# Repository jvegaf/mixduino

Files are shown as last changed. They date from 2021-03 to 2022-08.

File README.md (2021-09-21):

# Mixduino
An evolution of Open Source DJ MIDI Controllers
## Main Features
- 3 Complete Channels Mixer 
- 2 Decks  
- Library Browser with song preview function
- 16 Control Pads with RGB Leds (8/Deck)
- FX Controls
- 75 mm pitch/tempo controls
- Multitouch bars instead Jog Wheels
- Compact size enought to take in a backpack (360x260mm) 
## Note
This project actually are WIP.
## Previews
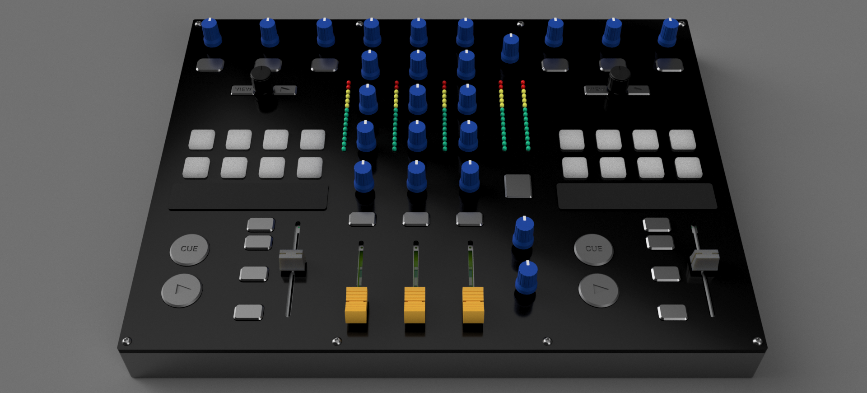
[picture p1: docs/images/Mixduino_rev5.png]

</br>
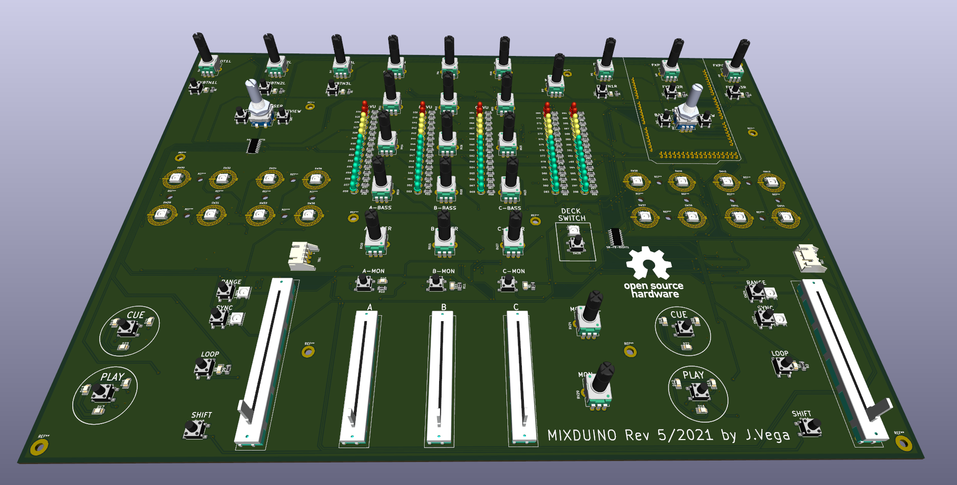
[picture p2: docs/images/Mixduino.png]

</br>
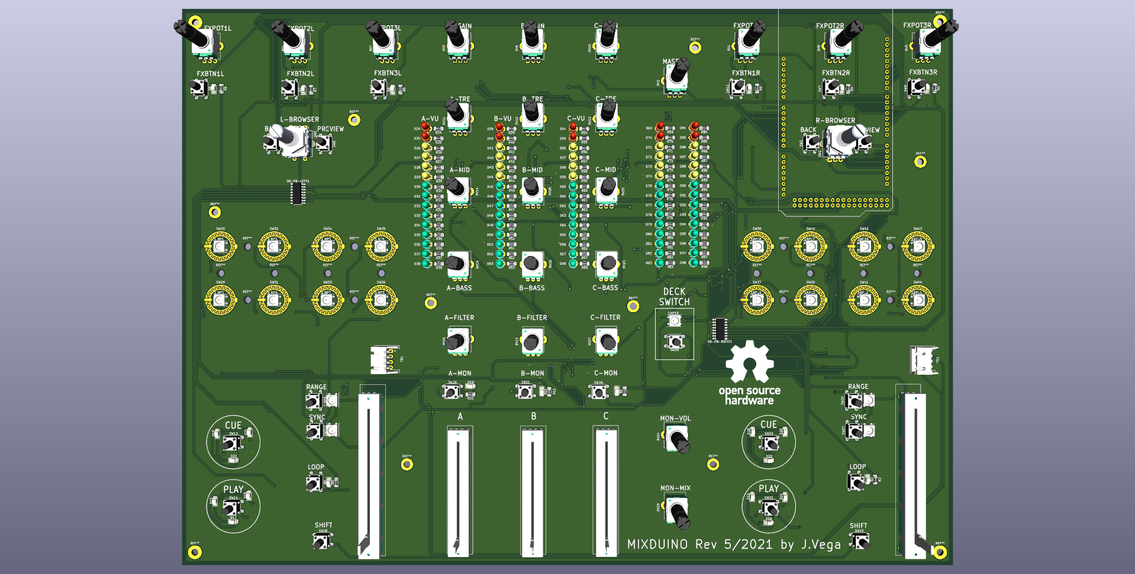
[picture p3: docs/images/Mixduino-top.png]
previewTop

</br>
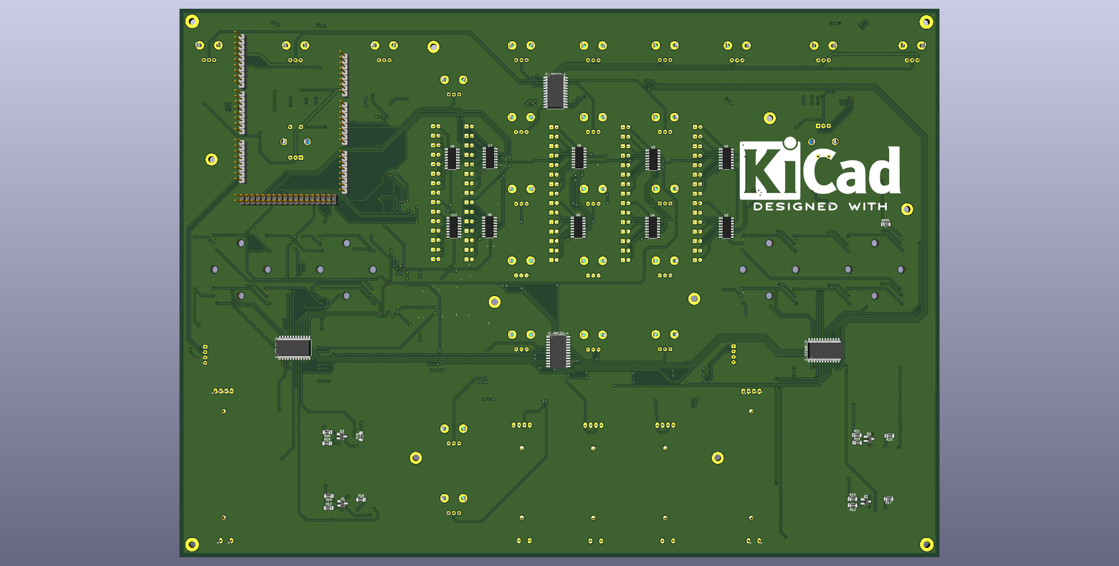
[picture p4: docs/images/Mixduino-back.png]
previewBack

</br>
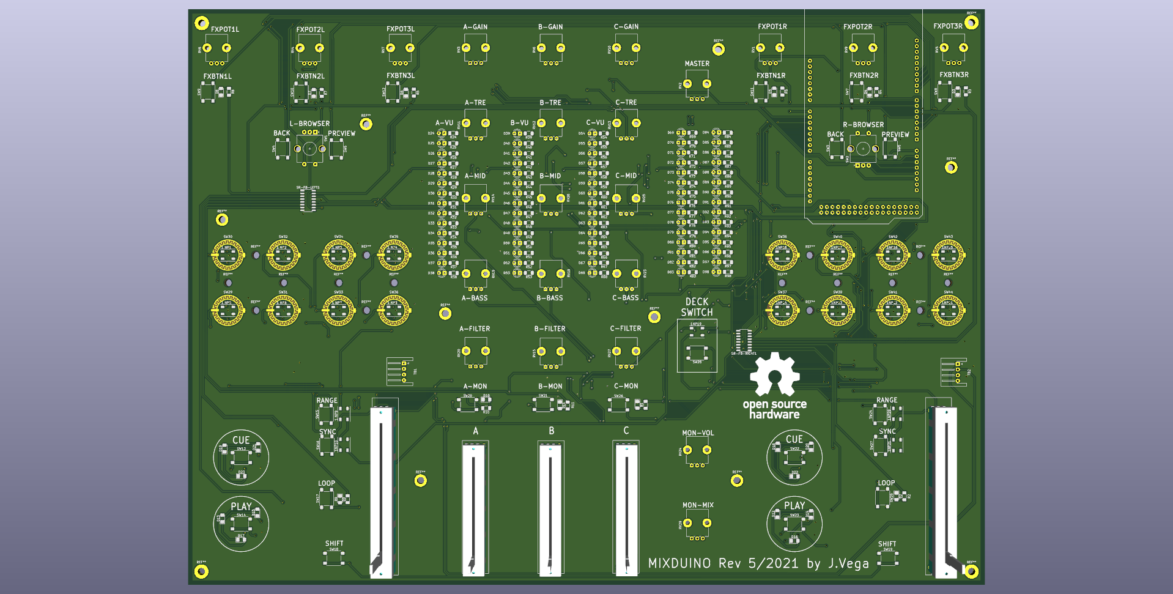
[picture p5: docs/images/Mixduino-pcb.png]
previewPCB


.
.
.

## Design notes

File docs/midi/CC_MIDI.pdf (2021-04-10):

Tabla de CC-MIDI | Carlos Mariño

www.carlosmarino.es

Tabla de Controladores MIDI

He dejado las nomenclaturas en inglés, tal y como os aparecerán en los

Manuales de vuestros instrumentos.

Cambios de Control y Modos (Status Bytes 176-191)

Número de Control

Función del Controlador

3rd Byte Value

Decimal | Binario | Hex | Valor

Usado
como
0 | 00000000 | 00 | Bank Select | 0-127 | MSB
1 | 00000001 | 01 | Modulation Wheel or Lever | 0-127 | MSB
2 | 00000010 | 02 | Breath Controller | 0-127 | MSB
3 | 00000011 | 03 | Indefinido | 0-127 | MSB
4 | 00000100 | 04 | Foot Controller | 0-127 | MSB
5 | 00000101 | 05 | Portamento Time | 0-127 | MSB
6 | 00000110 | 06 | Data Entry MSB | 0-127 | MSB
7 | 00000111 | 07 | Channel Volume (antes Main Volume) | 0-127 | MSB
8 | 00001000 | 08 | Balance | 0-127 | MSB
9 | 00001001 | 09 | Indefinido | 0-127 | MSB
10 | 00001010 | 0A | Pan | 0-127 | MSB
11 | 00001011 | 0B | Expression Controller | 0-127 | MSB
12 | 00001100 | 0C | Effect Control 1 | 0-127 | MSB
13 | 00001101 | 0D | Effect Control 2 | 0-127 | MSB
14 | 00001110 | 0E | Indefinido | 0-127 | MSB
15 | 00001111 | 0F | Indefinido | 0-127 | MSB
16 | 00010000 | 10 | Controlador de propósito general 1 | 0-127 | MSB
17 | 00010001 | 11 | Controlador de propósito general 2 | 0-127 | MSB
18 | 00010010 | 12 | Controlador de propósito general 3 | 0-127 | MSB
19 | 00010011 | 13 | Controlador de propósito general 4 | 0-127 | MSB

20 | 00010100 | 14 | Indefinido | 0-127 | MSB
21 | 00010101 | 15 | Indefinido | 0-127 | MSB
22 | 00010110 | 16 | Indefinido | 0-127 | MSB
23 | 00010111 | 17 | Indefinido | 0-127 | MSB
24 | 00011000 | 18 | Indefinido | 0-127 | MSB
25 | 00011001 | 19 | Indefinido | 0-127 | MSB
26 | 00011010 | 1A | Indefinido | 0-127 | MSB
27 | 00011011 | 1B | Indefinido | 0-127 | MSB
28 | 00011100 | 1C | Indefinido | 0-127 | MSB
29 | 00011101 | 1D | Indefinido | 0-127 | MSB
30 | 00011110 | 1E | Indefinido | 0-127 | MSB
31 | 00011111 | 1F | Indefinido | 0-127 | MSB
32 | 00100000 | 20 | LSB for Control 0 (Bank Select) | 0-127 | LSB
33 | 00100001 | 21 | LSB for Control 1 (Modulation Wheel or Lever) | 0-127 | LSB
34 | 00100010 | 22 | LSB for Control 2 (Breath Controller) | 0-127 | LSB
35 | 00100011 | 23 | LSB for Control 3 (Indefinido) | 0-127 | LSB
36 | 00100100 | 24 | LSB for Control 4 (Foot Controller) | 0-127 | LSB
37 | 00100101 | 25 | LSB for Control 5 (Portamento Time) | 0-127 | LSB
38 | 00100110 | 26 | LSB for Control 6 (Data Entry) | 0-127 | LSB
39 | 00100111 | 27 | LSB for Control 7 (Channel Volume, antes Main Volume) | 0-127 | LSB
40 | 00101000 | 28 | LSB for Control 8 (Balance) | 0-127 | LSB
41 | 00101001 | 29 | LSB for Control 9 (Indefinido) | 0-127 | LSB
42 | 00101010 | 2A | LSB for Control 10 (Pan) | 0-127 | LSB
43 | 00101011 | 2B | LSB for Control 11 (Expression Controller) | 0-127 | LSB
44 | 00101100 | 2C | LSB for Control 12 (Effect control 1) | 0-127 | LSB
45 | 00101101 | 2D | LSB for Control 13 (Effect control 2) | 0-127 | LSB

46 | 00101110 | 2E | LSB for Control 14 (Indefinido) | 0-127 | LSB
47 | 00101111 | 2F | LSB for Control 15 (Indefinido) | 0-127 | LSB
48 | 00110000 | 30 | LSB for Control 16 (Controlador de propósito general 1) | 0-127 | LSB
49 | 00110001 | 31 | LSB for Control 17 (Controlador de propósito general 2) | 0-127 | LSB
50 | 00110010 | 32 | LSB for Control 18 (Controlador de propósito general 3) | 0-127 | LSB
51 | 00110011 | 33 | LSB for Control 19 (Controlador de propósito general 4) | 0-127 | LSB
52 | 00110100 | 34 | LSB for Control 20 (Indefinido) | 0-127 | LSB
53 | 00110101 | 35 | LSB for Control 21 (Indefinido) | 0-127 | LSB
54 | 00110110 | 36 | LSB for Control 22 (Indefinido) | 0-127 | LSB
55 | 00110111 | 37 | LSB for Control 23 (Indefinido) | 0-127 | LSB
56 | 00111000 | 38 | LSB for Control 24 (Indefinido) | 0-127 | LSB
57 | 00111001 | 39 | LSB for Control 25 (Indefinido) | 0-127 | LSB
58 | 00111010 | 3A | LSB for Control 26 (Indefinido) | 0-127 | LSB
59 | 00111011 | 3B | LSB for Control 27 (Indefinido) | 0-127 | LSB
60 | 00111100 | 3C | LSB for Control 28 (Indefinido) | 0-127 | LSB
61 | 00111101 | 3D | LSB for Control 29 (Indefinido) | 0-127 | LSB
62 | 00111110 | 3E | LSB for Control 30 (Indefinido) | 0-127 | LSB
63 | 00111111 | 3F | LSB for Control 31 (Indefinido) | 0-127 | LSB
64 | 01000000 | 40 | Damper Pedal on/off (Sustain) | ≤63 off, ≥64 on | ---
65 | 01000001 | 41 | Portamento On/Off | ≤63 off, ≥64 on | ---
66 | 01000010 | 42 | Sostenuto On/Off | ≤63 off, ≥64 on | ---
67 | 01000011 | 43 | Soft Pedal On/Off | ≤63 off, ≥64 on | ---
68 | 01000100 | 44 | Legato Footswitch | ≤63 Normal, ≥64 Legato | ---
69 | 01000101 | 45 | Hold 2 | ≤63 off, ≥64 on | ---

70 | 01000110 | 46 | Controlador de sonido 1 (default: Sound
Variation) | 0-127 | LSB
71 | 01000111 | 47 | Controlador de sonido 2 (default: Timbre/Harmonic Intens.) | 0-127 | LSB
72 | 01001000 | 48 | Controlador de sonido 3 (default: Release Time) | 0-127 | LSB
73 | 01001001 | 49 | Controlador de sonido 4 (default: Attack Time) | 0-127 | LSB
74 | 01001010 | 4A | Controlador de sonido 5 (default: Brightness) | 0-127 | LSB
75 | 01001011 | 4B | Controlador de sonido 6 (default: Decay Time - ver MMA RP-021) | 0-127 | LSB
76 | 01001100 | 4C | Controlador de sonido 7 (default: Vibrato Rate - ver MMA RP-021) | 0-127 | LSB
77 | 01001101 | 4D | Controlador de sonido 8 (default: Vibrato Profundidad - ver MMA RP-021) | 0-127 | LSB
78 | 01001110 | 4E | Controlador de sonido 9 (default: Vibrato Delay - ver MMA RP-021) | 0-127 | LSB
79 | 01001111 | 4F | Controlador de sonido 10 (default Indefinido - ver MMA RP-021) | 0-127 | LSB
80 | 01010000 | 50 | Controlador de propósito general 5 | 0-127 | LSB
81 | 01010001 | 51 | Controlador de propósito general 6 | 0-127 | LSB
82 | 01010010 | 52 | Controlador de propósito general 7 | 0-127 | LSB
83 | 01010011 | 53 | Controlador de propósito general 8 | 0-127 | LSB
84 | 01010100 | 54 | Portamento Control | 0-127 | LSB
85 | 01010101 | 55 | Indefinido | --- | ---
86 | 01010110 | 56 | Indefinido | --- | ---
87 | 01010111 | 57 | Indefinido | --- | ---
88 | 01011000 | 58 | High Resolution Velocity Prefix | 0-127 | LSB
89 | 01011001 | 59 | Indefinido | --- | ---

90 | 01011010 | 5A | Indefinido | --- | ---
91 | 01011011 | 5B | Efectos 1 Profundidad (default: Nivel de envío de reverb - ver MMA RP-023) (anteriormente profundidad de efectos externos) | 0-127 | ---
92 | 01011100 | 5C | Efectos 2 Profundidad (antes Tremolo Profundidad) | 0-127 | ---
93 | 01011101 | 5D | Efectos 3 Profundidad (default: Nivel de Chorus - ver MMA RP-023) (anteriormente profundidad de efectos externos) | 0-127 | ---
94 | 01011110 | 5E | Efectos 4 Profundidad (antes Celeste [Detune] Profundidad) | 0-127 | ---
95 | 01011111 | 5F | Efectos 5 Profundidad (antes Phaser Profundidad) | 0-127 | ---
96 | 01100000 | 60 | Data Increment (Data Entry +1) (ver MMA RP-018) | N/A | ---
97 | 01100001 | 61 | Data Decrement (Data Entry -1) (ver MMA RP-018) | N/A | ---
98 | 01100010 | 62 | Número de parámetro no registrado (NRPN) - LSB | 0-127 | LSB
99 | 01100011 | 63 | Número de parámetro no registrado (NRPN) - MSB | 0-127 | MSB
100 | 01100100 | 64 | Número de parámetro registrado (RPN) -LSB* | 0-127 | LSB
101 | 01100101 | 65 | Número de parámetro registrado (RPN) -MSB* | 0-127 | MSB
102 | 01100110 | 66 | Indefinido | --- | ---
103 | 01100111 | 67 | Indefinido | --- | ---
104 | 01101000 | 68 | Indefinido | --- | ---
105 | 01101001 | 69 | Indefinido | --- | ---
106 | 01101010 | 6A | Indefinido | --- | ---

107 | 01101011 | 6B | Indefinido | --- | ---
108 | 01101100 | 6C | Indefinido | --- | ---
109 | 01101101 | 6D | Indefinido | --- | ---
110 | 01101110 | 6E | Indefinido | --- | ---
111 | 01101111 | 6F | Indefinido | --- | ---
112 | 01110000 | 70 | Indefinido | --- | ---
113 | 01110001 | 71 | Indefinido | --- | ---
114 | 01110010 | 72 | Indefinido | --- | ---
115 | 01110011 | 73 | Indefinido | --- | ---
116 | 01110100 | 74 | Indefinido | --- | ---
117 | 01110101 | 75 | Indefinido | --- | ---
118 | 01110110 | 76 | Indefinido | --- | ---
119 | 01110111 | 77 | Indefinido | --- | ---
Nota: | Los números de controlador 120-127 están reservados para los mensajes de modo de canal, que, en lugar de controlar los parámetros de sonido, afectan el modo de funcionamiento del canal. (Ver también la Tabla 1.)
120 | 01111000 | 78 | [Mensaje en modo canal] All Sound Off | 0 | ---
121 | 01111001 | 79 | [Mensaje en modo canal] Reset All Controllers (Ver MMA RP-015) | 0 | ---
122 | 01111010 | 7A | [Mensaje en modo canal] Local Control On/Off | 0 off, 127 on | ---
123 | 01111011 | 7B | [Mensaje en modo canal] All Notes Off | 0 | ---
124 | 01111100 | 7C | [Mensaje en modo canal] Omni Mode Off (+ all notes off) | 0 | ---
125 | 01111101 | 7D | [Mensaje en modo canal] Omni Mode On (+ all notes off) | 0

126 | 01111110 | 7E | [Mensaje en modo canal] Mono Mode On (+ poly off, + all notes off) | Nota: Esto equivale a la cantidad de canales, o cero si la cantidad de canales es igual a la cantidad de voces en el receptor. | ---
127 | 01111111 | 7F | [Mensaje en modo canal] Poly Mode On (+ mono off, +all notes off) | 0 | ---

Números de parámetros registrados

Para establecer o cambiar el valor de un parámetro registrado:

1. Envía dos mensajes de cambio de control usando los números de control 101 (65H) y 100 (64H) para seleccionar el número de parámetro registrado deseado, como se indica en la siguiente tabla.
2. Para establecer el parámetro registrado seleccionado en un valor específico, envíe un mensaje de cambio de control al controlador MSB de entrada de datos (número de control 6). Si el parámetro registrado seleccionado requiere que se establezca el LSB, envíe otro mensaje de cambio de control al controlador LSB de entrada de datos (número de control 38).
3. Para realizar un ajuste relativo al valor actual del parámetro registrado seleccionado, usa los controladores Data Increment o Data Decrement (Números de control 96 y 97).
Número de Parámetro | Función de Parámetro | Valor de Entrada
MSB: Control 101 (65H) Value | LSB: Control 100 (64H) Value
00H | 00H | Pitch Bend Sensitivity | MSB = +/- semitones LSB =+/--cents
| 01H | Channel Fine Tuning (antes Fine Tuning - ver MMA RP-022) | Resolution 100/8192 cents 00H 00H = -100 cents 40H 00H = A440 7FH 7FH = +100 cents

| 02H | Channel Coarse Tuning (antes Coarse Tuning - ver MMA RP-022) | Only MSB used Resolution 100 cents 00H = -6400 cents 40H = A440 7FH = +6300 cents
| 03H | Tuning Program Change | Tuning Program Number
| 04H | Tuning Bank Select | Tuning Bank Number
| 05H | Modulation Profundidad Range (ver MMA General MIDI Level 2 Specification) | For GM2, defined in GM2 Specification. For other systems, defined by manufacturer
... | ... | Todos RESERVADOS para la futura definición de MMA | ...
3DH (61) | Three Dimensional Controlador de sonidos
| 00H | AZIMUTH ANGLE | Ver RP-049
| 01H | ELEVATION ANGLE | Ver RP-049
| 02H | GAIN | Ver RP-049
| 03H | DISTANCE RATIO | Ver RP-049
| 04H | MAXIMUM DISTANCE | Ver RP-049
| 05H | GAIN AT MAXIMUM DISTANCE | Ver RP-049
| 06H | REFERENCE DISTANCE RATIO | Ver RP-049
| 07H | PAN SPREAD ANGLE | Ver RP-049
| 08H | ROLL ANGLE | Ver RP-049
... | ... | All RESERVED for future MMA Definition | ...
7FH | 7FH | Número de función nulo para RPN / NRPN | Al establecer RPN en 7FH, 7FH se deshabilitarán los controles de entrada de datos, incremento de datos y reducción de datos hasta que se seleccione un nuevo RPN o NRPN.

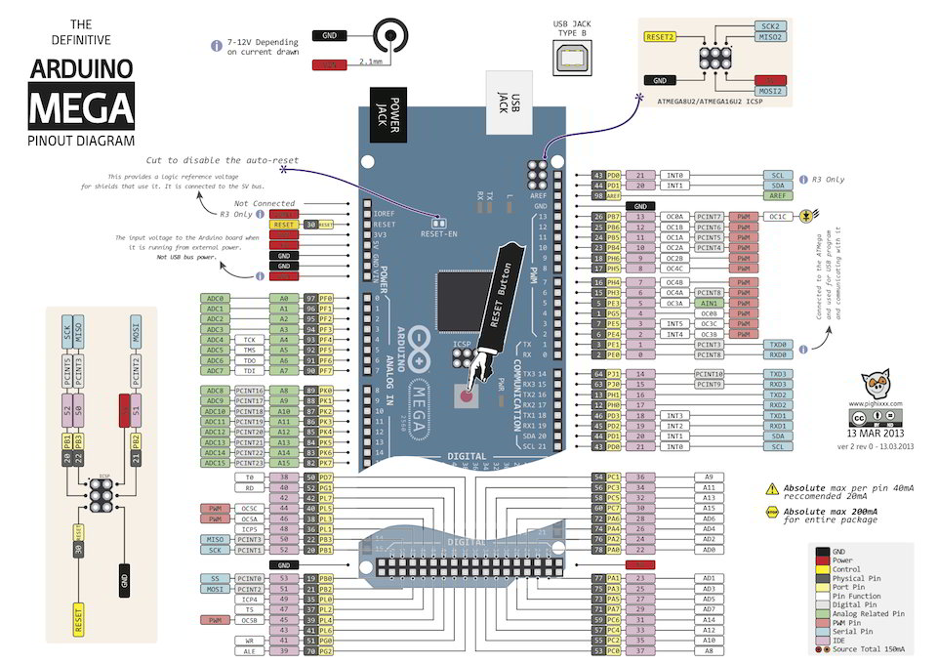
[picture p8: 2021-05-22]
docs/pinouts/ardunio_mega_pinout.jpg

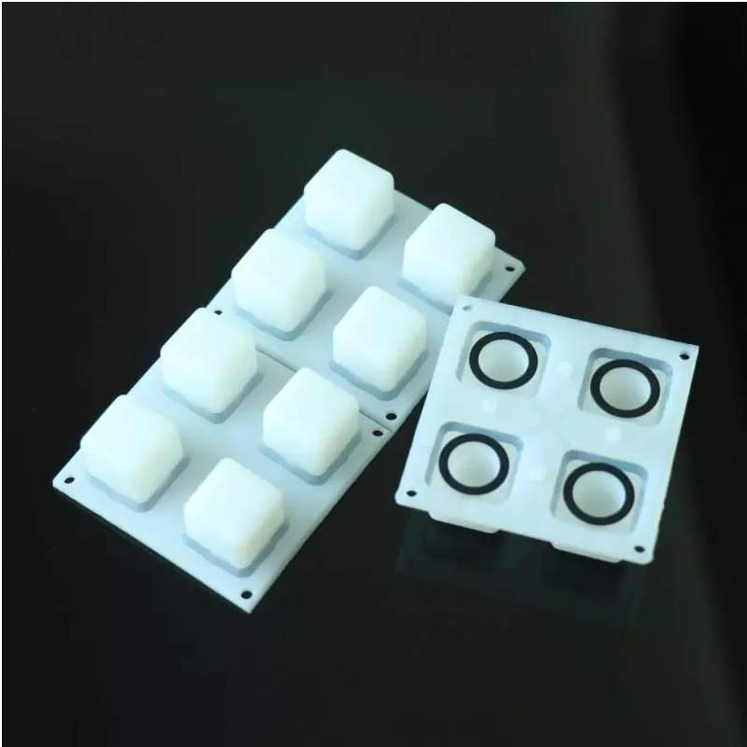
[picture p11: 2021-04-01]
docs/pads/pads.png

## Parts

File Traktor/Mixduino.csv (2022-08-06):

#
#Page 0: (Mixduino R5)
#
Device | Id | Type | TraktorCommand | AssignmentExpression | ConditionExpression | Interaction | MappedTo | Comment
0 | 65 | In | Volume Adjust | Deck A |  | Fader / Knob - Direct | Ch11.CC.012
0 | 198 | Out | Monitor Cue On [Off; On] | Deck A |  | LED - Output | Ch06.Note.D#2
0 | 199 | Out | Monitor Cue On [Off; On] | Deck B |  | LED - Output | Ch06.Note.E2
0 | 200 | Out | Monitor Cue On [Off; On] | Deck C |  | LED - Output | Ch06.Note.F2
0 | 190 | In | Deck Focus Selector = B | Global | M1=1 | Button - Direct | Ch06.Note.G-1
0 | 191 | In | Deck Focus Selector = C | Global | M1=0 | Button - Direct | Ch06.Note.G-1
0 | 215 | Out | Sync On [Off; On] | Deck A |  | LED - Output | Ch14.CC.009
0 | 100 | Out | Hotcue 2 Type [None; Loop] | Deck C | M1=1 | LED - Output | Ch14.CC.011
0 | 101 | Out | Hotcue 3 Type [None; Loop] | Deck C | M1=1 | LED - Output | Ch14.CC.012
0 | 223 | Out | Sync On [Off; On] | Deck C | M1=1 | LED - Output | Ch14.CC.020
0 | 219 | Out | Sync On [Off; On] | Deck B | M1=0 | LED - Output | Ch14.CC.020
0 | 220 | Out | Tempo Range Selector [8%; 100%] | Deck B | M1=0 | LED - Output | Ch14.CC.019
0 | 390 | In | Tempo Range Selector = 10% | Deck A | Tempo Range [Deck A]=8% | Button - Direct | Ch05.Note.F-1
0 | 391 | In | Tempo Range Selector = 100% | Deck A | Tempo Range [Deck A]=10% | Button - Direct | Ch05.Note.F-1
0 | 392 | In | Tempo Range Selector = 8% | Deck A | Tempo Range [Deck A]=100% | Button - Direct | Ch05.Note.F-1
0 | 393 | In | Tempo Range Selector = 10% | Deck B | Tempo Range [Deck B]=8% AND M1=0 | Button - Direct | Ch06.Note.D-1
0 | 394 | In | Tempo Range Selector = 100% | Deck B | Tempo Range [Deck B]=10% AND M1=0 | Button - Direct | Ch06.Note.D-1
0 | 395 | In | Tempo Range Selector = 8% | Deck B | Tempo Range [Deck B]=100% AND M1=0 | Button - Direct | Ch06.Note.D-1
0 | 396 | In | Tempo Range Selector = 10% | Deck C | Tempo Range [Deck C]=8% AND M1=1 | Button - Direct | Ch06.Note.D-1
0 | 397 | In | Tempo Range Selector = 100% | Deck C | Tempo Range [Deck C]=10% AND M1=1 | Button - Direct | Ch06.Note.D-1
0 | 398 | In | Tempo Range Selector = 8% | Deck C | Tempo Range [Deck C]=100% AND M1=1 | Button - Direct | Ch06.Note.D-1
0 | 399 | In | Tempo Bend [Hold] = Up | Deck A | M2=1 | Button - Hold | Ch05.Note.F-1
0 | 400 | In | Tempo Bend [Hold] = Down | Deck A | M2=1 | Button - Hold | Ch05.Note.E-1
0 | 401 | In | Tempo Bend [Hold] = Up | Deck B | M2=1 AND M1=0 | Button - Hold | Ch06.Note.D-1
0 | 402 | In | Tempo Bend [Hold] = Down | Deck B | M2=1 AND M1=0 | Button - Hold | Ch06.Note.F#-1
0 | 403 | In | Tempo Bend [Hold] = Up | Deck C | M2=1 AND M1=1 | Button - Hold | Ch06.Note.D-1
0 | 404 | In | Tempo Bend [Hold] = Down | Deck C | M2=1 AND M1=1 | Button - Hold | Ch06.Note.F#-1
0 | 384 | Out | Tempo Range Selector [8%; 100%] | Deck C | M1=1 | LED - Output | Ch14.CC.019
0 | 387 | Out | Tempo Range Selector [8%; 100%] | Deck A |  | LED - Output | Ch14.CC.008
0 | 192 | Out | Deck Focus Selector [B; D] | Global |  | LED - Output | Ch14.CC.018
0 | 131 | In | Select Up/Down (Browser List) | Global | M2=0 | Encoder - Relative | Ch01.CC.014_I
0 | 132 | In | Select Up/Down (Browser Tree) | Global | M2=1 | Encoder - Relative | Ch01.CC.014_I
0 | 66 | In | Mixer FX Adjust | Deck A |  | Fader / Knob - Direct | Ch11.CC.023
0 | 67 | In | Mixer FX Adjust | Deck B |  | Fader / Knob - Direct | Ch11.CC.022
0 | 68 | In | Mixer FX Adjust | Deck C |  | Fader / Knob - Direct | Ch11.CC.014
0 | 69 | In | Low Adjust | Deck A |  | Fader / Knob - Direct | Ch11.CC.016
0 | 70 | In | Low Adjust | Deck B |  | Fader / Knob - Direct | Ch11.CC.018
0 | 71 | In | Low Adjust | Deck C |  | Fader / Knob - Direct | Ch11.CC.021
0 | 72 | In | Mid Adjust | Deck A |  | Fader / Knob - Direct | Ch11.CC.017
0 | 73 | In | Mid Adjust | Deck B |  | Fader / Knob - Direct | Ch11.CC.019
0 | 74 | In | Mid Adjust | Deck C |  | Fader / Knob - Direct | Ch11.CC.020
0 | 75 | In | Gain Adjust (Mixer) | Deck C |  | Fader / Knob - Direct | Ch11.CC.005
0 | 76 | In | Gain Adjust (Mixer) | Deck B |  | Fader / Knob - Direct | Ch11.CC.004
0 | 77 | In | Gain Adjust (Mixer) | Deck A |  | Fader / Knob - Direct | Ch11.CC.003
0 | 58 | In | Tempo Adjust | Deck B | M1=0 | Fader / Knob - Direct | Ch11.CC.013_I
0 | 59 | In | Tempo Adjust | Deck C | M1=1 | Fader / Knob - Direct | Ch11.CC.013_I
0 | 60 | In | Tempo Adjust | Deck A |  | Fader / Knob - Direct | Ch11.CC.024_I
0 | 61 | In | Monitor Mix Adjust | Global |  | Fader / Knob - Direct | Ch11.CC.025
0 | 62 | In | Monitor Volume Adjust | Global |  | Fader / Knob - Direct | Ch11.CC.015
0 | 63 | In | Volume Adjust | Deck C |  | Fader / Knob - Direct | Ch11.CC.026
0 | 64 | In | Volume Adjust | Deck B |  | Fader / Knob - Direct | Ch11.CC.011
0 | 84 | In | High Adjust | Deck C |  | Fader / Knob - Direct | Ch11.CC.010
0 | 85 | In | High Adjust | Deck B |  | Fader / Knob - Direct | Ch11.CC.009
0 | 86 | In | High Adjust | Deck A |  | Fader / Knob - Direct | Ch11.CC.008
0 | 87 | In | Master Volume Adjust | Global |  | Fader / Knob - Direct | Ch11.CC.028
0 | 88 | Out | Hotcue 2 Type [None; Loop] | Deck A |  | LED - Output | Ch14.CC.001
0 | 93 | Out | Hotcue 3 Type [None; Loop] | Deck A |  | LED - Output | Ch14.CC.002
0 | 94 | Out | Hotcue 4 Type [None; Loop] | Deck A |  | LED - Output | Ch14.CC.003
0 | 95 | Out | Hotcue 5 Type [None; Loop] | Deck A |  | LED - Output | Ch14.CC.004
0 | 96 | Out | Hotcue 6 Type [None; Loop] | Deck A |  | LED - Output | Ch14.CC.005
0 | 97 | Out | Hotcue 7 Type [None; Loop] | Deck A |  | LED - Output | Ch14.CC.006
0 | 98 | Out | Hotcue 8 Type [None; Loop] | Deck A |  | LED - Output | Ch14.CC.007
0 | 99 | Out | Hotcue 1 Type [None; Loop] | Deck A |  | LED - Output | Ch14.CC.000
0 | 102 | Out | Hotcue 4 Type [None; Loop] | Deck C | M1=1 | LED - Output | Ch14.CC.013
0 | 103 | Out | Hotcue 5 Type [None; Loop] | Deck C | M1=1 | LED - Output | Ch14.CC.014
0 | 105 | Out | Hotcue 6 Type [None; Loop] | Deck C | M1=1 | LED - Output | Ch14.CC.015
0 | 106 | Out | Hotcue 7 Type [None; Loop] | Deck C | M1=1 | LED - Output | Ch14.CC.016
0 | 107 | Out | Hotcue 8 Type [None; Loop] | Deck C | M1=1 | LED - Output | Ch14.CC.017
0 | 108 | Out | Hotcue 1 Type [None; Loop] | Deck C | M1=1 | LED - Output | Ch14.CC.010
0 | 182 | Out | Hotcue 2 Type [None; Loop] | Deck B | M1=0 | LED - Output | Ch14.CC.011
0 | 183 | Out | Hotcue 3 Type [None; Loop] | Deck B | M1=0 | LED - Output | Ch14.CC.012
0 | 184 | Out | Hotcue 4 Type [None; Loop] | Deck B | M1=0 | LED - Output | Ch14.CC.013
0 | 185 | Out | Hotcue 5 Type [None; Loop] | Deck B | M1=0 | LED - Output | Ch14.CC.014
0 | 186 | Out | Hotcue 6 Type [None; Loop] | Deck B | M1=0 | LED - Output | Ch14.CC.015
0 | 187 | Out | Hotcue 7 Type [None; Loop] | Deck B | M1=0 | LED - Output | Ch14.CC.016
0 | 188 | Out | Hotcue 8 Type [None; Loop] | Deck B | M1=0 | LED - Output | Ch14.CC.017
0 | 189 | Out | Hotcue 1 Type [None; Loop] | Deck B | M1=0 | LED - Output | Ch14.CC.010
0 | 110 | In | Play/Pause (Deck Common) [Toggle] | Deck A |  | Button - Toggle | Ch05.Note.F#-1
0 | 112 | In | Cue [Hold] | Deck A |  | Button - Hold | Ch05.Note.G-1
0 | 114 | In | Sync On [Toggle] | Deck A |  | Button - Toggle | Ch05.Note.E-1
0 | 133 | In | Play/Pause (Deck Common) [Toggle] | Deck B | M1=0 | Button - Toggle | Ch06.Note.C#-1
0 | 134 | In | Cue [Hold] | Deck B | M1=0 | Button - Hold | Ch06.Note.C-1
0 | 135 | In | Sync On [Toggle] | Deck B | M1=0 | Button - Toggle | Ch06.Note.F#-1
0 | 136 | In | Play/Pause (Deck Common) [Toggle] | Deck C | M1=1 | Button - Toggle | Ch06.Note.C#-1
0 | 137 | In | Cue [Hold] | Deck C | M1=1 | Button - Hold | Ch06.Note.C-1
0 | 138 | In | Sync On [Toggle] | Deck C | M1=1 | Button - Toggle | Ch06.Note.F#-1
0 | 118 | In | Only Browser On [Toggle] | Global |  | Button - Toggle | Ch07.Note.A-1
0 | 263 | In | Only Browser On = Off | Global |  | Button - Direct | Ch07.Note.E-1
0 | 265 | In | Only Browser On = Off | Global |  | Button - Direct | Ch07.Note.D#-1
0 | 120 | In | Modifier #1 = 1 | Global | M1=0 | Button - Direct | Ch06.Note.G-1 | switch deck B - C
0 | 125 | In | Modifier #1 = 0 | Global | M1=1 | Button - Direct | Ch06.Note.G-1
0 | 126 | In | Modifier #2 [Hold] = 1 | Global |  | Button - Hold | Ch05.Note.D-1 | shift
0 | 146 | In | Load Selected (Deck Common) | Deck A |  | Button - Trigger | Ch07.Note.E-1
0 | 150 | In | Load Selected (Deck Common) | Deck B | M1=0 | Button - Trigger | Ch07.Note.D#-1
0 | 154 | In | Load Selected (Deck Common) | Deck C | M1=1 | Button - Trigger | Ch07.Note.D#-1
0 | 179 | In | Monitor Cue On [Toggle] | Deck A |  | Button - Toggle | Ch05.Note.C#-1
0 | 181 | In | Monitor Cue On [Toggle] | Deck C |  | Button - Toggle | Ch06.Note.F-1
0 | 180 | In | Monitor Cue On [Toggle] | Deck B |  | Button - Toggle | Ch05.Note.C-1
0 | 258 | Out | Deck Is Loaded [Off; On] | Deck A |  | LED - Output | Ch01.Note.C3
0 | 271 | Out | Deck Is Loaded [Off; On] | Deck B | M1=0 | LED - Output | Ch01.Note.C#3
0 | 279 | Out | Deck Is Loaded [Off; On] | Deck C | M1=1 | LED - Output | Ch01.Note.C#3
0 | 283 | Out | Beat Phase [-0.1; 0.1] | Deck A |  | LED - Output | Ch01.Note.C3
0 | 286 | Out | Beat Phase [-0.1; 0.1] | Deck B | M1=0 | LED - Output | Ch01.Note.C#3
0 | 288 | Out | Beat Phase [-0.1; 0.1] | Deck C | M1=1 | LED - Output | Ch01.Note.C#3
0 | 290 | Out | Loop Active On [Off; On] | Deck A |  | LED - Output | Ch06.Note.E3
0 | 293 | Out | Loop Active On [Off; On] | Deck B | M1=0 | LED - Output | Ch06.Note.F3
0 | 295 | Out | Loop Active On [Off; On] | Deck C | M1=1 | LED - Output | Ch06.Note.F3
0 | 296 | In | Loop Active On [Toggle] | Deck A |  | Button - Toggle | Ch05.Note.D#-1
0 | 299 | In | Loop Active On [Toggle] | Deck B | M1=0 | Button - Toggle | Ch06.Note.D#-1
0 | 301 | In | Loop Active On [Toggle] | Deck C | M1=1 | Button - Toggle | Ch06.Note.D#-1
0 | 308 | In | Loop Size Select + Set = 4 | Deck A | Is In Active Loop [Deck A]=Off | Button - Direct | Ch05.Note.D#-1
0 | 311 | In | Loop Size Select + Set = 4 | Deck B | M1=0 AND Is In Active Loop [Deck B]=Off | Button - Direct | Ch06.Note.D#-1
0 | 313 | In | Loop Size Select + Set = 4 | Deck C | M1=1 AND Is In Active Loop [Deck C]=Off | Button - Direct | Ch06.Note.D#-1
0 | 334 | In | Jog Turn | Deck A |  | Fader / Knob - Relative | Ch07.CC.014 | touchbar left
0 | 336 | In | Jog Turn | Deck B | M1=0 | Fader / Knob - Relative | Ch07.CC.015 | touchbar right
0 | 338 | In | Jog Turn | Deck C | M1=1 | Fader / Knob - Relative | Ch07.CC.015 | touchbar right
0 | 405 | Out | Deck Pre-Fader Level (L+R) [0; 1] | Deck A |  | LED - Output | Ch12.CC.000
0 | 406 | Out | Deck Pre-Fader Level (L+R) [0; 1] | Deck B |  | LED - Output | Ch12.CC.001
0 | 407 | Out | Deck Pre-Fader Level (L+R) [0; 1] | Deck C |  | LED - Output | Ch12.CC.002
0 | 408 | Out | Master Out Level (L) [0; 1] | Global |  | LED - Output | Ch12.CC.003
0 | 409 | Out | Master Out Level (R) [0; 1] | Global |  | LED - Output | Ch12.CC.004
0 | 428 | Out | Deck Is Loaded [Off; On] | Deck A |  | LED - Output | Ch01.Note.D3
0 | 431 | Out | Deck Is Loaded [Off; On] | Deck B | M1=0 | LED - Output | Ch01.Note.D#3
0 | 433 | Out | Deck Is Loaded [Off; On] | Deck C | M1=1 | LED - Output | Ch01.Note.D#3
0 | 434 | In | Dry/Wet Adjust (FX Unit) | FX Unit 1 |  | Fader / Knob - Direct | Ch11.CC.000
0 | 435 | In | Knob 1 | FX Unit 1 |  | Fader / Knob - Direct | Ch11.CC.001
0 | 436 | In | Knob 2 | FX Unit 1 |  | Fader / Knob - Direct | Ch11.CC.002
0 | 437 | In | Button 1 [Toggle] | FX Unit 1 |  | Button - Toggle | Ch07.Note.F-1
0 | 438 | Out | Button 1 [Off; On] | FX Unit 1 |  | LED - Output | Ch06.Note.G2
0 | 439 | In | Button 2 [Toggle] | FX Unit 1 |  | Button - Toggle | Ch07.Note.F#-1
0 | 440 | Out | Button 2 [Off; On] | FX Unit 1 |  | LED - Output | Ch06.Note.G#2
0 | 441 | In | Dry/Wet Adjust (FX Unit) | FX Unit 2 |  | Fader / Knob - Direct | Ch11.CC.027
0 | 442 | In | Knob 1 | FX Unit 2 |  | Fader / Knob - Direct | Ch11.CC.006
0 | 443 | In | Knob 2 | FX Unit 2 |  | Fader / Knob - Direct | Ch11.CC.007
0 | 444 | In | Button 1 [Toggle] | FX Unit 2 |  | Button - Toggle | Ch07.Note.C-1
0 | 445 | Out | Button 1 [Off; On] | FX Unit 2 |  | LED - Output | Ch06.Note.A#2
0 | 446 | In | Button 2 [Toggle] | FX Unit 2 |  | Button - Toggle | Ch07.Note.C#-1
0 | 447 | Out | Button 2 [Off; On] | FX Unit 2 |  | LED - Output | Ch06.Note.B2
#
#Page 1: (Mixduino Pads)
#
1 | 1 | In | Select/Set+Store Hotcue [Hold] = Hotcue1 | Deck A |  | Button - Hold | Ch05.Note.C0
1 | 37 | In | Tempo Bend [Hold] = Down | Deck A |  | Button - Hold | Ch05.Note.E2
1 | 38 | In | Tempo Bend [Hold] = Up | Deck A |  | Button - Hold | Ch05.Note.F2
1 | 17 | In | Loop Size Selector = 1/2 | Deck A |  | Button - Direct | Ch05.Note.G#0
1 | 18 | In | Loop Size Selector = 1 | Deck A |  | Button - Direct | Ch05.Note.A0
1 | 19 | In | Loop Size Selector = 2 | Deck A |  | Button - Direct | Ch05.Note.A#0
1 | 20 | In | Loop Size Selector = 4 | Deck A |  | Button - Direct | Ch05.Note.B0
1 | 21 | In | Loop Size Selector = 8 | Deck A |  | Button - Direct | Ch05.Note.C1
1 | 22 | In | Loop Size Selector = 16 | Deck A |  | Button - Direct | Ch05.Note.C#1
1 | 23 | In | Loop Size Selector = 32 | Deck A |  | Button - Direct | Ch05.Note.D1
1 | 24 | In | Loop Active On = Off | Deck A |  | Button - Direct | Ch05.Note.D#1
1 | 25 | In | Beatjump [Hold] = -1/2 | Deck A |  | Button - Hold | Ch05.Note.E1
1 | 26 | In | Beatjump [Hold] = -1 | Deck A |  | Button - Hold | Ch05.Note.F1
1 | 27 | In | Beatjump [Hold] = -4 | Deck A |  | Button - Hold | Ch05.Note.F#1
1 | 28 | In | Beatjump [Hold] = -16 | Deck A |  | Button - Hold | Ch05.Note.G1
1 | 29 | In | Beatjump [Hold] = +1/2 | Deck A |  | Button - Hold | Ch05.Note.G#1
1 | 30 | In | Beatjump [Hold] = +1 | Deck A |  | Button - Hold | Ch05.Note.A1
1 | 31 | In | Beatjump [Hold] = +4 | Deck A |  | Button - Hold | Ch05.Note.A#1
1 | 32 | In | Beatjump [Hold] = +16 | Deck A |  | Button - Hold | Ch05.Note.B1
1 | 33 | In | Tempo Range Selector = 8% | Deck A |  | Button - Direct | Ch05.Note.C2
1 | 34 | In | Tempo Range Selector = 8% | Deck A |  | Button - Direct | Ch05.Note.C#2
1 | 35 | In | Tempo Range Selector = 8% | Deck A |  | Button - Direct | Ch05.Note.D2
1 | 36 | In | Tempo Range Selector = 8% | Deck A |  | Button - Direct | Ch05.Note.D#2
1 | 2 | In | Select/Set+Store Hotcue [Hold] = Hotcue2 | Deck A |  | Button - Hold | Ch05.Note.C#0
1 | 3 | In | Select/Set+Store Hotcue [Hold] = Hotcue3 | Deck A |  | Button - Hold | Ch05.Note.D0
1 | 4 | In | Select/Set+Store Hotcue [Hold] = Hotcue4 | Deck A |  | Button - Hold | Ch05.Note.D#0
1 | 5 | In | Select/Set+Store Hotcue [Hold] = Hotcue5 | Deck A |  | Button - Hold | Ch05.Note.E0
1 | 6 | In | Select/Set+Store Hotcue [Hold] = Hotcue6 | Deck A |  | Button - Hold | Ch05.Note.F0
1 | 7 | In | Select/Set+Store Hotcue [Hold] = Hotcue7 | Deck A |  | Button - Hold | Ch05.Note.F#0
1 | 8 | In | Select/Set+Store Hotcue [Hold] = Hotcue8 | Deck A |  | Button - Hold | Ch05.Note.G0
1 | 9 | In | Delete Hotcue = Hotcue1 | Deck A | M2=1 | Button - Direct | Ch05.Note.C0
1 | 10 | In | Delete Hotcue = Hotcue2 | Deck A | M2=1 | Button - Direct | Ch05.Note.C#0
1 | 11 | In | Delete Hotcue = Hotcue3 | Deck A | M2=1 | Button - Direct | Ch05.Note.D0
1 | 12 | In | Delete Hotcue = Hotcue4 | Deck A | M2=1 | Button - Direct | Ch05.Note.D#0
1 | 13 | In | Delete Hotcue = Hotcue5 | Deck A | M2=1 | Button - Direct | Ch05.Note.E0
1 | 14 | In | Delete Hotcue = Hotcue6 | Deck A | M2=1 | Button - Direct | Ch05.Note.F0
1 | 15 | In | Delete Hotcue = Hotcue7 | Deck A | M2=1 | Button - Direct | Ch05.Note.F#0
1 | 16 | In | Delete Hotcue = Hotcue8 | Deck A | M2=1 | Button - Direct | Ch05.Note.G0
1 | 39 | In | Select/Set+Store Hotcue [Hold] = Hotcue1 | Deck B |  | Button - Hold | Ch06.Note.C0
1 | 40 | In | Tempo Bend [Hold] = Down | Deck B |  | Button - Hold | Ch06.Note.E2
1 | 41 | In | Tempo Bend [Hold] = Up | Deck B |  | Button - Hold | Ch06.Note.F2
1 | 42 | In | Loop Size Selector = 1/2 | Deck B |  | Button - Direct | Ch06.Note.G#0
1 | 43 | In | Loop Size Selector = 1 | Deck B |  | Button - Direct | Ch06.Note.A0
1 | 44 | In | Loop Size Selector = 2 | Deck B |  | Button - Direct | Ch06.Note.A#0
1 | 45 | In | Loop Size Selector = 4 | Deck B |  | Button - Direct | Ch06.Note.B0
1 | 46 | In | Loop Size Selector = 8 | Deck B |  | Button - Direct | Ch06.Note.C1
1 | 47 | In | Loop Size Selector = 16 | Deck B |  | Button - Direct | Ch06.Note.C#1
1 | 48 | In | Loop Size Selector = 32 | Deck B |  | Button - Direct | Ch06.Note.D1
1 | 49 | In | Loop Active On = Off | Deck B |  | Button - Direct | Ch06.Note.D#1
1 | 50 | In | Beatjump [Hold] = -1/2 | Deck B |  | Button - Hold | Ch06.Note.E1
1 | 51 | In | Beatjump [Hold] = -1 | Deck B |  | Button - Hold | Ch06.Note.F1
1 | 52 | In | Beatjump [Hold] = -4 | Deck B |  | Button - Hold | Ch06.Note.F#1
1 | 53 | In | Beatjump [Hold] = -16 | Deck B |  | Button - Hold | Ch06.Note.G1
1 | 54 | In | Beatjump [Hold] = +1/2 | Deck B |  | Button - Hold | Ch06.Note.G#1
1 | 55 | In | Beatjump [Hold] = +1 | Deck B |  | Button - Hold | Ch06.Note.A1
1 | 56 | In | Beatjump [Hold] = +4 | Deck B |  | Button - Hold | Ch06.Note.A#1
1 | 57 | In | Beatjump [Hold] = +16 | Deck B |  | Button - Hold | Ch06.Note.B1
1 | 58 | In | Tempo Range Selector = 8% | Deck B |  | Button - Direct | Ch06.Note.C2
1 | 59 | In | Tempo Range Selector = 8% | Deck B |  | Button - Direct | Ch06.Note.C#2
1 | 60 | In | Tempo Range Selector = 8% | Deck B |  | Button - Direct | Ch06.Note.D2
1 | 61 | In | Tempo Range Selector = 8% | Deck B |  | Button - Direct | Ch06.Note.D#2
1 | 62 | In | Select/Set+Store Hotcue [Hold] = Hotcue2 | Deck B |  | Button - Hold | Ch06.Note.C#0
1 | 63 | In | Select/Set+Store Hotcue [Hold] = Hotcue3 | Deck B |  | Button - Hold | Ch06.Note.D0
1 | 64 | In | Select/Set+Store Hotcue [Hold] = Hotcue4 | Deck B |  | Button - Hold | Ch06.Note.D#0
1 | 65 | In | Select/Set+Store Hotcue [Hold] = Hotcue5 | Deck B |  | Button - Hold | Ch06.Note.E0
1 | 66 | In | Select/Set+Store Hotcue [Hold] = Hotcue6 | Deck B |  | Button - Hold | Ch06.Note.F0
1 | 67 | In | Select/Set+Store Hotcue [Hold] = Hotcue7 | Deck B |  | Button - Hold | Ch06.Note.F#0
1 | 68 | In | Select/Set+Store Hotcue [Hold] = Hotcue8 | Deck B |  | Button - Hold | Ch06.Note.G0
1 | 69 | In | Delete Hotcue = Hotcue1 | Deck B | M2=1 | Button - Direct | Ch06.Note.C0
1 | 70 | In | Delete Hotcue = Hotcue2 | Deck B | M2=1 | Button - Direct | Ch06.Note.C#0
1 | 71 | In | Delete Hotcue = Hotcue3 | Deck B | M2=1 | Button - Direct | Ch06.Note.D0
1 | 72 | In | Delete Hotcue = Hotcue4 | Deck B | M2=1 | Button - Direct | Ch06.Note.D#0
1 | 73 | In | Delete Hotcue = Hotcue5 | Deck B | M2=1 | Button - Direct | Ch06.Note.E0
1 | 74 | In | Delete Hotcue = Hotcue6 | Deck B | M2=1 | Button - Direct | Ch06.Note.F0
1 | 75 | In | Delete Hotcue = Hotcue7 | Deck B | M2=1 | Button - Direct | Ch06.Note.F#0
1 | 76 | In | Delete Hotcue = Hotcue8 | Deck B | M2=1 | Button - Direct | Ch06.Note.G0
1 | 77 | In | Select/Set+Store Hotcue [Hold] = Hotcue1 | Deck C |  | Button - Hold | Ch07.Note.C0
1 | 78 | In | Tempo Bend [Hold] = Down | Deck C |  | Button - Hold | Ch07.Note.E2
1 | 79 | In | Tempo Bend [Hold] = Up | Deck C |  | Button - Hold | Ch07.Note.F2
1 | 80 | In | Loop Size Selector = 1/2 | Deck C |  | Button - Direct | Ch07.Note.G#0
1 | 81 | In | Loop Size Selector = 1 | Deck C |  | Button - Direct | Ch07.Note.A0
1 | 82 | In | Loop Size Selector = 2 | Deck C |  | Button - Direct | Ch07.Note.A#0
1 | 83 | In | Loop Size Selector = 4 | Deck C |  | Button - Direct | Ch07.Note.B0
1 | 84 | In | Loop Size Selector = 8 | Deck C |  | Button - Direct | Ch07.Note.C1
1 | 85 | In | Loop Size Selector = 16 | Deck C |  | Button - Direct | Ch07.Note.C#1
1 | 86 | In | Loop Size Selector = 32 | Deck C |  | Button - Direct | Ch07.Note.D1
1 | 87 | In | Loop Active On = Off | Deck C |  | Button - Direct | Ch07.Note.D#1
1 | 88 | In | Beatjump [Hold] = -1/2 | Deck C |  | Button - Hold | Ch07.Note.E1
1 | 89 | In | Beatjump [Hold] = -1 | Deck C |  | Button - Hold | Ch07.Note.F1
1 | 90 | In | Beatjump [Hold] = -4 | Deck C |  | Button - Hold | Ch07.Note.F#1
1 | 91 | In | Beatjump [Hold] = -16 | Deck C |  | Button - Hold | Ch07.Note.G1
1 | 92 | In | Beatjump [Hold] = +1/2 | Deck C |  | Button - Hold | Ch07.Note.G#1
1 | 93 | In | Beatjump [Hold] = +1 | Deck C |  | Button - Hold | Ch07.Note.A1
1 | 94 | In | Beatjump [Hold] = +4 | Deck C |  | Button - Hold | Ch07.Note.A#1
1 | 95 | In | Beatjump [Hold] = +16 | Deck C |  | Button - Hold | Ch07.Note.B1
1 | 96 | In | Tempo Range Selector = 8% | Deck C |  | Button - Direct | Ch07.Note.C2
1 | 97 | In | Tempo Range Selector = 8% | Deck C |  | Button - Direct | Ch07.Note.C#2
1 | 98 | In | Tempo Range Selector = 8% | Deck C |  | Button - Direct | Ch07.Note.D2
1 | 99 | In | Tempo Range Selector = 8% | Deck C |  | Button - Direct | Ch07.Note.D#2
1 | 100 | In | Select/Set+Store Hotcue [Hold] = Hotcue2 | Deck C |  | Button - Hold | Ch07.Note.C#0
1 | 101 | In | Select/Set+Store Hotcue [Hold] = Hotcue3 | Deck C |  | Button - Hold | Ch07.Note.D0
1 | 102 | In | Select/Set+Store Hotcue [Hold] = Hotcue4 | Deck C |  | Button - Hold | Ch07.Note.D#0
1 | 103 | In | Select/Set+Store Hotcue [Hold] = Hotcue5 | Deck C |  | Button - Hold | Ch07.Note.E0
1 | 104 | In | Select/Set+Store Hotcue [Hold] = Hotcue6 | Deck C |  | Button - Hold | Ch07.Note.F0
1 | 105 | In | Select/Set+Store Hotcue [Hold] = Hotcue7 | Deck C |  | Button - Hold | Ch07.Note.F#0
1 | 106 | In | Select/Set+Store Hotcue [Hold] = Hotcue8 | Deck C |  | Button - Hold | Ch07.Note.G0
1 | 107 | In | Delete Hotcue = Hotcue1 | Deck C | M2=1 | Button - Direct | Ch07.Note.C0
1 | 108 | In | Delete Hotcue = Hotcue2 | Deck C | M2=1 | Button - Direct | Ch07.Note.C#0
1 | 109 | In | Delete Hotcue = Hotcue3 | Deck C | M2=1 | Button - Direct | Ch07.Note.D0
1 | 110 | In | Delete Hotcue = Hotcue4 | Deck C | M2=1 | Button - Direct | Ch07.Note.D#0
1 | 111 | In | Delete Hotcue = Hotcue5 | Deck C | M2=1 | Button - Direct | Ch07.Note.E0
1 | 112 | In | Delete Hotcue = Hotcue6 | Deck C | M2=1 | Button - Direct | Ch07.Note.F0
1 | 113 | In | Delete Hotcue = Hotcue7 | Deck C | M2=1 | Button - Direct | Ch07.Note.F#0
1 | 114 | In | Delete Hotcue = Hotcue8 | Deck C | M2=1 | Button - Direct | Ch07.Note.G0

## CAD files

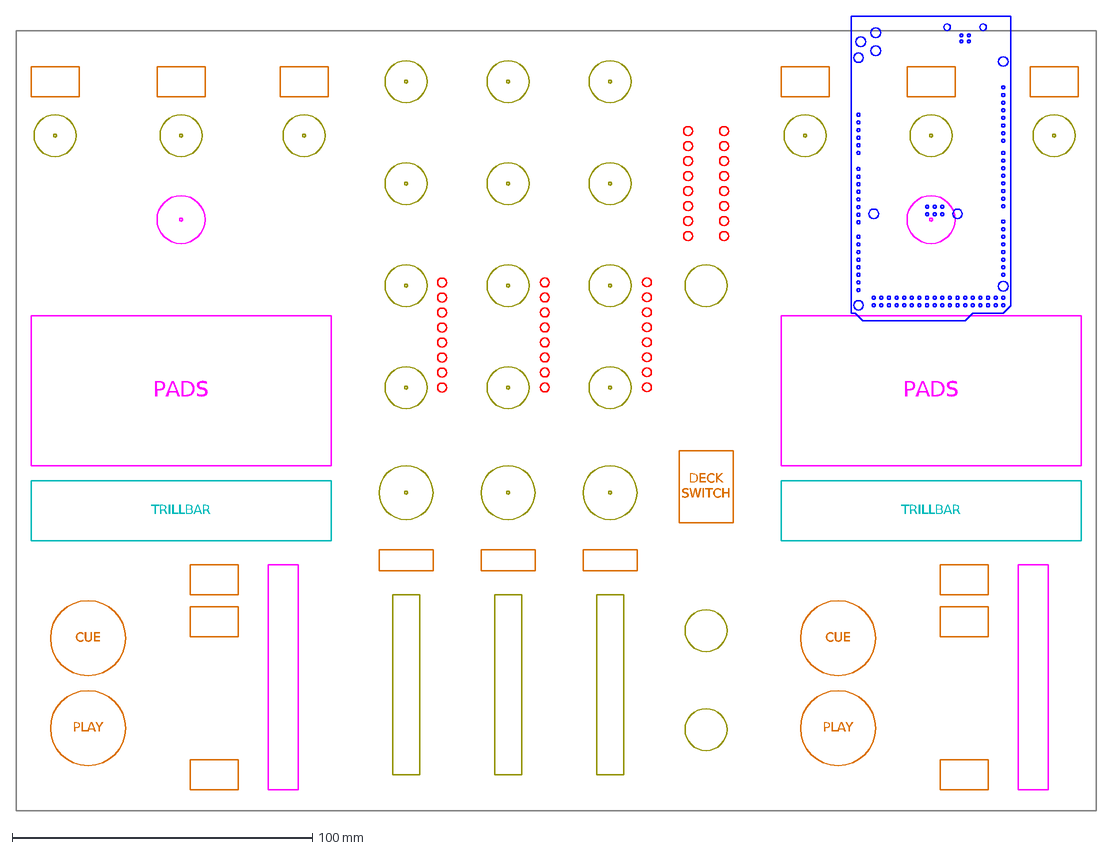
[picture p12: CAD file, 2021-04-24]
docs/layout/Mixduino-layout.dxf
PADS
CUE
PLAY
TRILLBAR
DECK SWITCH

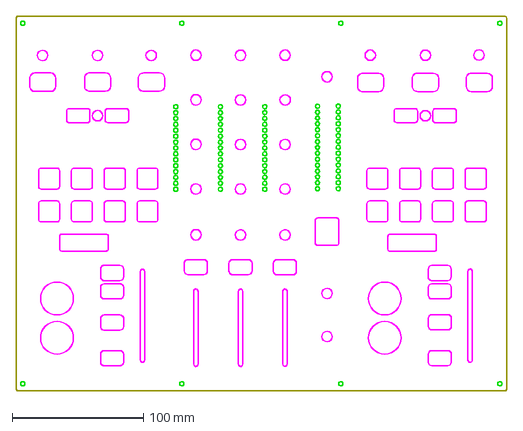
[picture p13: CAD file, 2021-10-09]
Enclosure/top-cover-rev5.dxf
374.0 x 286.0 mm

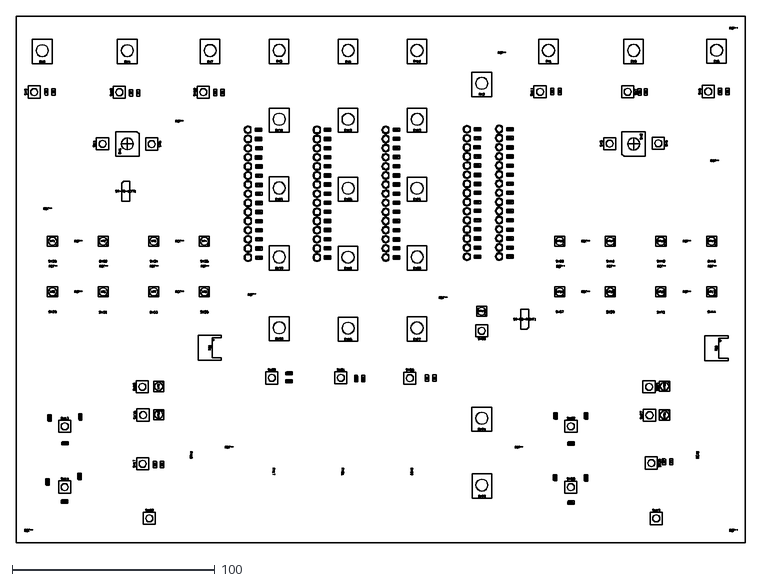
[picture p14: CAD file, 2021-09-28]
PCB/DXF/Mixduino-F_Fab.dxf
360.0 x 260.0

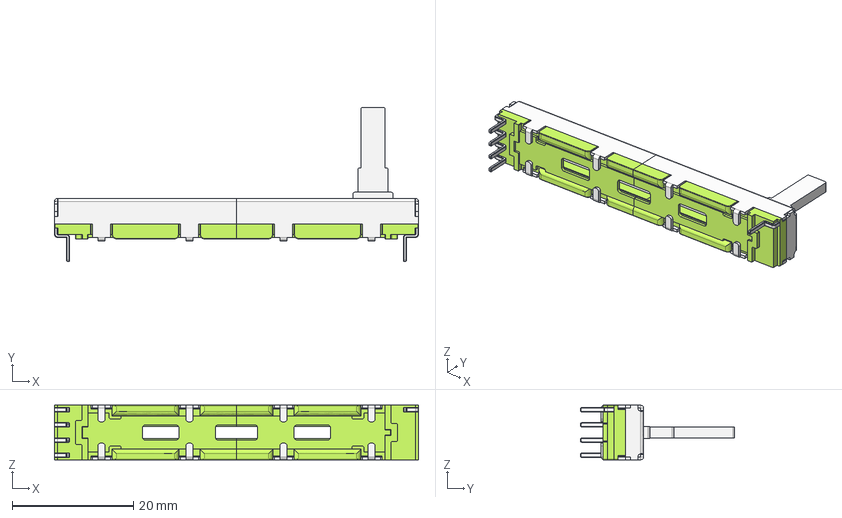
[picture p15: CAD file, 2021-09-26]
PCB/Kicad/3d-models/60mm_pot.step
60.0 x 25.4 x 9.00 mm

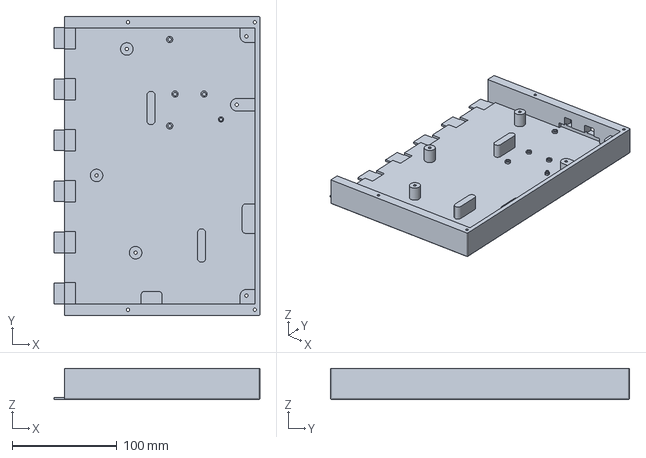
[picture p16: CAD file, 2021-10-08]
Enclosure/Bottom-Cover-Right.3mf
197.0 x 286.0 x 30.0 mm

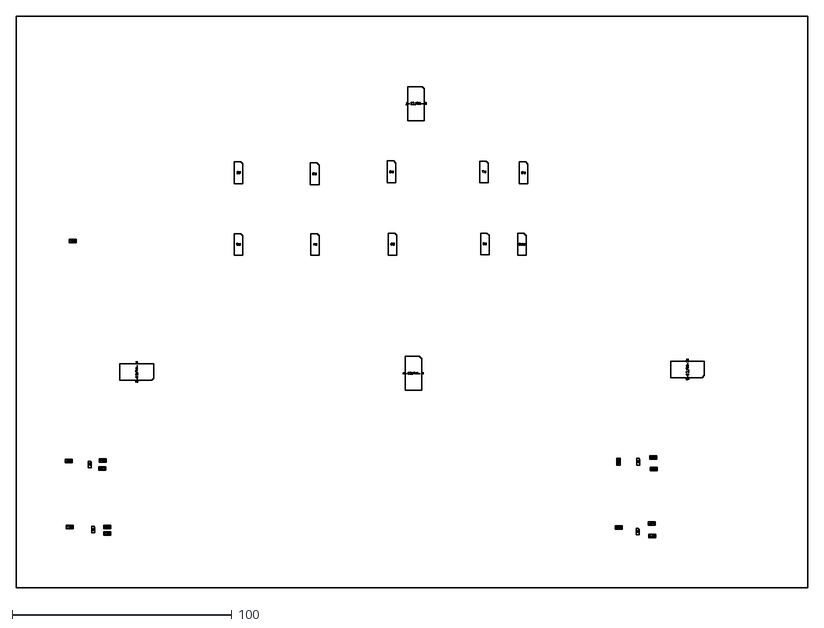
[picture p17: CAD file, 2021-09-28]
PCB/DXF/Mixduino-B_Fab.dxf
360.0 x 260.0

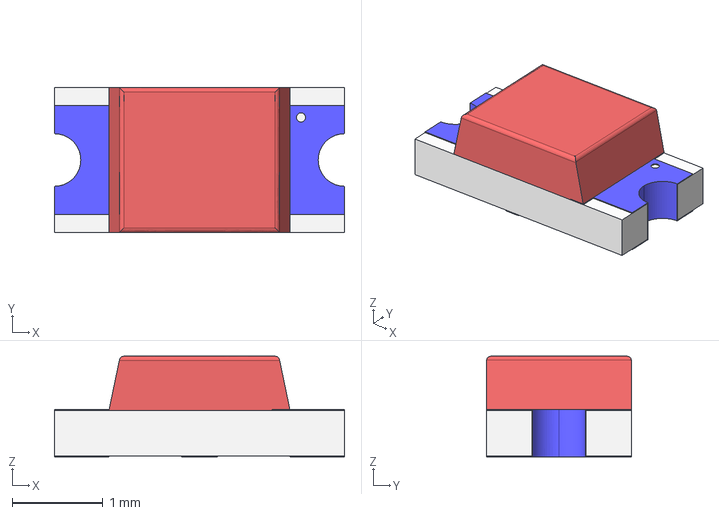
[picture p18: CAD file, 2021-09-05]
PCB/Kicad/3d-models/Surface Mount Chip LED 3.2x1.6mm 2.stp
3.20 x 1.60 x 1.11 mm

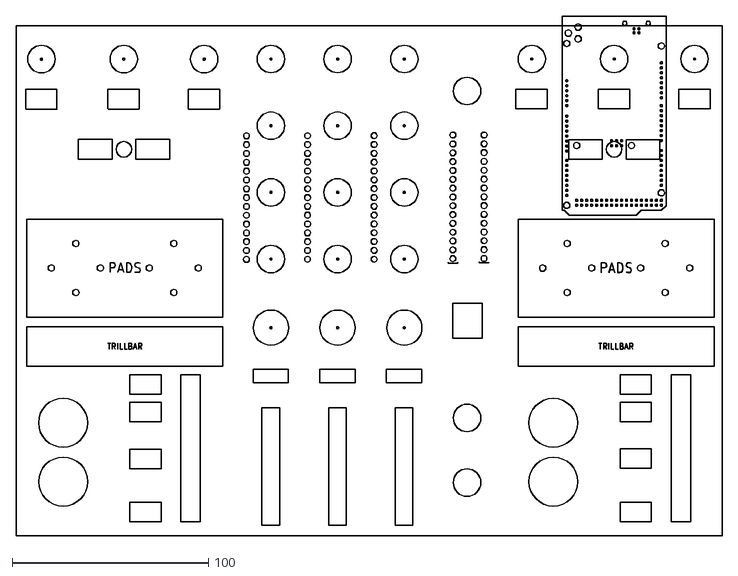
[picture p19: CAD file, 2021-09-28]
PCB/DXF/Mixduino-User_Drawings.dxf
360.0 x 264.7

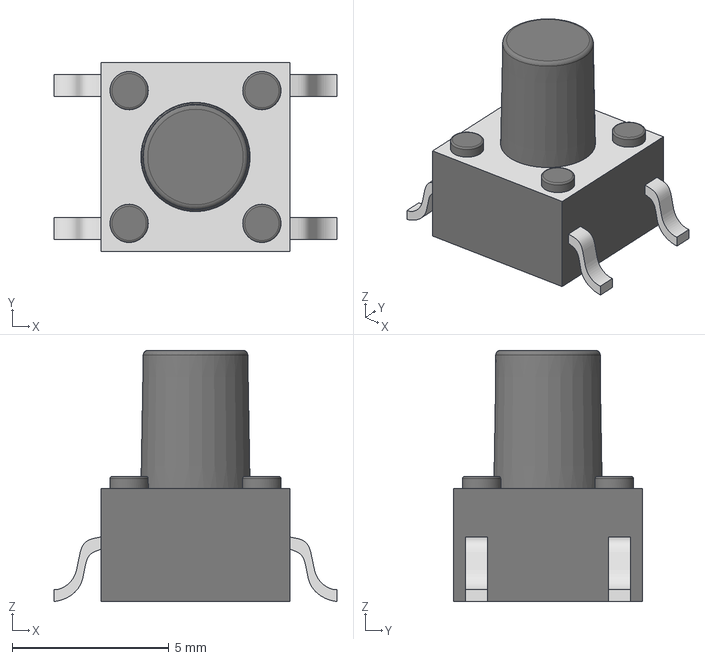
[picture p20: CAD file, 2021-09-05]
PCB/Kicad/3d-models/Tactal Switch - SMD 6x6x8.stp
9.02 x 6.03 x 8.00 mm

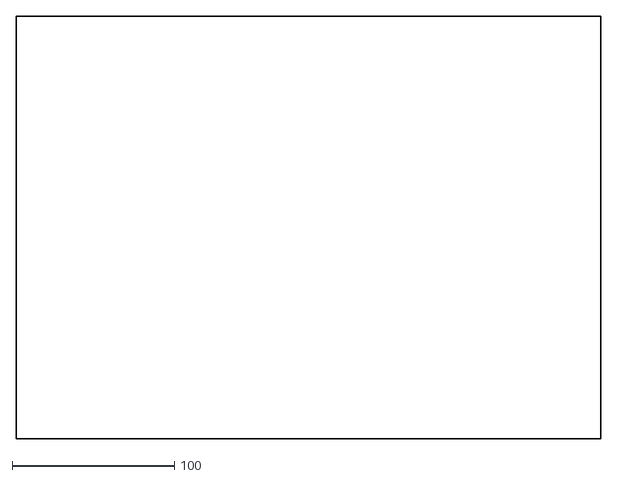
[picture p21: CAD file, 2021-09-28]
PCB/DXF/Mixduino-Edge_Cuts.dxf
360.0 x 260.0

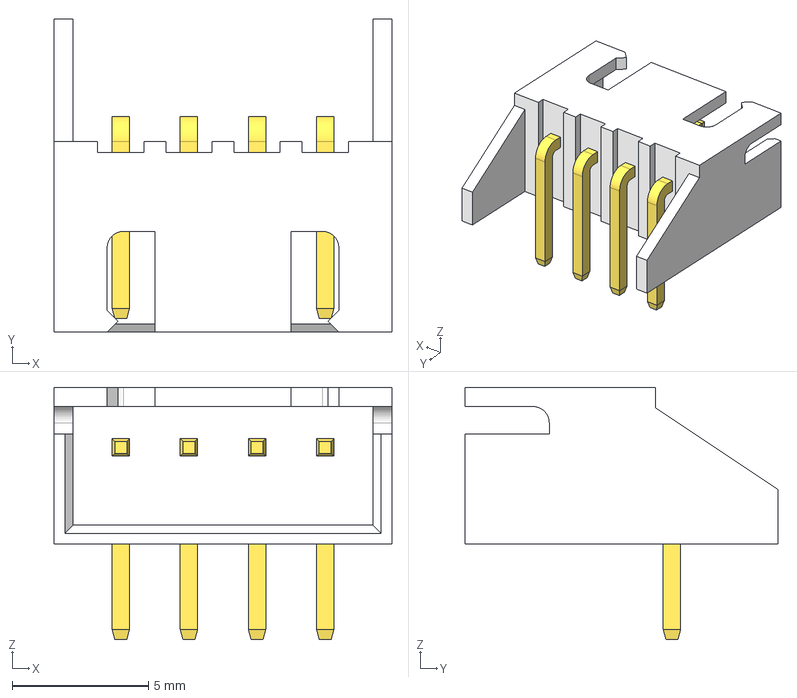
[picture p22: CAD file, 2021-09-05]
PCB/Kicad/3d-models/S4B-XH-A-1.step
12.4 x 11.5 x 9.25 mm

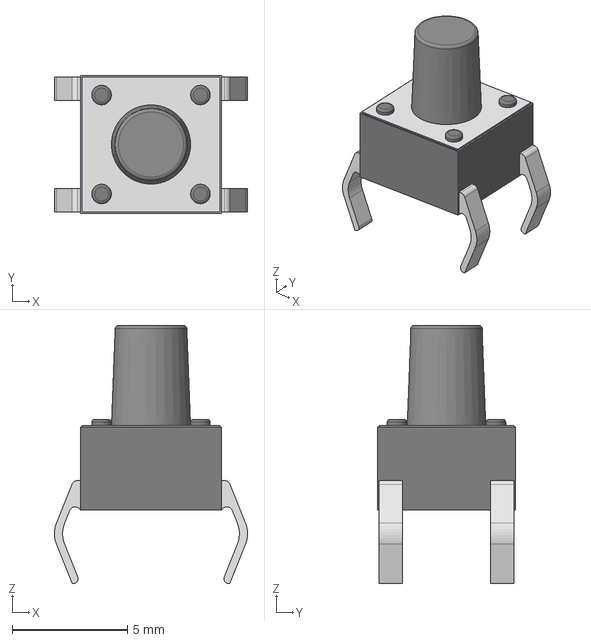
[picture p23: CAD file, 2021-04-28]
PCB/Kicad/3d-models/Tactal Switch -Thru 6x 6x8.stp
8.37 x 5.99 x 11.2 mm

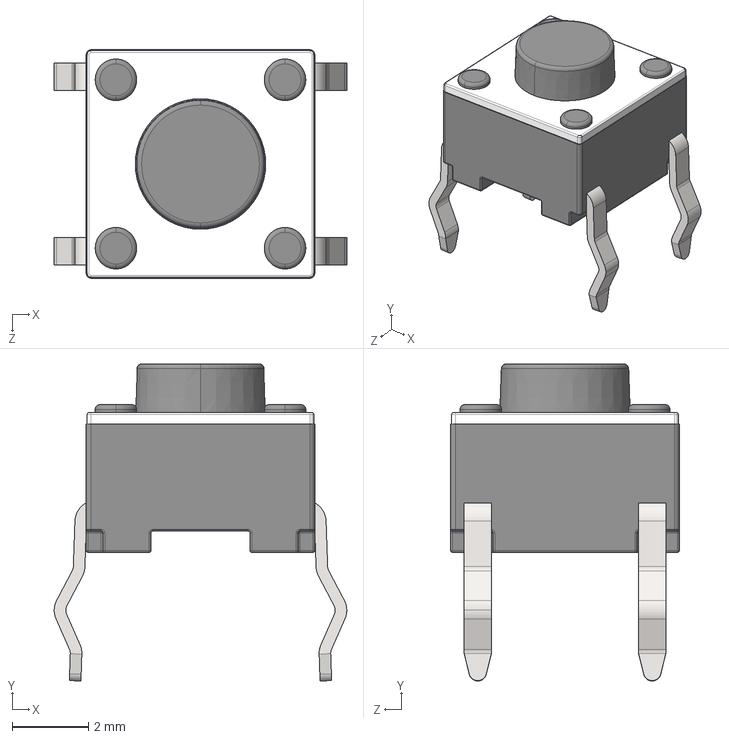
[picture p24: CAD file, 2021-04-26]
PCB/Kicad/3d-models/tactileswitch-short.STEP
7.69 x 8.33 x 6.01 mm

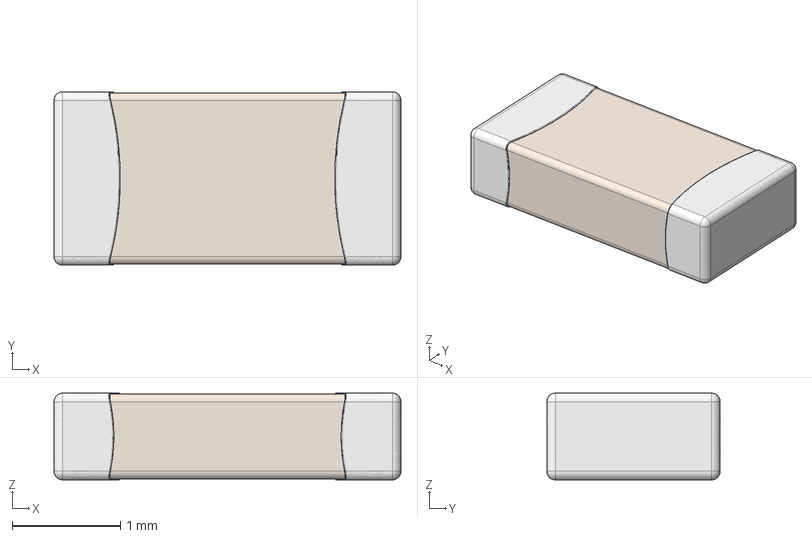
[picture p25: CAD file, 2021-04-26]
PCB/Kicad/3d-models/Ceramic_Capacitor_1206_h32mil.step
3.20 x 1.60 x 0.8 mm
Pin1
Pin2
CeramicBody

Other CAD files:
Enclosure/Bottom-Cover-Left.3mf
PCB/Kicad/3d-models/WS2812B.step
PCB/Kicad/3d-models/Resistor_SMD_0,25W_1206.stp
PCB/Kicad/3d-models/LED D3 - Yellow_cutted.step
PCB/DXF/Mixduino-B_Mask.dxf
PCB/DXF/Mixduino-B_Paste.dxf
PCB/DXF/Mixduino-B_Silkscreen.dxf
PCB/DXF/Mixduino-F_Mask.dxf
PCB/DXF/Mixduino-F_Paste.dxf
PCB/DXF/Mixduino-F_Silkscreen.dxf
PCB/Kicad/3d-models/75mm Straight Slide Potentiometer.step
PCB/Kicad/3d-models/EC11B-SW-Vert-20R-blue.step
PCB/Kicad/3d-models/LED D3 - Blue_cutted.step
PCB/Kicad/3d-models/LED D3 - Green_cutted.step
PCB/Kicad/3d-models/LED D3 - Red_cutted.step
PCB/Kicad/3d-models/R-0904N-L-25KT-green.step
PCB/Kicad/3d-models/SO-16.step
PCB/Kicad/3d-models/SW3dPS-SOIC24.STEP

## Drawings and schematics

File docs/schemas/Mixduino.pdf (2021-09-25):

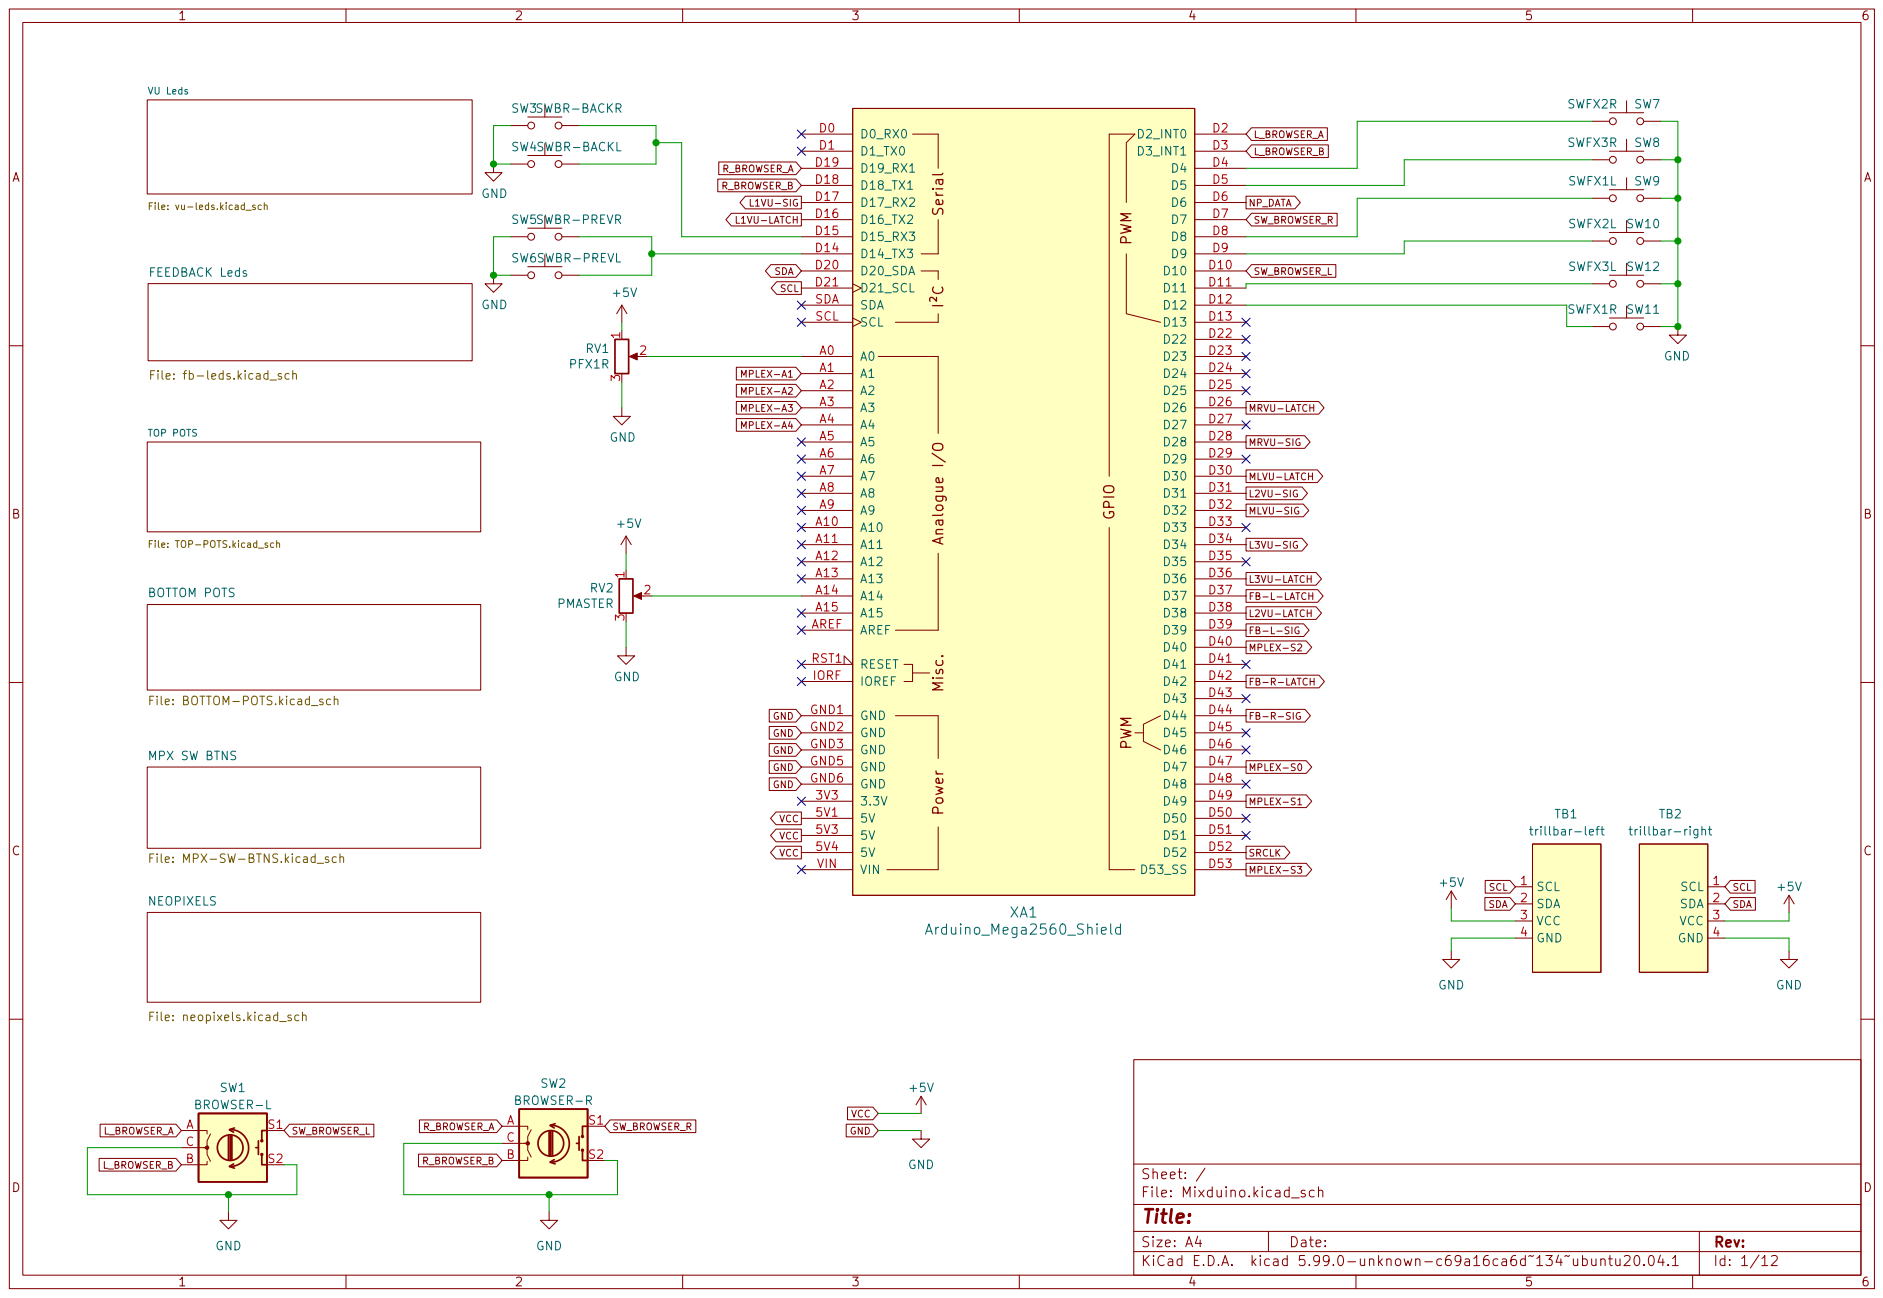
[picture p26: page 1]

VU Leds File: vu-leds.kicad_sch NEOPIXELS
MPLEX-A4

FEEDBACK Leds File: fb-leds.kicad_sch

SCL SDA MRVU-SIG MLVU-LATCH

L3VU-LATCH
FB-L-LATCH
L2VU-LATCH
FB-R-LATCH MPLEX-S2 FB-L-SIG

File: MPX-SW-BTNS.kicad_sch BOTTOM POTS

File: Mixduino.kicad_sch Sheet: / MPX SW BTNS

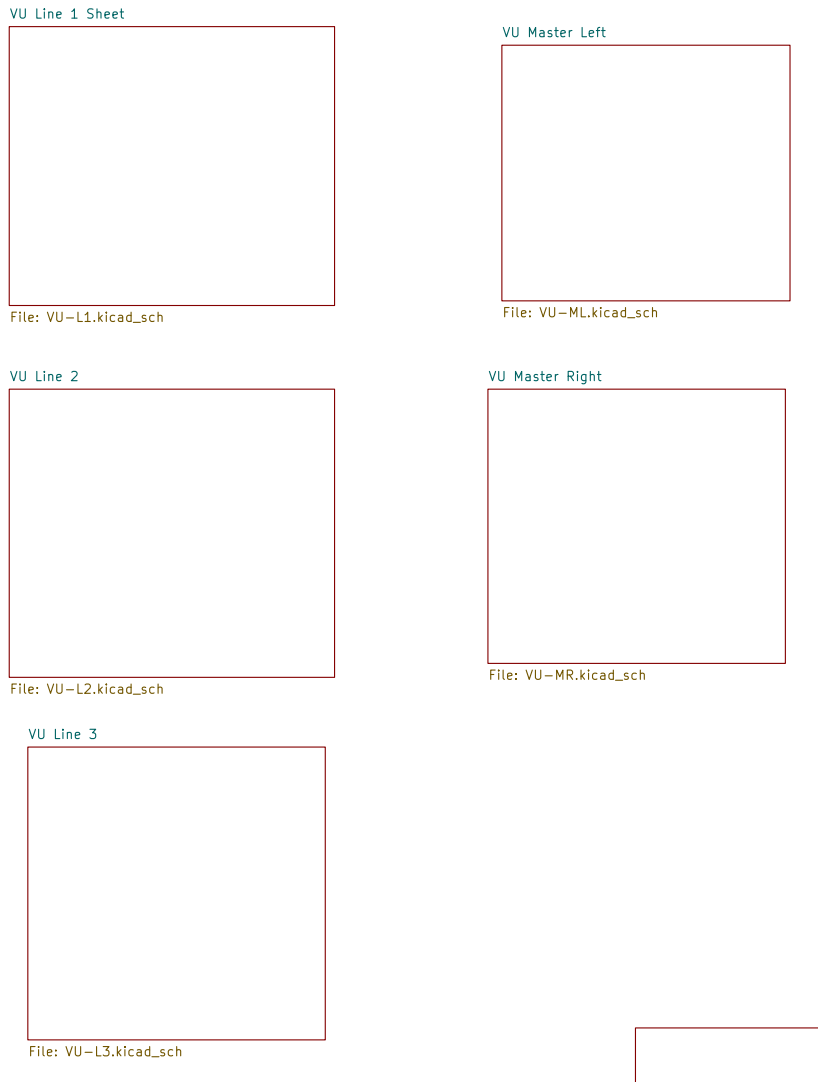
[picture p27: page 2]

VU Line 1 Sheet File: VU-L1.kicad_sch VU Line 2 File: VU-L2.kicad_sch VU Line 3 File: VU-L3.kicad_sch

VU Master Left File: VU-ML.kicad_sch VU Master Right File: VU-MR.kicad_sch

File: vu-leds.kicad_sch Sheet: /VU Leds/
Id: 2/12 Title:

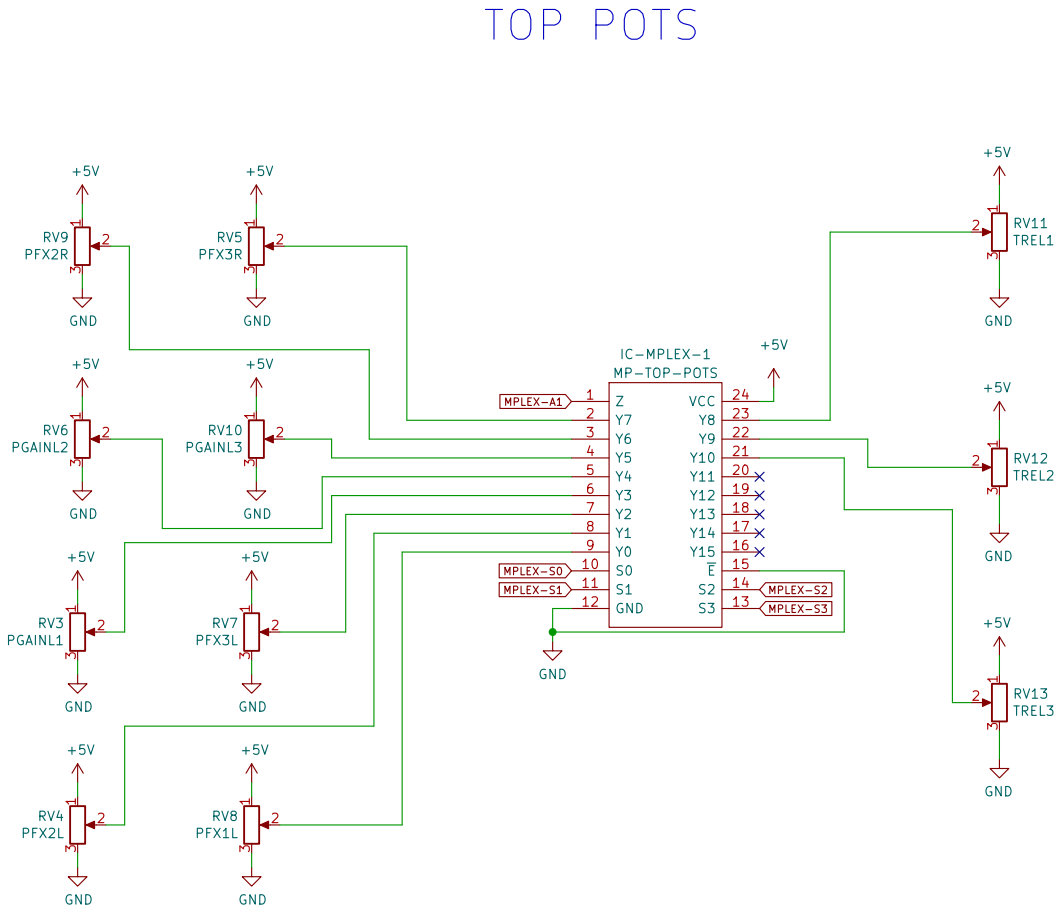
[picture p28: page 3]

IC-MPLEX-1 MP-TOP-POTS

File: TOP-POTS.kicad_sch Sheet: /TOP POTS/
Id: 3/12 Title:

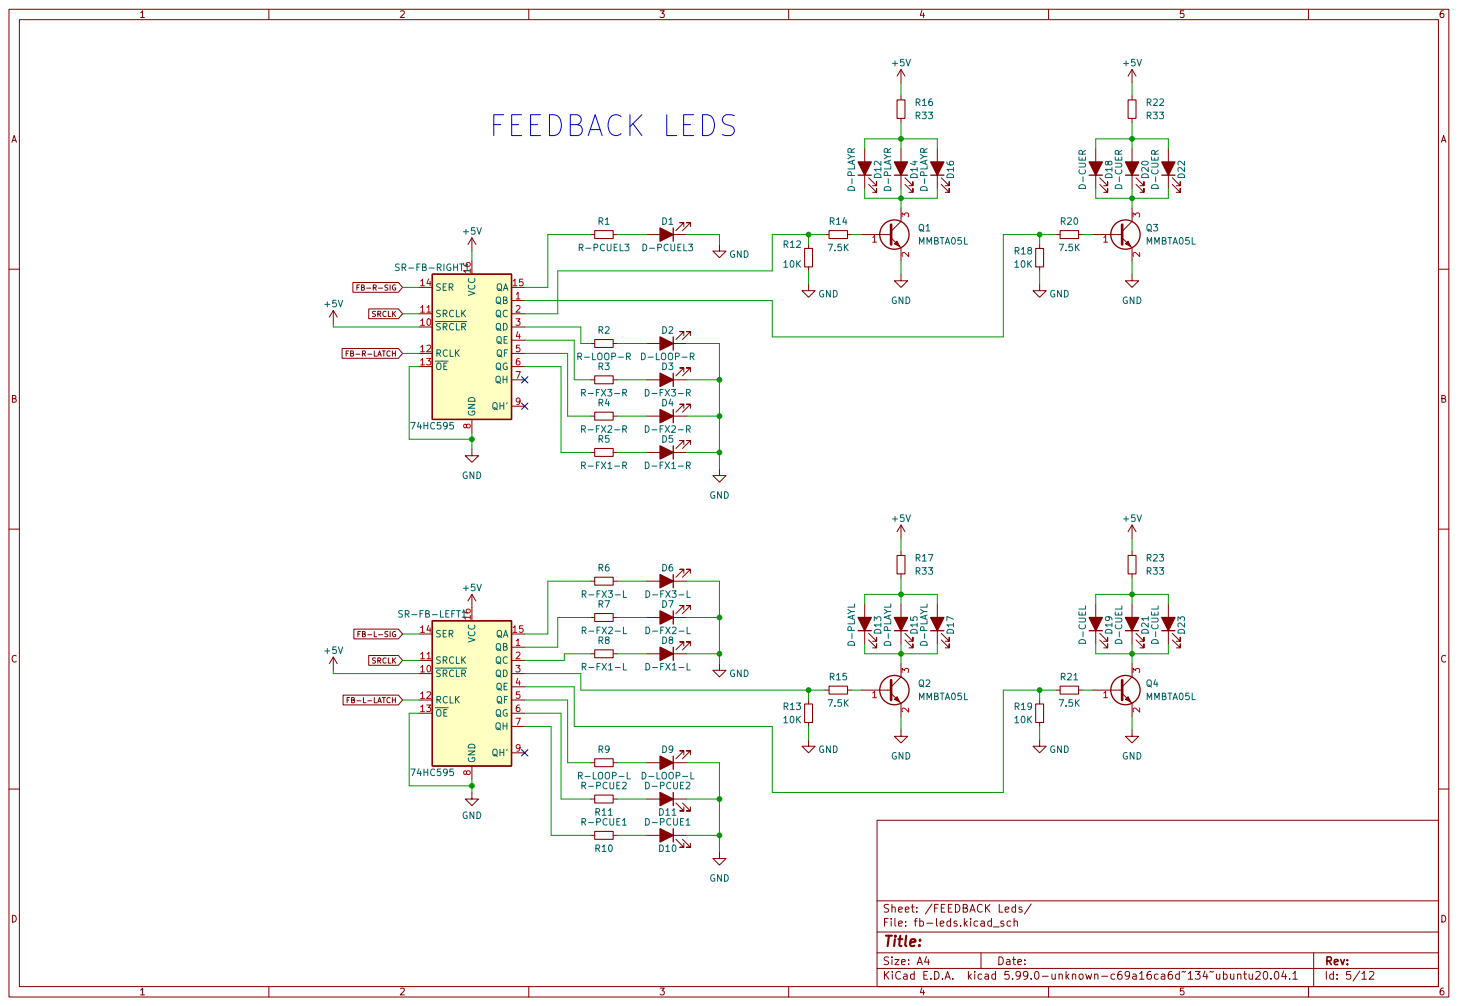
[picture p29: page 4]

File: fb-leds.kicad_sch Sheet: /FEEDBACK Leds/

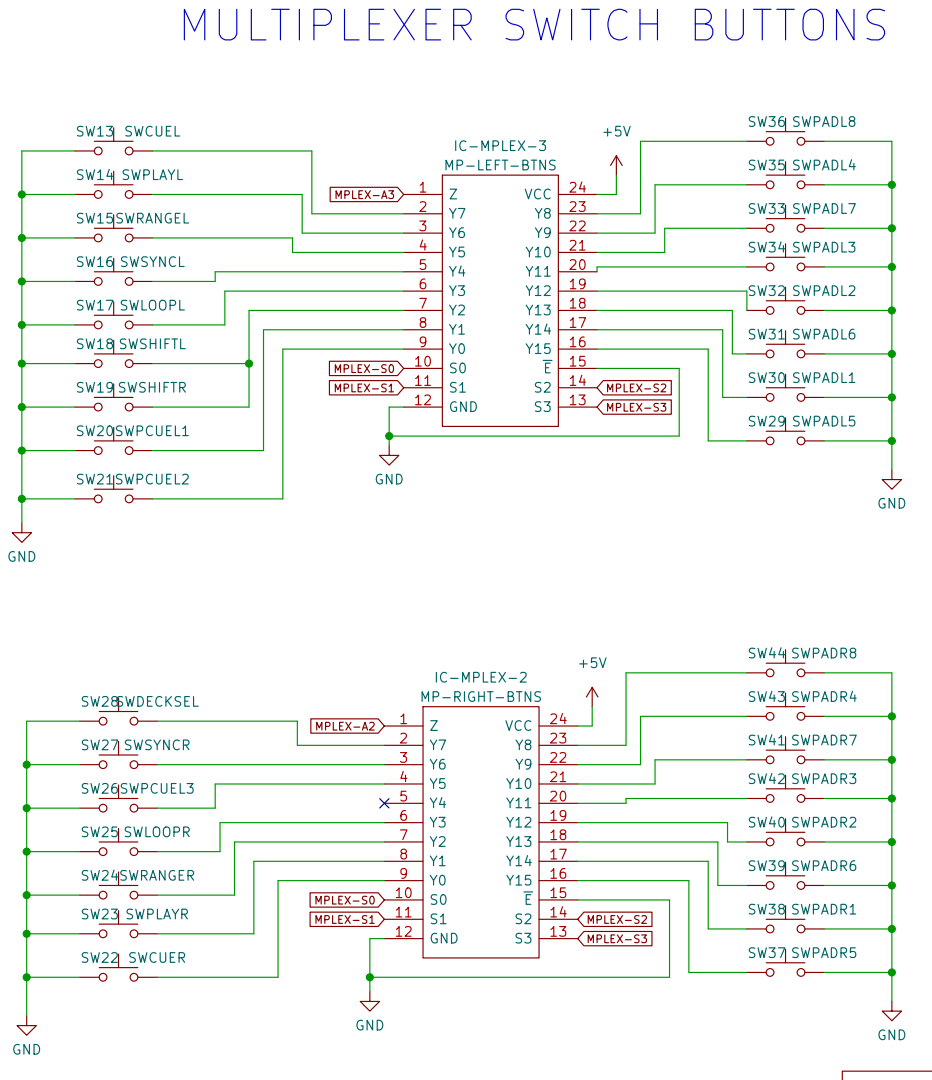
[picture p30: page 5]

IC-MPLEX-3 MP-LEFT-BTNS

IC-MPLEX-2 MP-RIGHT-BTNS

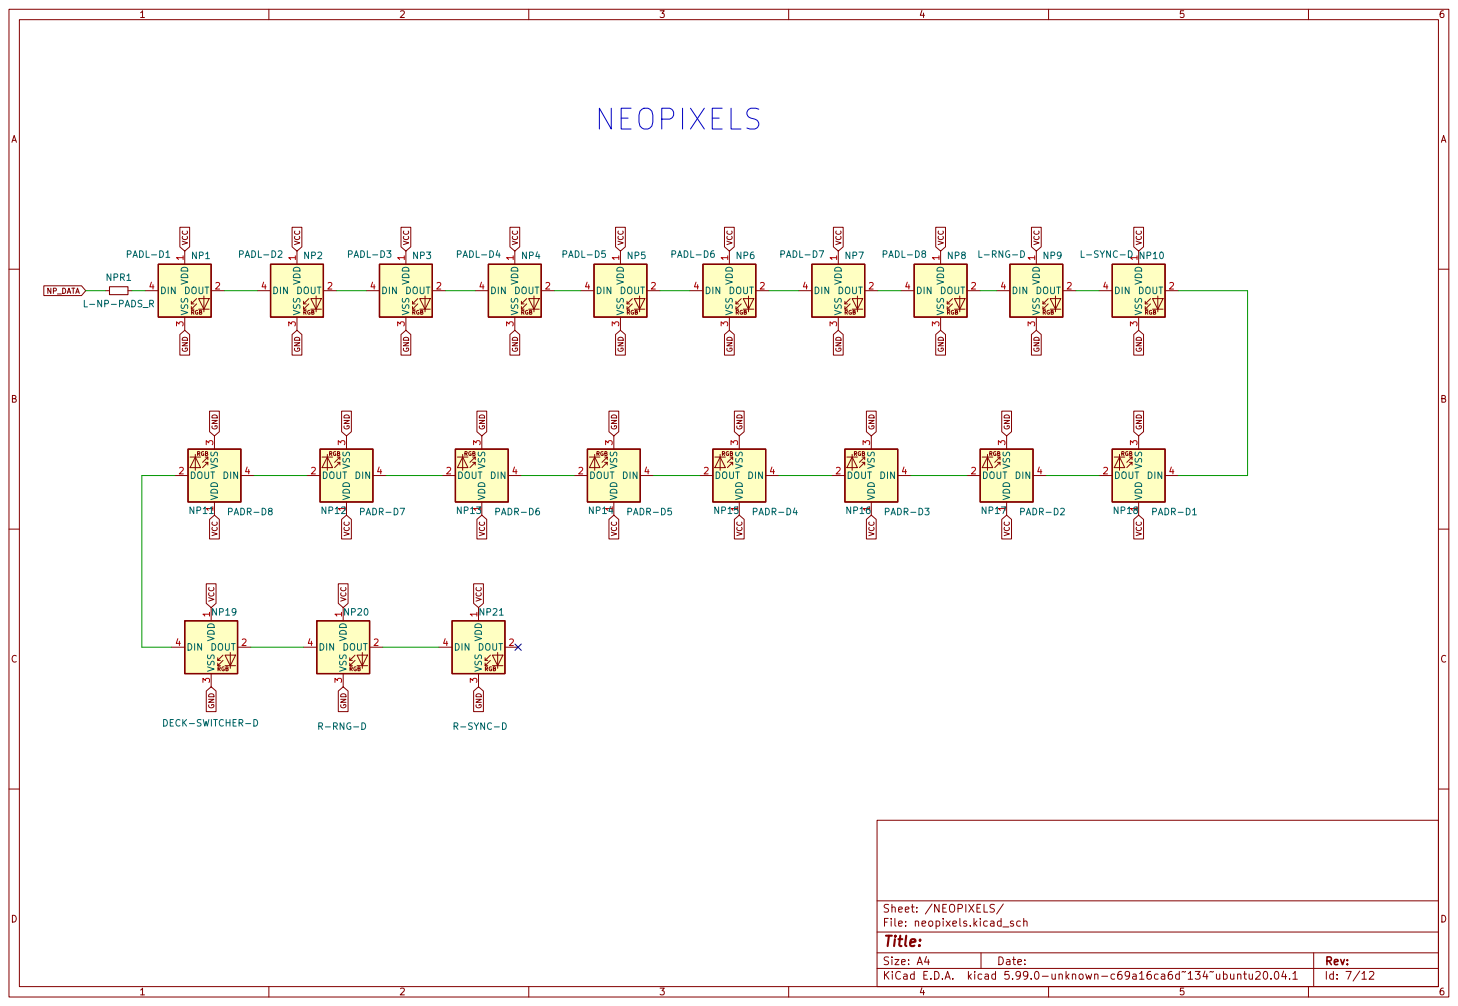
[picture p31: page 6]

3 DIN 4 NP18 PADR-D1 GND GND VCC VCC GND GND GND GND VCC VCC VCC GND
RGB VDD

File: neopixels.kicad_sch Sheet: /NEOPIXELS/
Id: 7/12 Title:

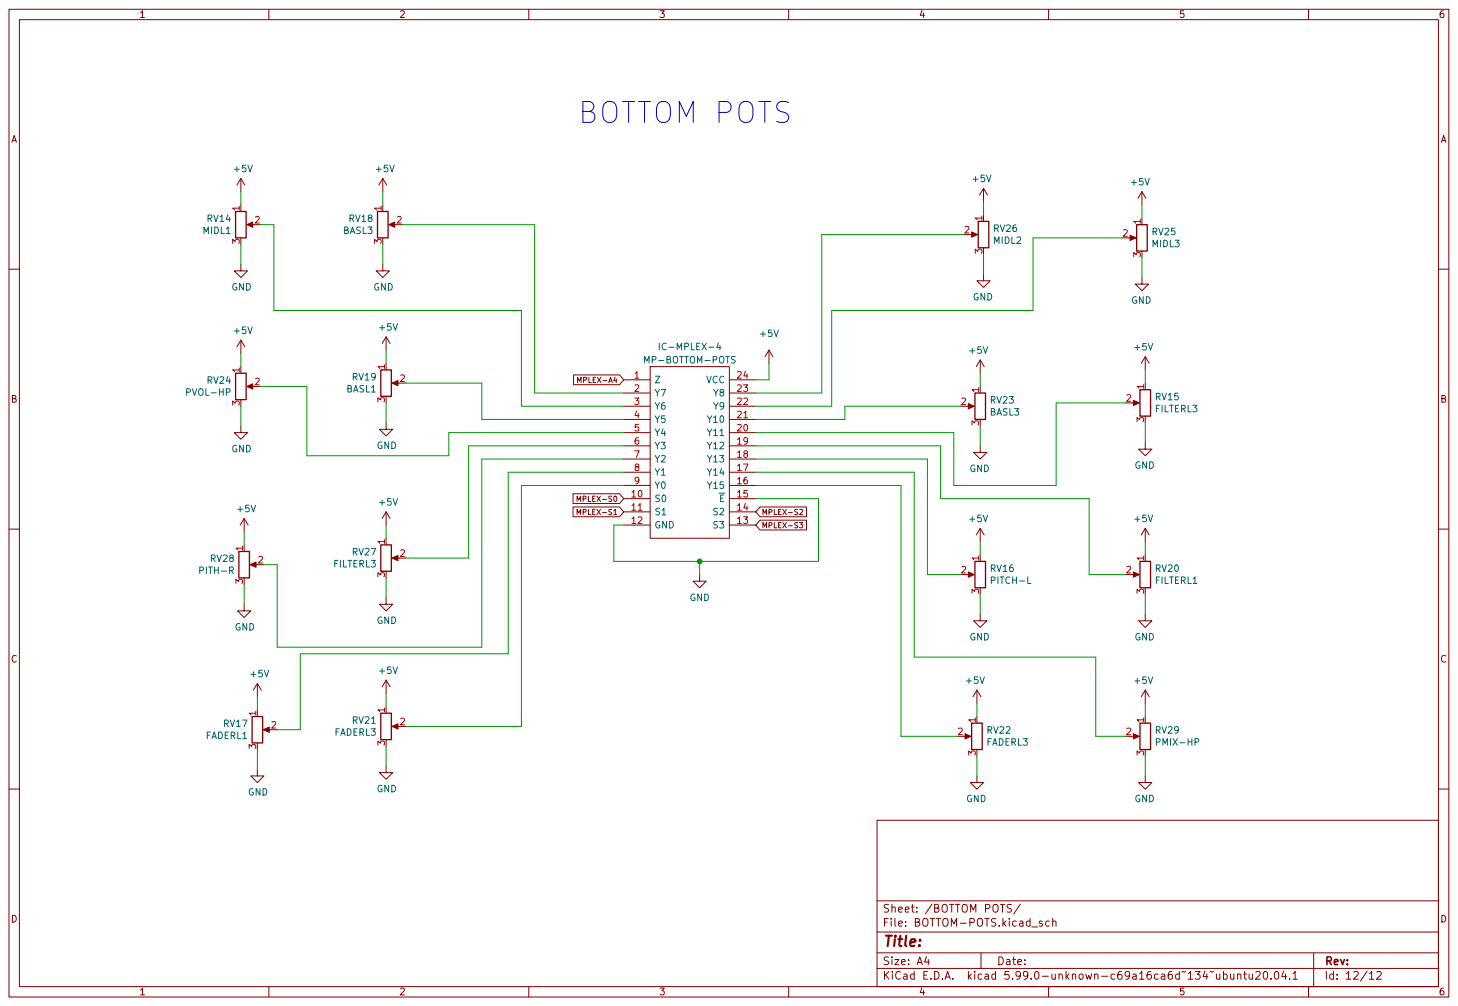
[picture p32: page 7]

IC-MPLEX-4 MP-BOTTOM-POTS

File: BOTTOM-POTS.kicad_sch Sheet: /BOTTOM POTS/
Id: 12/12 Title:

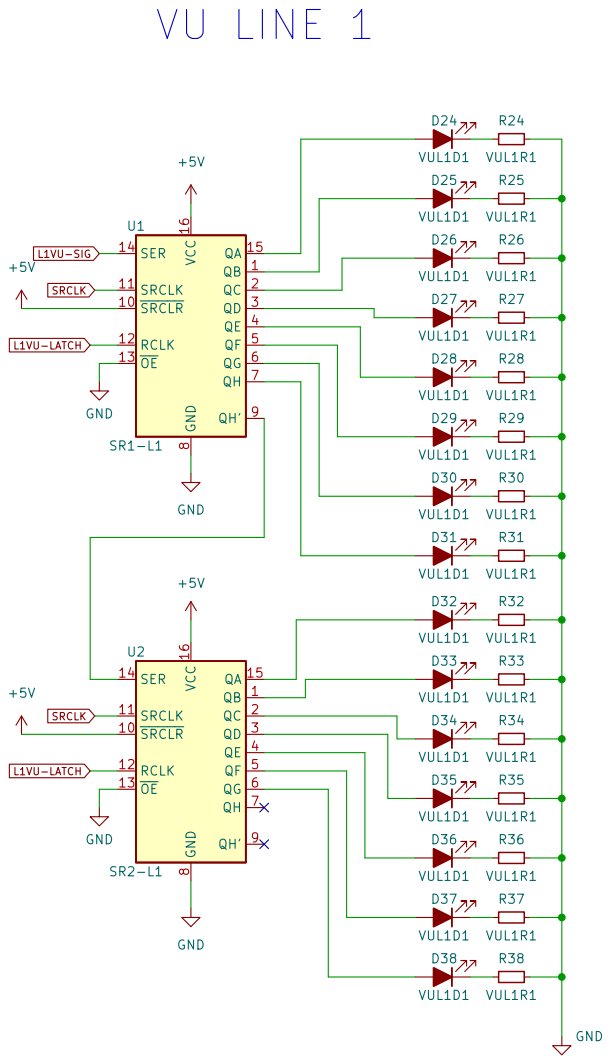
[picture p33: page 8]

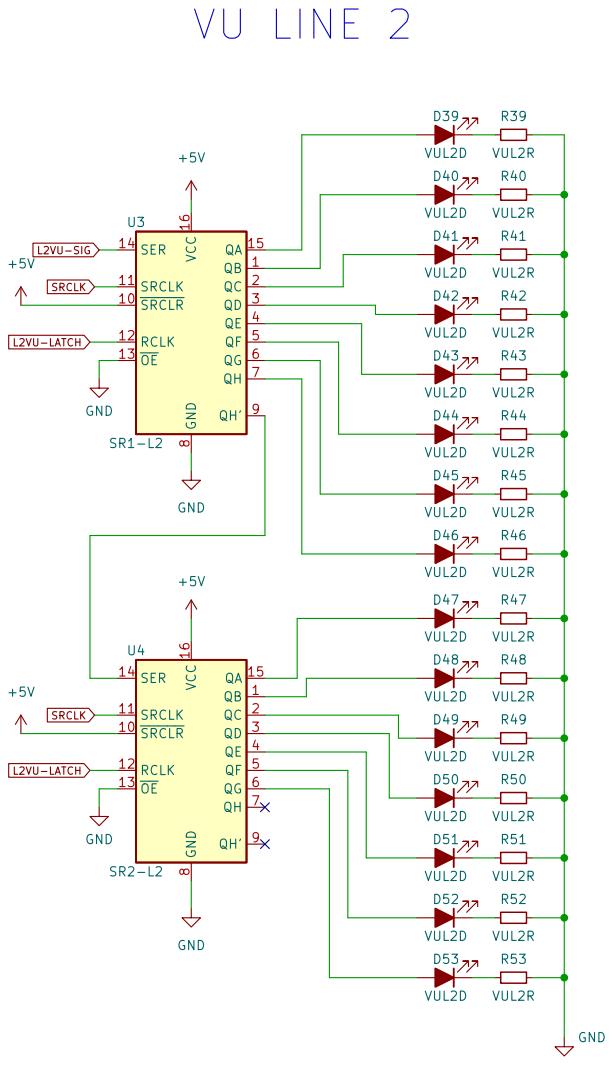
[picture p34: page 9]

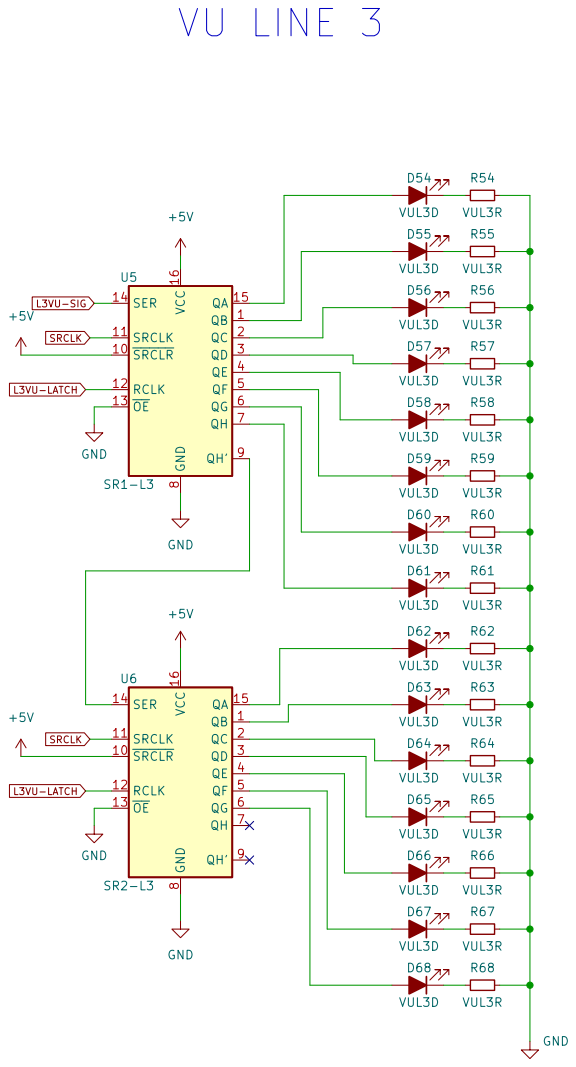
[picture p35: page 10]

File: VU-L3.kicad_sch Sheet: /VU Leds/VU Line 3 /

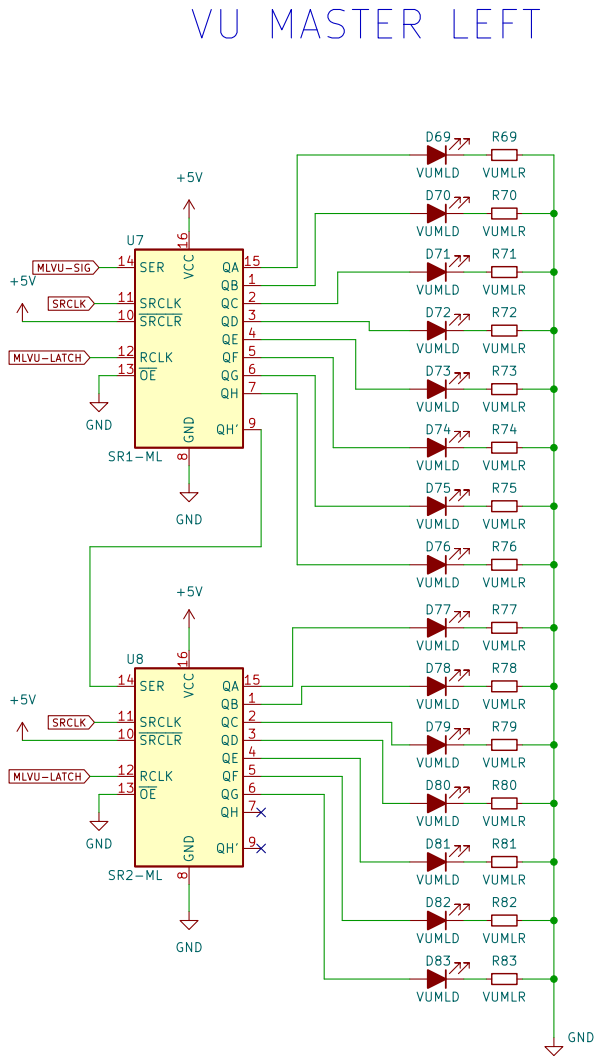
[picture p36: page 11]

MLVU-LATCH MLVU-SIG

8 QH' 9 U8 SR2-ML GND QB 1 ~{SRCLR} 10 SRCLK 11 RCLK 12 ~{OE} 13 SER 14 QA 15 VCC 16 QC 2 QD 3 QE 4 QF 5 QG 6 QH 7 GND

File: VU-ML.kicad_sch Sheet: /VU Leds/VU Master Left/
Id: #/12 Title:

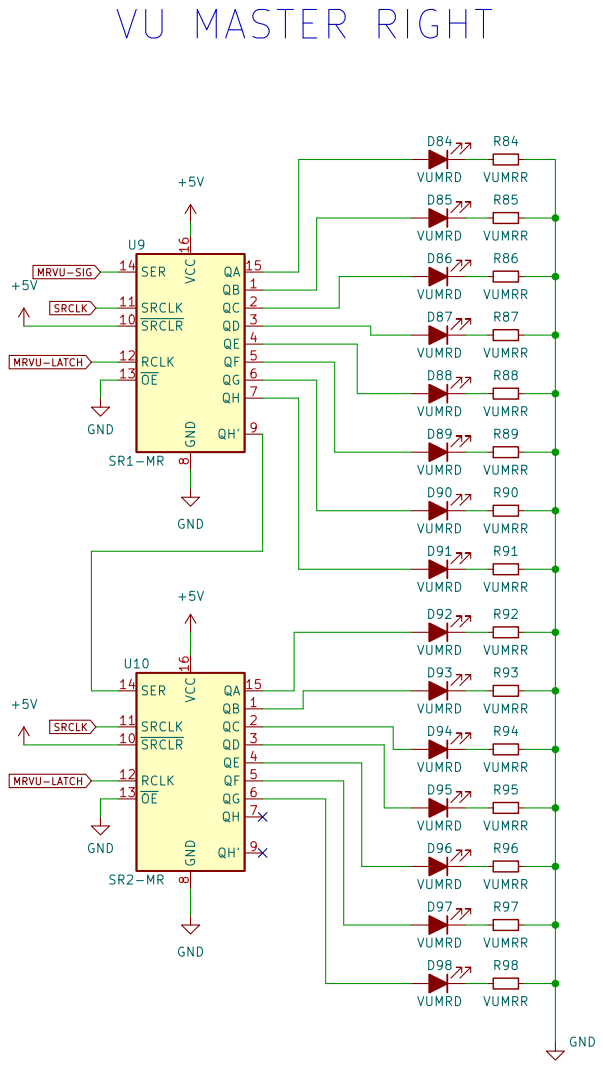
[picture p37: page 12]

SRCLK MRVU-LATCH MRVU-SIG

Sheet: /VU Leds/VU Master Right/ GND

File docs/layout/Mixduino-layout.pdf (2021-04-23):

PADS; CUE; PLAY; TRILLBAR; DECK SWITCH

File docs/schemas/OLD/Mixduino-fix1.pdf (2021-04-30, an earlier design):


SwitchersSheet File: switchers.kicad_sch GND

SCL SWPAD-L2 SWPLAY-L SWSHIFT MPLEX-A0 GAIN-L3 GAIN-L2 GAIN-L1 PFX-3L PFX-2L PFX-1L PFX-3R

SDA GND GND GND

SWPAD-L1 SWPAD-R8 SWPAD-L3 SWPAD-R4 SWPAD-L6 SWPAD-R7 SWBR-PREVIEW

PFX-2R
PFX-1R
TRE-L3 TRE-L2 TRE-L1 PMASTER
SWPAD-L8 GND

File: shift-registers.kicad_sch NeoPixelsSheet File: neopixels.kicad_sch

IC-POTS-1
FILTER-L2 FILTER-L3 BAS-L1 BAS-L2 BAS-L3 MID-L1 MID-L2 MID-L3 GND


File: leds.kicad_sch Sheet: /LedsSheet/
Id: 2/6 Title:


File: potenciometers.kicad_sch Sheet: /PotenciometersSheet/ +5V GND


File: switchers.kicad_sch Sheet: /SwitchersSheet/ SW36 SWFX3L



File: neopixels.kicad_sch Sheet: /NeoPixelsSheet/
Id: 7/6 Title:

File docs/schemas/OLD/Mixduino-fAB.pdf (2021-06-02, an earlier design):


LedsSheet File: leds.kicad_sch ShiftRegistersSheet

SCL SWPAD-L5 SWPAD-L8 SWPAD-L2 SWPLAY-L SWSHIFT SWRANGE-L SWCUE-R MPLEX-A0 GAIN-L3 GAIN-L2 GAIN-L1 PFX-3L PFX-2L PFX-1L PFX-3R

NP_SIG_LEFT SWPAD-L7 SW-DECK-SEL SWFX3-L SWFX2-L SWFX1-L SWSYNC-L SWPLAY-R

SDA GND GND GND

SWPAD-L1 SWPAD-R8 SWPAD-L3 SWPAD-R4 SWPAD-L6 SWPAD-R7 SWBR-PREVIEW

PFX-2R
PFX-1R
TRE-L3 TRE-L2 TRE-L1 PMASTER GND

File: shift-registers.kicad_sch NeoPixelsSheet File: neopixels.kicad_sch

IC-POTS-1
FILTER-L2 FILTER-L3 BAS-L1 BAS-L2 BAS-L3 MID-L1 MID-L2 MID-L3 GND


File: leds.kicad_sch Sheet: /LedsSheet/
Id: 2/6 Title:


File: potenciometers.kicad_sch Sheet: /PotenciometersSheet/ +5V GND


File: switchers.kicad_sch Sheet: /SwitchersSheet/ SW36 SWFX3L



File: neopixels.kicad_sch Sheet: /NeoPixelsSheet/
Id: 7/6 Title:

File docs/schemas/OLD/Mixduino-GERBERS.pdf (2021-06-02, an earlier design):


LedsSheet File: leds.kicad_sch ShiftRegistersSheet

SCL SWPAD-L5 SWPAD-L8 SWPAD-L2 SWPLAY-L SWSHIFT SWRANGE-L SWCUE-R MPLEX-A0 GAIN-L3 GAIN-L2 GAIN-L1 PFX-3L PFX-2L PFX-1L PFX-3R

NP_SIG_LEFT SWPAD-L7 SW-DECK-SEL SWFX3-L SWFX2-L SWFX1-L SWSYNC-L SWPLAY-R

SDA GND GND GND

SWPAD-L1 SWPAD-R8 SWPAD-L3 SWPAD-R4 SWPAD-L6 SWPAD-R7 SWBR-PREVIEW

PFX-2R
PFX-1R
TRE-L3 TRE-L2 TRE-L1 PMASTER GND

File: shift-registers.kicad_sch NeoPixelsSheet File: neopixels.kicad_sch

IC-POTS-1
FILTER-L2 FILTER-L3 BAS-L1 BAS-L2 BAS-L3 MID-L1 MID-L2 MID-L3 GND


File: leds.kicad_sch Sheet: /LedsSheet/
Id: 2/6 Title:


File: potenciometers.kicad_sch Sheet: /PotenciometersSheet/ +5V GND


File: switchers.kicad_sch Sheet: /SwitchersSheet/ SW36 SWFX3L



File: neopixels.kicad_sch Sheet: /NeoPixelsSheet/
Id: 7/6 Title:







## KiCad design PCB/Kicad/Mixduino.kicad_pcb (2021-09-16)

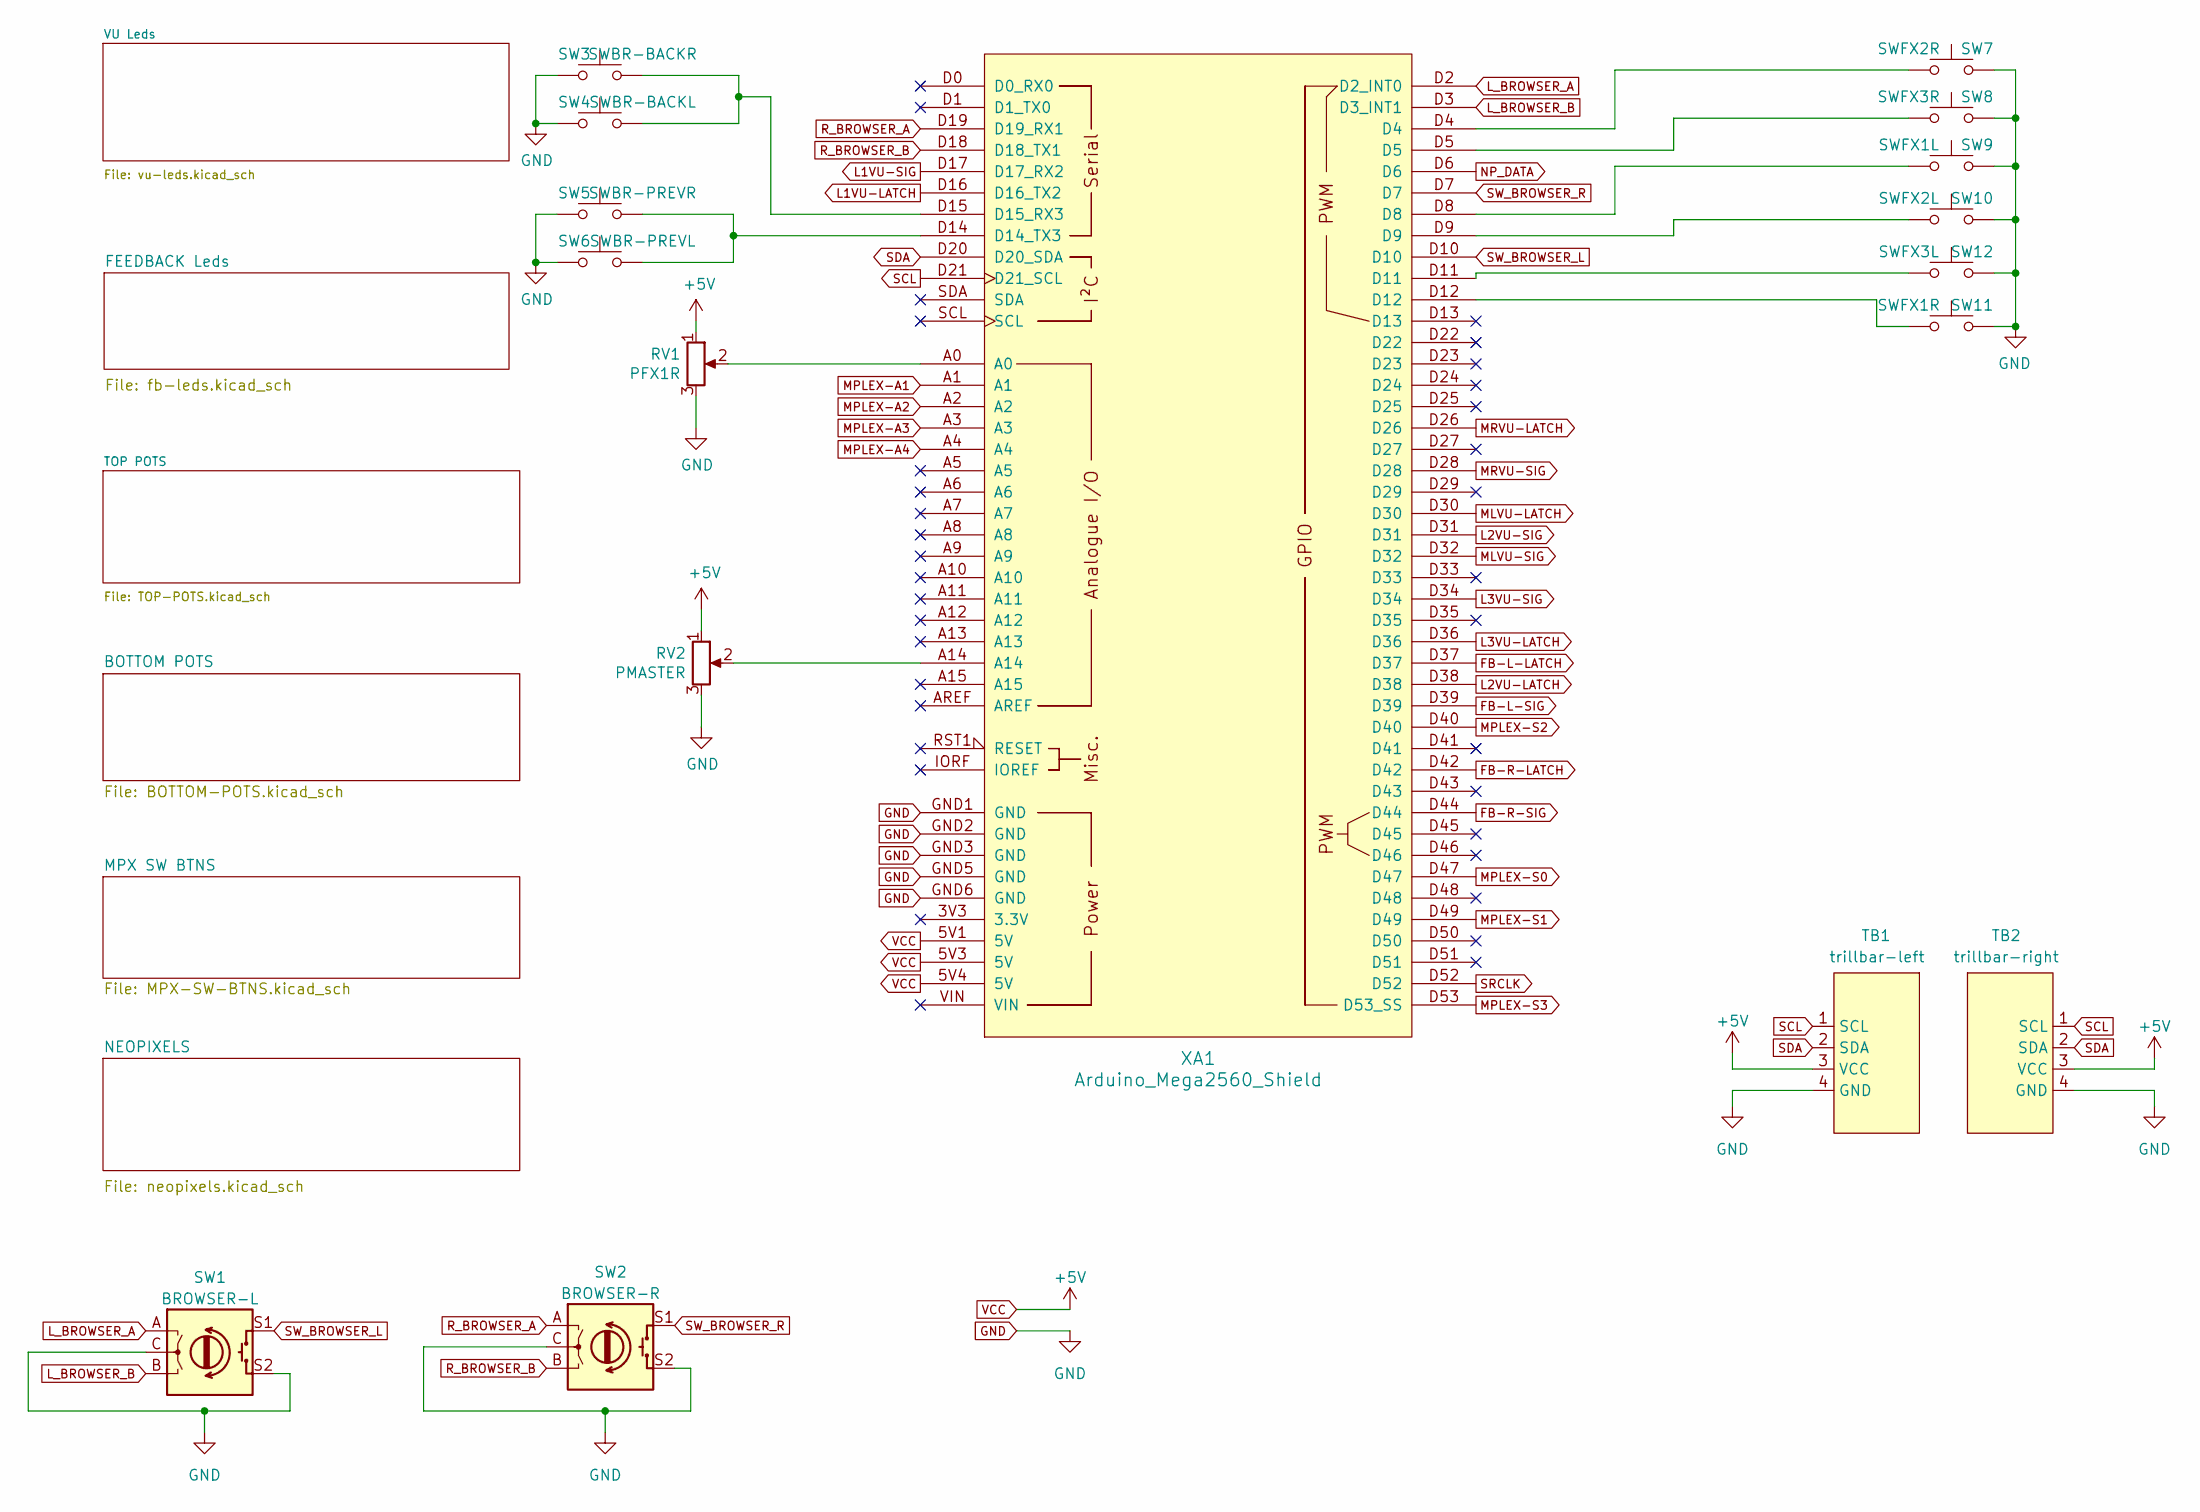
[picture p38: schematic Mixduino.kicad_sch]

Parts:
RV1: PFX1R; Potentiometer_Bourns_PTV09A-1_Single_Vertical
RV2: PMASTER; Potentiometer_Bourns_PTV09A-1_Single_Vertical
SW1: BROWSER-L; RotaryEncoder_Alps_EC11E-Switch_Vertical_H20mm_CircularMoun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
SW2: BROWSER-R; RotaryEncoder_Alps_EC11E-Switch_Vertical_H20mm_CircularMoun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
SW3: SWBR-BACKR; SW_Push_1P1T_NO_6x6mm_H8mm
SW4: SWBR-BACKL; SW_Push_1P1T_NO_6x6mm_H8mm
SW5: SWBR-PREVR; SW_Push_1P1T_NO_6x6mm_H8mm
SW6: SWBR-PREVL; SW_Push_1P1T_NO_6x6mm_H8mm
SW7: SWFX2R; SW_Push_1P1T_NO_6x6mm_H8mm
SW8: SWFX3R; SW_Push_1P1T_NO_6x6mm_H8mm
SW9: SWFX1L; SW_Push_1P1T_NO_6x6mm_H8mm
SW10: SWFX2L; SW_Push_1P1T_NO_6x6mm_H8mm
SW11: SWFX1R; SW_Push_1P1T_NO_6x6mm_H8mm
SW12: SWFX3L; SW_Push_1P1T_NO_6x6mm_H8mm
TB1: trillbar-left; JST_XHP_XH-A-1_1x04_P2.54mm_Horizontal
TB2: trillbar-right; JST_XHP_XH-A-1_1x04_P2.54mm_Horizontal
XA1: Arduino_Mega2560_Shield

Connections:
FB-L-LATCH: XA1.D37; also elsewhere on the board
FB-L-SIG: XA1.D39; also elsewhere on the board
FB-R-LATCH: XA1.D42; also elsewhere on the board
FB-R-SIG: XA1.D44; also elsewhere on the board
GND: RV1.3, RV2.3, SW1.C, SW1.S2, SW2.C, SW2.S2, SW3.1, SW4.1, SW5.1, SW6.1, SW7.1, SW8.1, SW9.1, SW10.1, SW11.1, SW12.1, TB1.4 (GND), TB2.4 (GND), XA1.GND1 (GND), XA1.GND2 (GND), XA1.GND3 (GND), XA1.GND5 (GND), XA1.GND6 (GND); also elsewhere on the board
L1VU-LATCH: XA1.D16 (D16_TX2); also elsewhere on the board
L1VU-SIG: XA1.D17 (D17_RX2); also elsewhere on the board
L2VU-LATCH: XA1.D38; also elsewhere on the board
L2VU-SIG: XA1.D31; also elsewhere on the board
L3VU-LATCH: XA1.D36; also elsewhere on the board
L3VU-SIG: XA1.D34; also elsewhere on the board
L_BROWSER_A: SW1.A, XA1.D2 (D2_INT0)
L_BROWSER_B: SW1.B, XA1.D3 (D3_INT1)
MLVU-LATCH: XA1.D30; also elsewhere on the board
MLVU-SIG: XA1.D32; also elsewhere on the board
MPLEX-A1: XA1.A1; also elsewhere on the board
MPLEX-A2: XA1.A2; also elsewhere on the board
MPLEX-A3: XA1.A3; also elsewhere on the board
MPLEX-A4: XA1.A4; also elsewhere on the board
MPLEX-S0: XA1.D47; also elsewhere on the board
MPLEX-S1: XA1.D49; also elsewhere on the board
MPLEX-S2: XA1.D40; also elsewhere on the board
MPLEX-S3: XA1.D53 (D53_SS); also elsewhere on the board
MRVU-LATCH: XA1.D26; also elsewhere on the board
MRVU-SIG: XA1.D28; also elsewhere on the board
NP_DATA: XA1.D6; also elsewhere on the board
unnamed: RV1.2, XA1.A0
unnamed: RV2.2, XA1.A14
unnamed: SW3.2, SW4.2, XA1.D15 (D15_RX3)
unnamed: SW5.2, SW6.2, XA1.D14 (D14_TX3)
unnamed: SW7.2, XA1.D4
unnamed: SW8.2, XA1.D5
unnamed: SW9.2, XA1.D8
unnamed: SW10.2, XA1.D9
unnamed: SW11.2, XA1.D12
unnamed: SW12.2, XA1.D11
R_BROWSER_A: SW2.A, XA1.D19 (D19_RX1)
R_BROWSER_B: SW2.B, XA1.D18 (D18_TX1)
SCL: TB1.1 (SCL), TB2.1 (SCL), XA1.D21 (D21_SCL)
SDA: TB1.2 (SDA), TB2.2 (SDA), XA1.D20 (D20_SDA)
SRCLK: XA1.D52; also elsewhere on the board
SW_BROWSER_L: SW1.S1, XA1.D10
SW_BROWSER_R: SW2.S1, XA1.D7
VCC: RV1.1, RV2.1, TB1.3 (VCC), TB2.3 (VCC), XA1.5V1 (5V), XA1.5V3 (5V), XA1.5V4 (5V); also elsewhere on the board

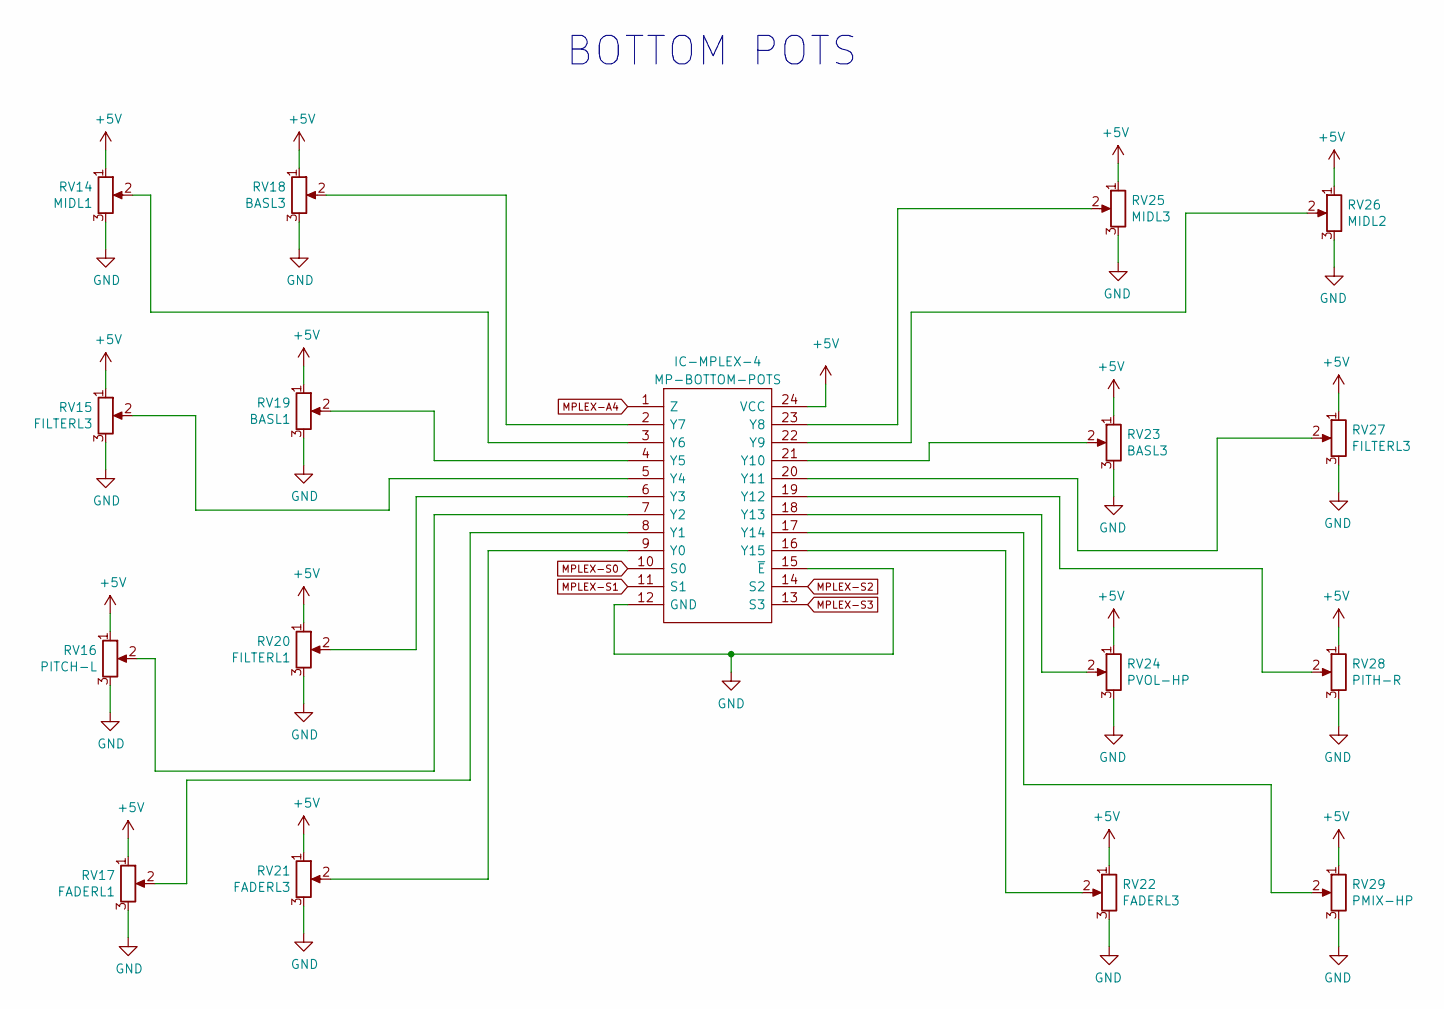
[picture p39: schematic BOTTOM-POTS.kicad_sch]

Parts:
IC-MPLEX-4: MP-BOTTOM-POTS; SOIC-24W_7.5x15.4mm_P1.27mm; Mouser Part Number 771-HC4067D653
RV14: MIDL1; Potentiometer_Bourns_PTV09A-1_Single_Vertical
RV15, RV27: FILTERL3; Potentiometer_Bourns_PTV09A-1_Single_Vertical
RV16: PITCH-L; fader-L75
RV17: FADERL1; fader-L60
RV18, RV23: BASL3; Potentiometer_Bourns_PTV09A-1_Single_Vertical
RV19: BASL1; Potentiometer_Bourns_PTV09A-1_Single_Vertical
RV20: FILTERL1; Potentiometer_Bourns_PTV09A-1_Single_Vertical
RV21, RV22: FADERL3; fader-L60
RV24: PVOL-HP; Potentiometer_Bourns_PTV09A-1_Single_Vertical
RV25: MIDL3; Potentiometer_Bourns_PTV09A-1_Single_Vertical
RV26: MIDL2; Potentiometer_Bourns_PTV09A-1_Single_Vertical
RV28: PITH-R; fader-L75
RV29: PMIX-HP; Potentiometer_Bourns_PTV09A-1_Single_Vertical

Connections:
GND: IC-MPLEX-4.12 (GND), IC-MPLEX-4.15 (~E), RV14.3, RV15.3, RV16.3, RV17.3, RV18.3, RV19.3, RV20.3, RV21.3, RV22.3, RV23.3, RV24.3, RV25.3, RV26.3, RV27.3, RV28.3, RV29.3; also elsewhere on the board
MPLEX-A4: IC-MPLEX-4.1 (Z); also elsewhere on the board
MPLEX-S0: IC-MPLEX-4.10 (S0); also elsewhere on the board
MPLEX-S1: IC-MPLEX-4.11 (S1); also elsewhere on the board
MPLEX-S2: IC-MPLEX-4.14 (S2); also elsewhere on the board
MPLEX-S3: IC-MPLEX-4.13 (S3); also elsewhere on the board
unnamed: IC-MPLEX-4.2 (Y7), RV18.2
unnamed: IC-MPLEX-4.3 (Y6), RV14.2
unnamed: IC-MPLEX-4.4 (Y5), RV19.2
unnamed: IC-MPLEX-4.5 (Y4), RV15.2
unnamed: IC-MPLEX-4.6 (Y3), RV20.2
unnamed: IC-MPLEX-4.7 (Y2), RV16.2
unnamed: IC-MPLEX-4.8 (Y1), RV17.2
unnamed: IC-MPLEX-4.9 (Y0), RV21.2
unnamed: IC-MPLEX-4.16 (Y15), RV22.2
unnamed: IC-MPLEX-4.17 (Y14), RV29.2
unnamed: IC-MPLEX-4.18 (Y13), RV24.2
unnamed: IC-MPLEX-4.19 (Y12), RV28.2
unnamed: IC-MPLEX-4.20 (Y11), RV27.2
unnamed: IC-MPLEX-4.21 (Y10), RV23.2
unnamed: IC-MPLEX-4.22 (Y9), RV26.2
unnamed: IC-MPLEX-4.23 (Y8), RV25.2
VCC: IC-MPLEX-4.24 (VCC), RV14.1, RV15.1, RV16.1, RV17.1, RV18.1, RV19.1, RV20.1, RV21.1, RV22.1, RV23.1, RV24.1, RV25.1, RV26.1, RV27.1, RV28.1, RV29.1; also elsewhere on the board

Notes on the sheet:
BOTTOM POTS

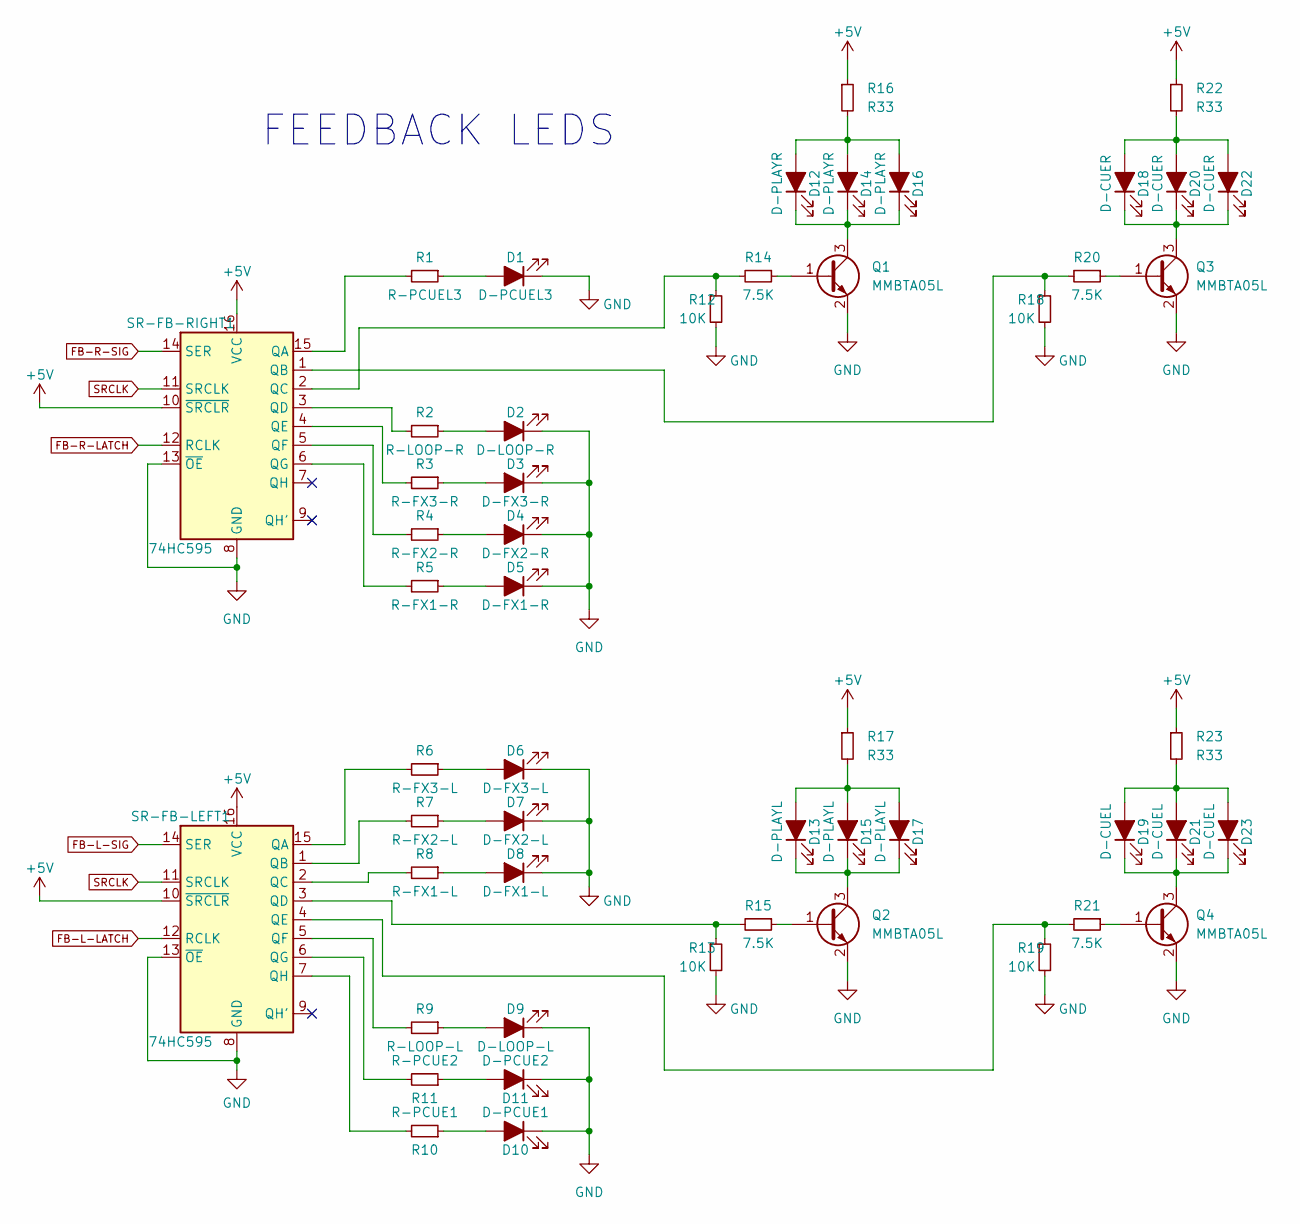
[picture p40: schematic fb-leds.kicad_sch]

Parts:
D1: D-PCUEL3; LED_1206_3216Metric_Pad1.42x1.75mm_HandSolder
D2: D-LOOP-R; LED_1206_3216Metric_Pad1.42x1.75mm_HandSolder
D3: D-FX3-R; LED_1206_3216Metric_Pad1.42x1.75mm_HandSolder
D4: D-FX2-R; LED_1206_3216Metric_Pad1.42x1.75mm_HandSolder
D5: D-FX1-R; LED_1206_3216Metric_Pad1.42x1.75mm_HandSolder
D6: D-FX3-L; LED_1206_3216Metric_Pad1.42x1.75mm_HandSolder
D7: D-FX2-L; LED_1206_3216Metric_Pad1.42x1.75mm_HandSolder
D8: D-FX1-L; LED_1206_3216Metric_Pad1.42x1.75mm_HandSolder
D9: D-LOOP-L; LED_1206_3216Metric_Pad1.42x1.75mm_HandSolder
D10: D-PCUE1; LED_1206_3216Metric_Pad1.42x1.75mm_HandSolder
D11: D-PCUE2; LED_1206_3216Metric_Pad1.42x1.75mm_HandSolder
D12, D14, D16: D-PLAYR; LED_1206_3216Metric_Pad1.42x1.75mm_HandSolder
D13, D15, D17: D-PLAYL; LED_1206_3216Metric_Pad1.42x1.75mm_HandSolder
D18, D20, D22: D-CUER; LED_1206_3216Metric_Pad1.42x1.75mm_HandSolder
D19, D21, D23: D-CUEL; LED_1206_3216Metric_Pad1.42x1.75mm_HandSolder
Q1, Q2, Q3, Q4: MMBTA05L; SOT-23_Handsoldering
R1: R-PCUEL3; R_1206_3216Metric_Pad1.30x1.75mm_HandSolder
R2: R-LOOP-R; R_1206_3216Metric_Pad1.30x1.75mm_HandSolder
R3: R-FX3-R; R_1206_3216Metric_Pad1.30x1.75mm_HandSolder
R4: R-FX2-R; R_1206_3216Metric_Pad1.30x1.75mm_HandSolder
R5: R-FX1-R; R_1206_3216Metric_Pad1.30x1.75mm_HandSolder
R6: R-FX3-L; R_1206_3216Metric_Pad1.30x1.75mm_HandSolder
R7: R-FX2-L; R_1206_3216Metric_Pad1.30x1.75mm_HandSolder
R8: R-FX1-L; R_1206_3216Metric_Pad1.30x1.75mm_HandSolder
R9: R-LOOP-L; R_1206_3216Metric_Pad1.30x1.75mm_HandSolder
R10: R-PCUE1; R_1206_3216Metric_Pad1.30x1.75mm_HandSolder
R11: R-PCUE2; R_1206_3216Metric_Pad1.30x1.75mm_HandSolder
R12, R13, R18, R19: 10K; R_1206_3216Metric_Pad1.30x1.75mm_HandSolder
R14, R15, R20, R21: 7.5K; R_1206_3216Metric_Pad1.30x1.75mm_HandSolder
R16, R17, R22, R23: R33; R_1206_3216Metric_Pad1.30x1.75mm_HandSolder
SR-FB-LEFT1: 74HC595; SO-16_3.9x9.9mm_P1.27mm
SR-FB-RIGHT1: 74HC595; SO-16_3.9x9.9mm_P1.27mm

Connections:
FB-L-LATCH: SR-FB-LEFT1.12 (RCLK); also elsewhere on the board
FB-L-SIG: SR-FB-LEFT1.14 (SER); also elsewhere on the board
FB-R-LATCH: SR-FB-RIGHT1.12 (RCLK); also elsewhere on the board
FB-R-SIG: SR-FB-RIGHT1.14 (SER); also elsewhere on the board
GND: D1.1 (K), D2.1 (K), D3.1 (K), D4.1 (K), D5.1 (K), D6.1 (K), D7.1 (K), D8.1 (K), D9.1 (K), D10.1 (K), D11.1 (K), Q1.2 (E), Q2.2 (E), Q3.2 (E), Q4.2 (E), R12.2, R13.2, R18.2, R19.2, SR-FB-LEFT1.8 (GND), SR-FB-LEFT1.13 (~OE), SR-FB-RIGHT1.8 (GND), SR-FB-RIGHT1.13 (~OE); also elsewhere on the board
unnamed: D1.2 (A), R1.1
unnamed: D2.2 (A), R2.1
unnamed: D3.2 (A), R3.1
unnamed: D4.2 (A), R4.1
unnamed: D5.2 (A), R5.1
unnamed: D6.2 (A), R6.1
unnamed: D7.2 (A), R7.1
unnamed: D8.2 (A), R8.1
unnamed: D9.2 (A), R9.1
unnamed: D10.2 (A), R10.1
unnamed: D11.2 (A), R11.1
unnamed: D12.1 (K), D14.1 (K), D16.1 (K), Q1.3 (C)
unnamed: D12.2 (A), D14.2 (A), D16.2 (A), R16.2
unnamed: D13.1 (K), D15.1 (K), D17.1 (K), Q2.3 (C)
unnamed: D13.2 (A), D15.2 (A), D17.2 (A), R17.2
unnamed: D18.1 (K), D20.1 (K), D22.1 (K), Q3.3 (C)
unnamed: D18.2 (A), D20.2 (A), D22.2 (A), R22.2
unnamed: D19.1 (K), D21.1 (K), D23.1 (K), Q4.3 (C)
unnamed: D19.2 (A), D21.2 (A), D23.2 (A), R23.2
unnamed: Q1.1 (B), R14.1
unnamed: Q2.1 (B), R15.1
unnamed: Q3.1 (B), R20.1
unnamed: Q4.1 (B), R21.1
unnamed: R1.2, SR-FB-RIGHT1.15 (QA)
unnamed: R2.2, SR-FB-RIGHT1.3 (QD)
unnamed: R3.2, SR-FB-RIGHT1.4 (QE)
unnamed: R4.2, SR-FB-RIGHT1.5 (QF)
unnamed: R5.2, SR-FB-RIGHT1.6 (QG)
unnamed: R6.2, SR-FB-LEFT1.15 (QA)
unnamed: R7.2, SR-FB-LEFT1.1 (QB)
unnamed: R8.2, SR-FB-LEFT1.2 (QC)
unnamed: R9.2, SR-FB-LEFT1.5 (QF)
unnamed: R10.2, SR-FB-LEFT1.7 (QH)
unnamed: R11.2, SR-FB-LEFT1.6 (QG)
unnamed: R12.1, R14.2, SR-FB-RIGHT1.2 (QC)
unnamed: R13.1, R15.2, SR-FB-LEFT1.3 (QD)
unnamed: R18.1, R20.2, SR-FB-RIGHT1.1 (QB)
unnamed: R19.1, R21.2, SR-FB-LEFT1.4 (QE)
SRCLK: SR-FB-LEFT1.11 (SRCLK), SR-FB-RIGHT1.11 (SRCLK); also elsewhere on the board
VCC: R16.1, R17.1, R22.1, R23.1, SR-FB-LEFT1.10 (~SRCLR), SR-FB-LEFT1.16 (VCC), SR-FB-RIGHT1.10 (~SRCLR), SR-FB-RIGHT1.16 (VCC); also elsewhere on the board

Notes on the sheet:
FEEDBACK LEDS

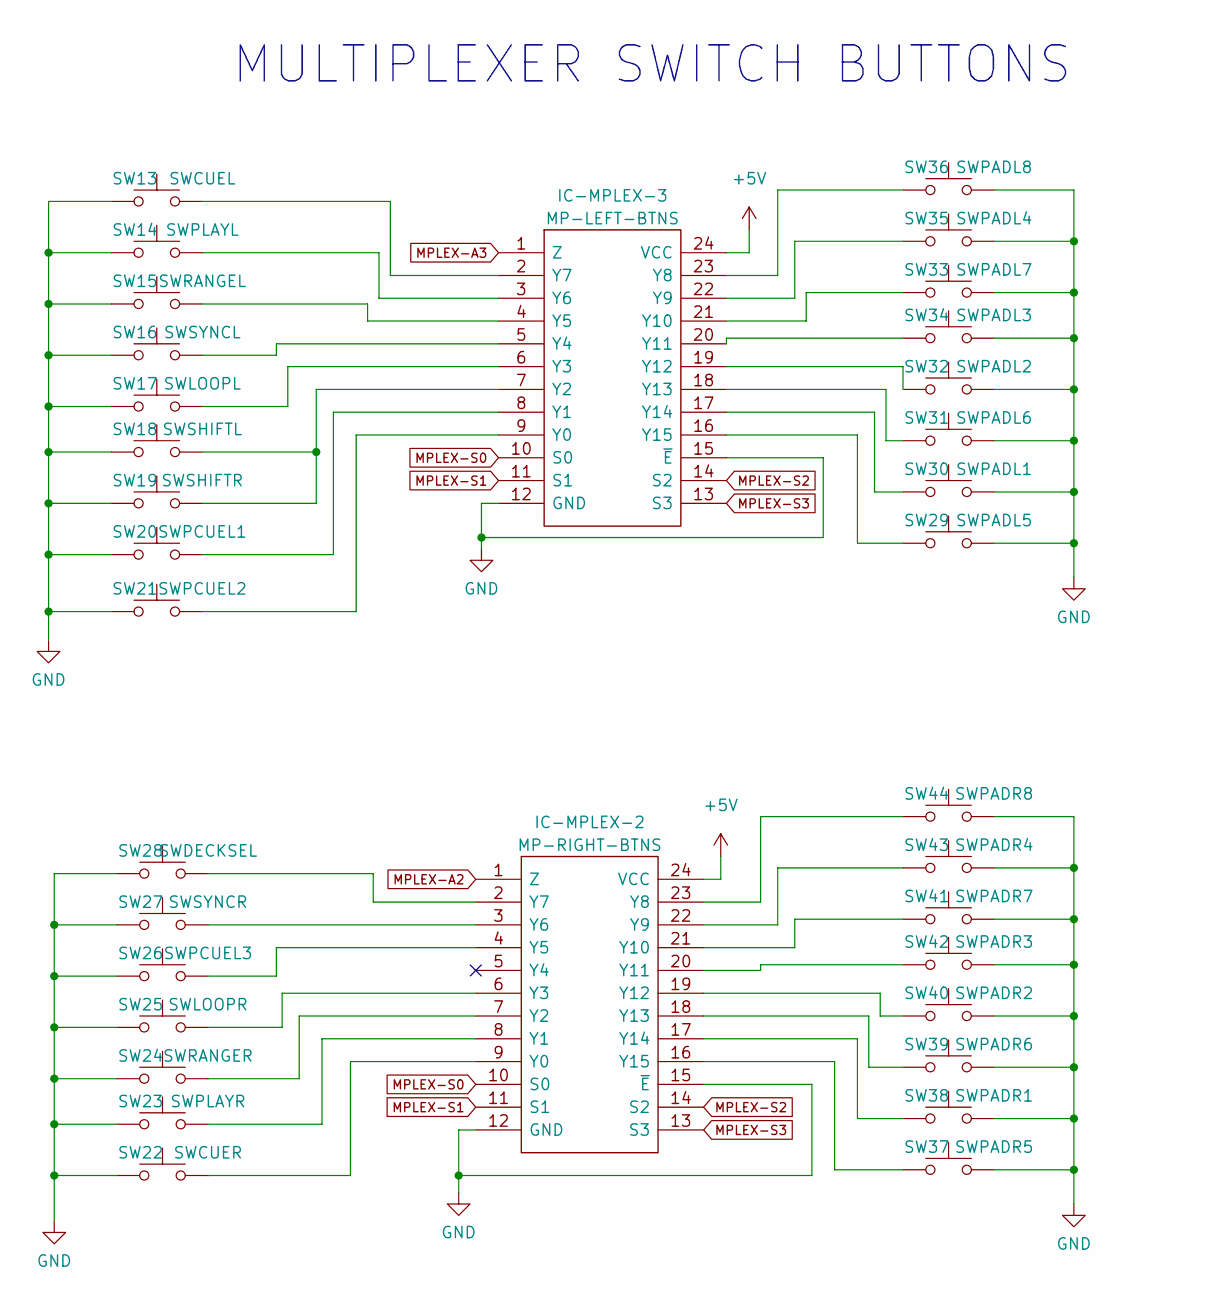
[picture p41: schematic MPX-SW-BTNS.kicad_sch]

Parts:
IC-MPLEX-2: MP-RIGHT-BTNS; SOIC-24W_7.5x15.4mm_P1.27mm; Mouser Part Number 771-HC4067D653
IC-MPLEX-3: MP-LEFT-BTNS; SOIC-24W_7.5x15.4mm_P1.27mm; Mouser Part Number 771-HC4067D653
SW13: SWCUEL; SW_Push_1P1T_NO_6x6mm_H8mm
SW14: SWPLAYL; SW_Push_1P1T_NO_6x6mm_H8mm
SW15: SWRANGEL; SW_Push_1P1T_NO_6x6mm_H8mm
SW16: SWSYNCL; SW_Push_1P1T_NO_6x6mm_H8mm
SW17: SWLOOPL; SW_Push_1P1T_NO_6x6mm_H8mm
SW18: SWSHIFTL; SW_Push_1P1T_NO_6x6mm_H8mm
SW19: SWSHIFTR; SW_Push_1P1T_NO_6x6mm_H8mm
SW20: SWPCUEL1; SW_Push_1P1T_NO_6x6mm_H8mm
SW21: SWPCUEL2; SW_Push_1P1T_NO_6x6mm_H8mm
SW22: SWCUER; SW_Push_1P1T_NO_6x6mm_H8mm
SW23: SWPLAYR; SW_Push_1P1T_NO_6x6mm_H8mm
SW24: SWRANGER; SW_Push_1P1T_NO_6x6mm_H8mm
SW25: SWLOOPR; SW_Push_1P1T_NO_6x6mm_H8mm
SW26: SWPCUEL3; SW_Push_1P1T_NO_6x6mm_H8mm
SW27: SWSYNCR; SW_Push_1P1T_NO_6x6mm_H8mm
SW28: SWDECKSEL; SW_Push_1P1T_NO_6x6mm_H8mm
SW29: SWPADL5; sw-pad
SW30: SWPADL1; sw-pad
SW31: SWPADL6; sw-pad
SW32: SWPADL2; sw-pad
SW33: SWPADL7; sw-pad
SW34: SWPADL3; sw-pad
SW35: SWPADL4; sw-pad
SW36: SWPADL8; sw-pad
SW37: SWPADR5; sw-pad
SW38: SWPADR1; sw-pad
SW39: SWPADR6; sw-pad
SW40: SWPADR2; sw-pad
SW41: SWPADR7; sw-pad
SW42: SWPADR3; sw-pad
SW43: SWPADR4; sw-pad
SW44: SWPADR8; sw-pad

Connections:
GND: IC-MPLEX-2.12 (GND), IC-MPLEX-2.15 (~E), IC-MPLEX-3.12 (GND), IC-MPLEX-3.15 (~E), SW13.1, SW14.1, SW15.1, SW16.1, SW17.1, SW18.1, SW19.1, SW20.1, SW21.1, SW22.1, SW23.1, SW24.1, SW25.1, SW26.1, SW27.1, SW28.1, SW29.2, SW30.2, SW31.2, SW32.2, SW33.2, SW34.2, SW35.2, SW36.2, SW37.2, SW38.2, SW39.2, SW40.2, SW41.2, SW42.2, SW43.2, SW44.2; also elsewhere on the board
MPLEX-A2: IC-MPLEX-2.1 (Z); also elsewhere on the board
MPLEX-A3: IC-MPLEX-3.1 (Z); also elsewhere on the board
MPLEX-S0: IC-MPLEX-2.10 (S0), IC-MPLEX-3.10 (S0); also elsewhere on the board
MPLEX-S1: IC-MPLEX-2.11 (S1), IC-MPLEX-3.11 (S1); also elsewhere on the board
MPLEX-S2: IC-MPLEX-2.14 (S2), IC-MPLEX-3.14 (S2); also elsewhere on the board
MPLEX-S3: IC-MPLEX-2.13 (S3), IC-MPLEX-3.13 (S3); also elsewhere on the board
unnamed: IC-MPLEX-2.2 (Y7), SW28.2
unnamed: IC-MPLEX-2.3 (Y6), SW27.2
unnamed: IC-MPLEX-2.4 (Y5), SW26.2
unnamed: IC-MPLEX-2.6 (Y3), SW25.2
unnamed: IC-MPLEX-2.7 (Y2), SW24.2
unnamed: IC-MPLEX-2.8 (Y1), SW23.2
unnamed: IC-MPLEX-2.9 (Y0), SW22.2
unnamed: IC-MPLEX-2.16 (Y15), SW37.1
unnamed: IC-MPLEX-2.17 (Y14), SW38.1
unnamed: IC-MPLEX-2.18 (Y13), SW39.1
unnamed: IC-MPLEX-2.19 (Y12), SW40.1
unnamed: IC-MPLEX-2.20 (Y11), SW42.1
unnamed: IC-MPLEX-2.21 (Y10), SW41.1
unnamed: IC-MPLEX-2.22 (Y9), SW43.1
unnamed: IC-MPLEX-2.23 (Y8), SW44.1
unnamed: IC-MPLEX-3.2 (Y7), SW13.2
unnamed: IC-MPLEX-3.3 (Y6), SW14.2
unnamed: IC-MPLEX-3.4 (Y5), SW15.2
unnamed: IC-MPLEX-3.5 (Y4), SW16.2
unnamed: IC-MPLEX-3.6 (Y3), SW17.2
unnamed: IC-MPLEX-3.7 (Y2), SW18.2, SW19.2
unnamed: IC-MPLEX-3.8 (Y1), SW20.2
unnamed: IC-MPLEX-3.9 (Y0), SW21.2
unnamed: IC-MPLEX-3.16 (Y15), SW29.1
unnamed: IC-MPLEX-3.17 (Y14), SW30.1
unnamed: IC-MPLEX-3.18 (Y13), SW31.1
unnamed: IC-MPLEX-3.19 (Y12), SW32.1
unnamed: IC-MPLEX-3.20 (Y11), SW34.1
unnamed: IC-MPLEX-3.21 (Y10), SW33.1
unnamed: IC-MPLEX-3.22 (Y9), SW35.1
unnamed: IC-MPLEX-3.23 (Y8), SW36.1
VCC: IC-MPLEX-2.24 (VCC), IC-MPLEX-3.24 (VCC); also elsewhere on the board

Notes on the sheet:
MULTIPLEXER SWITCH BUTTONS

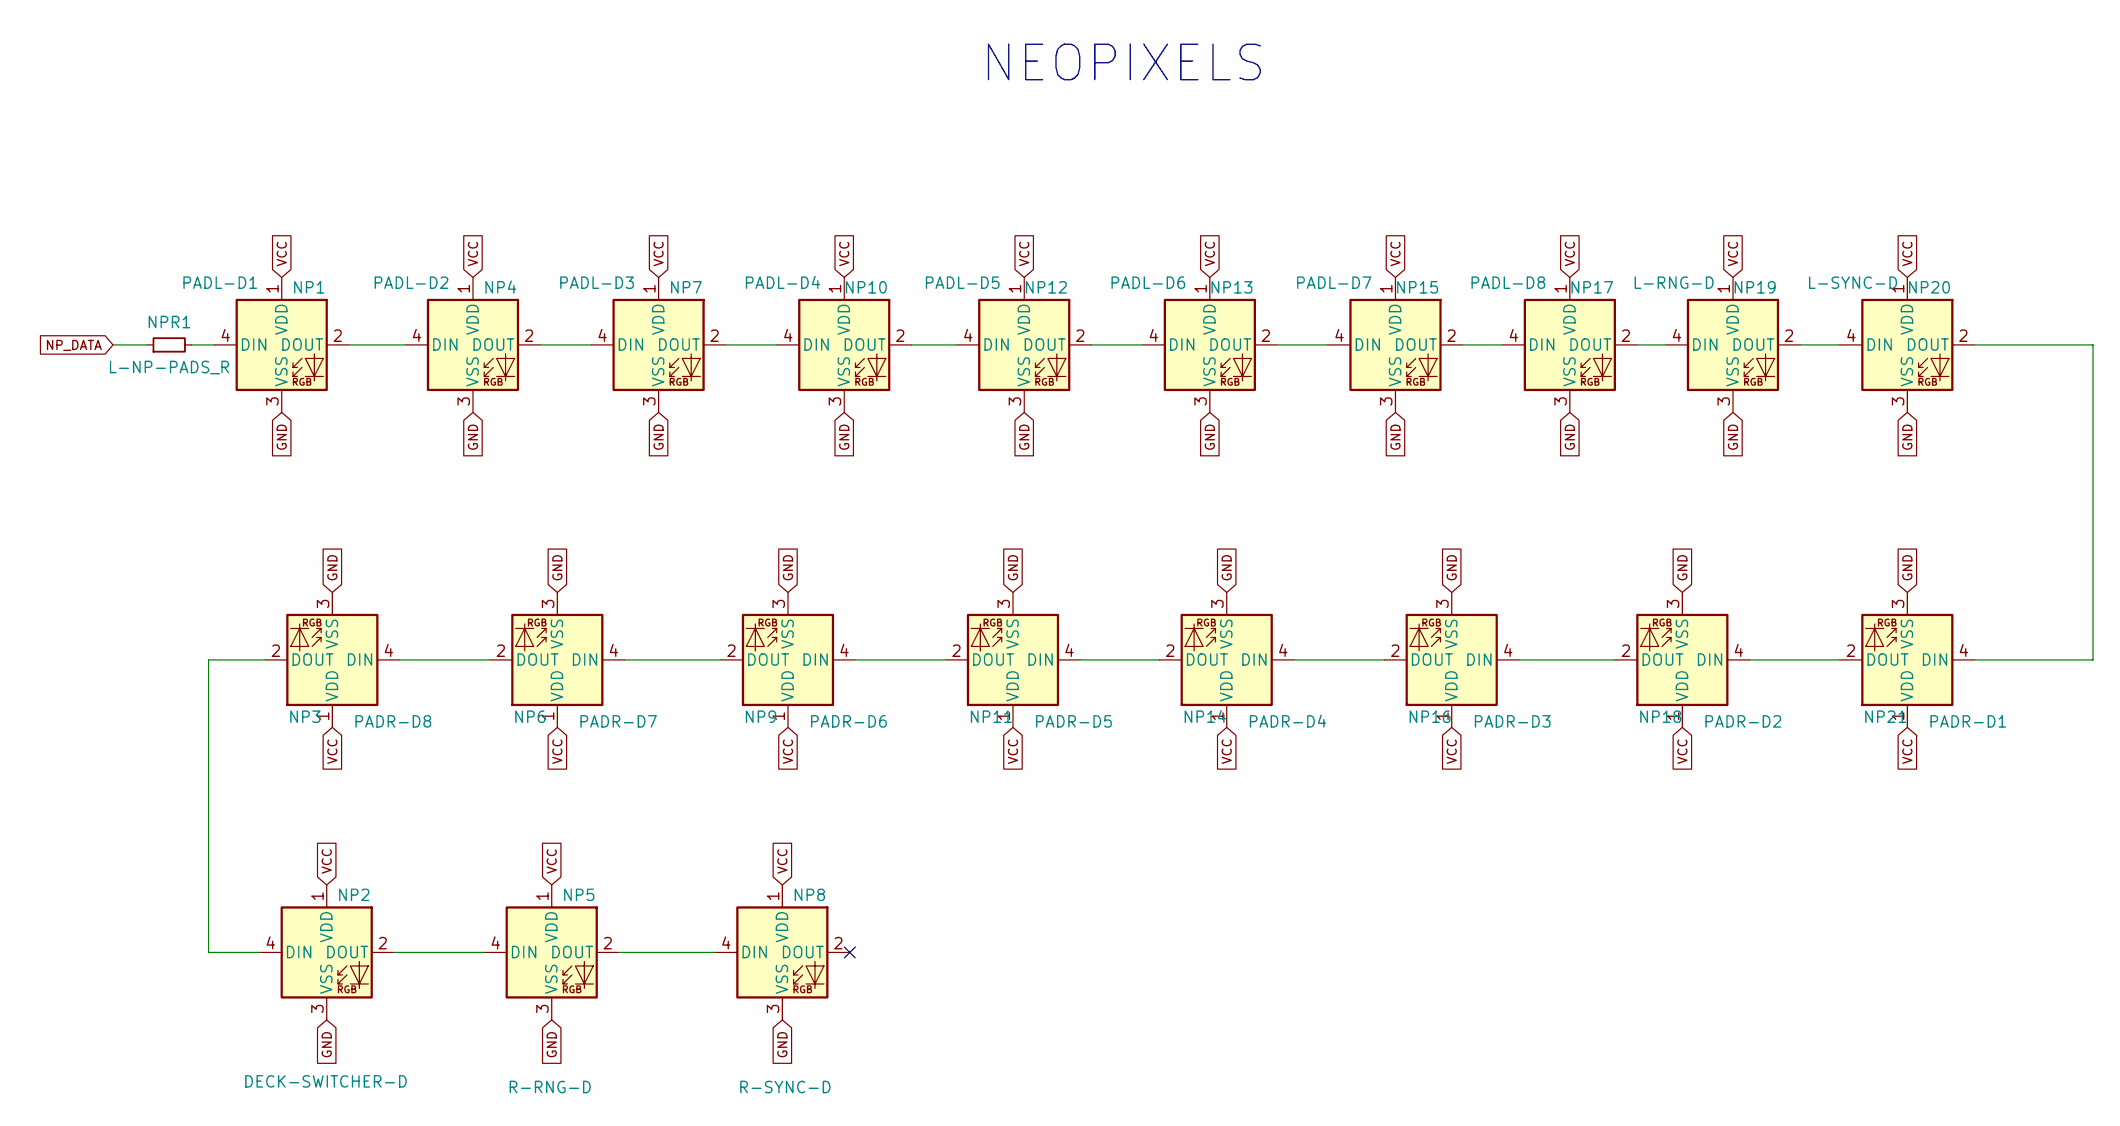
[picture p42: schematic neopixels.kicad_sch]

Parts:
NP1: PADL-D1; LED_WS2812B_PLCC4_5.0x5.0mm_P3.2mm
NP2: DECK-SWITCHER-D; LED_WS2812B_PLCC4_5.0x5.0mm_P3.2mm
NP3: PADR-D8; LED_WS2812B_PLCC4_5.0x5.0mm_P3.2mm
NP4: PADL-D2; LED_WS2812B_PLCC4_5.0x5.0mm_P3.2mm
NP5: R-RNG-D; LED_WS2812B_PLCC4_5.0x5.0mm_P3.2mm
NP6: PADR-D7; LED_WS2812B_PLCC4_5.0x5.0mm_P3.2mm
NP7: PADL-D3; LED_WS2812B_PLCC4_5.0x5.0mm_P3.2mm
NP8: R-SYNC-D; LED_WS2812B_PLCC4_5.0x5.0mm_P3.2mm
NP9: PADR-D6; LED_WS2812B_PLCC4_5.0x5.0mm_P3.2mm
NP10: PADL-D4; LED_WS2812B_PLCC4_5.0x5.0mm_P3.2mm
NP11: PADR-D5; LED_WS2812B_PLCC4_5.0x5.0mm_P3.2mm
NP12: PADL-D5; LED_WS2812B_PLCC4_5.0x5.0mm_P3.2mm
NP13: PADL-D6; LED_WS2812B_PLCC4_5.0x5.0mm_P3.2mm
NP14: PADR-D4; LED_WS2812B_PLCC4_5.0x5.0mm_P3.2mm
NP15: PADL-D7; LED_WS2812B_PLCC4_5.0x5.0mm_P3.2mm
NP16: PADR-D3; LED_WS2812B_PLCC4_5.0x5.0mm_P3.2mm
NP17: PADL-D8; LED_WS2812B_PLCC4_5.0x5.0mm_P3.2mm
NP18: PADR-D2; LED_WS2812B_PLCC4_5.0x5.0mm_P3.2mm
NP19: L-RNG-D; LED_WS2812B_PLCC4_5.0x5.0mm_P3.2mm
NP20: L-SYNC-D; LED_WS2812B_PLCC4_5.0x5.0mm_P3.2mm
NP21: PADR-D1; LED_WS2812B_PLCC4_5.0x5.0mm_P3.2mm
NPR1: L-NP-PADS_R; R_1206_3216Metric_Pad1.30x1.75mm_HandSolder

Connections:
GND: NP1.3 (VSS), NP2.3 (VSS), NP3.3 (VSS), NP4.3 (VSS), NP5.3 (VSS), NP6.3 (VSS), NP7.3 (VSS), NP8.3 (VSS), NP9.3 (VSS), NP10.3 (VSS), NP11.3 (VSS), NP12.3 (VSS), NP13.3 (VSS), NP14.3 (VSS), NP15.3 (VSS), NP16.3 (VSS), NP17.3 (VSS), NP18.3 (VSS), NP19.3 (VSS), NP20.3 (VSS), NP21.3 (VSS); also elsewhere on the board
NP_DATA: NPR1.1; also elsewhere on the board
unnamed: NP1.4 (DIN), NPR1.2
unnamed: NP19.2 (DOUT), NP20.4 (DIN)
unnamed: NP20.2 (DOUT), NP21.4 (DIN)
VCC: NP1.1 (VDD), NP2.1 (VDD), NP3.1 (VDD), NP4.1 (VDD), NP5.1 (VDD), NP6.1 (VDD), NP7.1 (VDD), NP8.1 (VDD), NP9.1 (VDD), NP10.1 (VDD), NP11.1 (VDD), NP12.1 (VDD), NP13.1 (VDD), NP14.1 (VDD), NP15.1 (VDD), NP16.1 (VDD), NP17.1 (VDD), NP18.1 (VDD), NP19.1 (VDD), NP20.1 (VDD), NP21.1 (VDD); also elsewhere on the board

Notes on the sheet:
NEOPIXELS

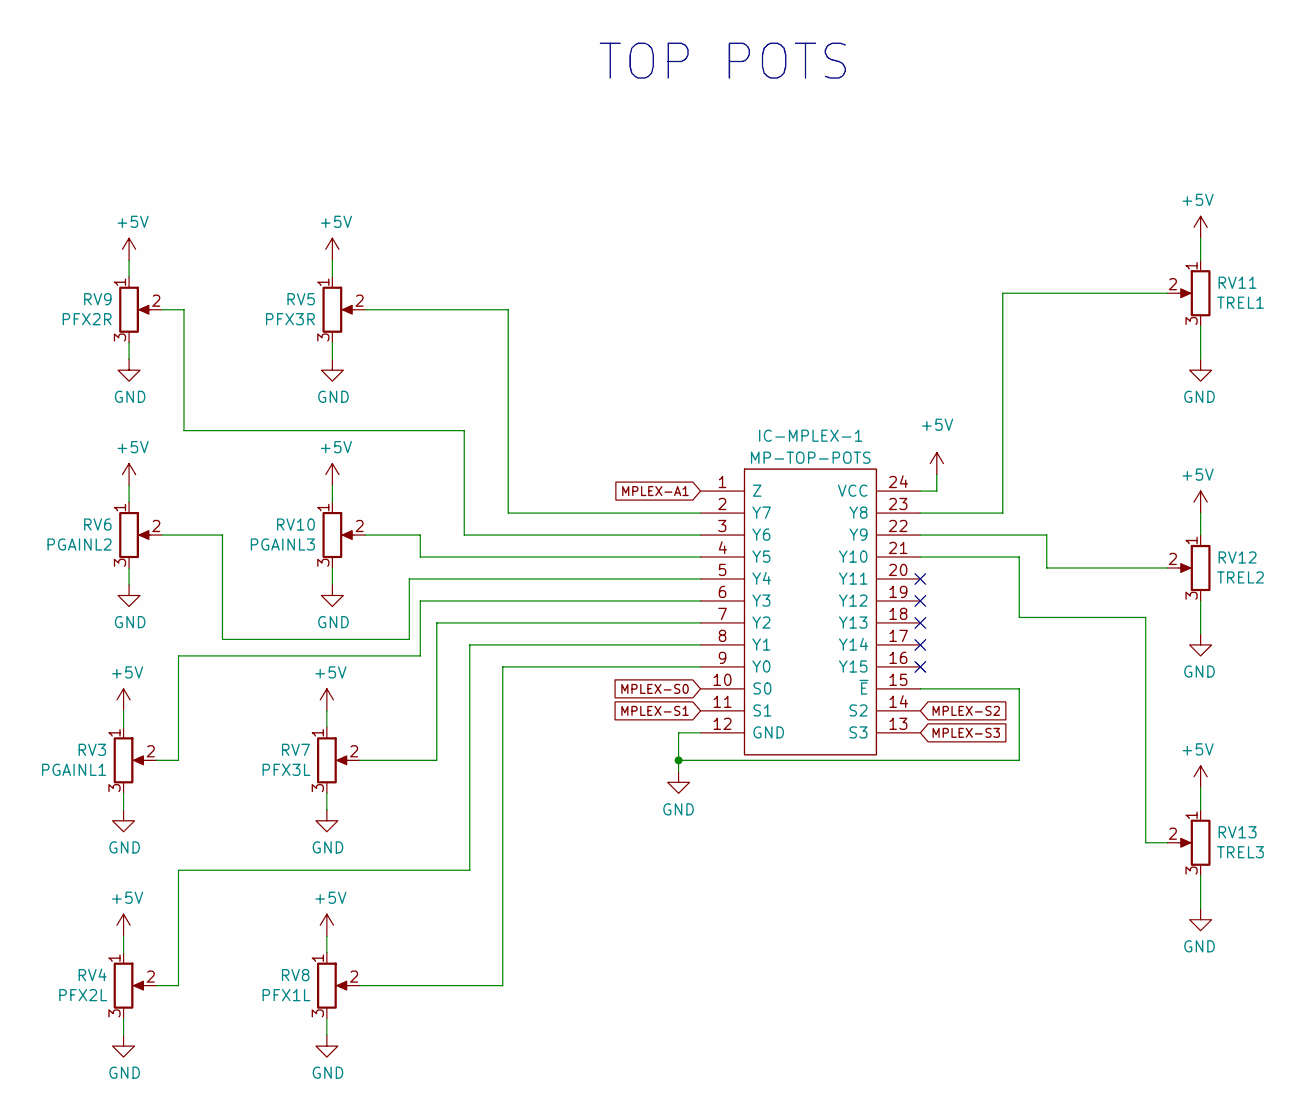
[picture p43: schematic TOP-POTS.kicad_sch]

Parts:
IC-MPLEX-1: MP-TOP-POTS; SOIC-24W_7.5x15.4mm_P1.27mm; Mouser Part Number 771-HC4067D653
RV3: PGAINL1; Potentiometer_Bourns_PTV09A-1_Single_Vertical
RV4: PFX2L; Potentiometer_Bourns_PTV09A-1_Single_Vertical
RV5: PFX3R; Potentiometer_Bourns_PTV09A-1_Single_Vertical
RV6: PGAINL2; Potentiometer_Bourns_PTV09A-1_Single_Vertical
RV7: PFX3L; Potentiometer_Bourns_PTV09A-1_Single_Vertical
RV8: PFX1L; Potentiometer_Bourns_PTV09A-1_Single_Vertical
RV9: PFX2R; Potentiometer_Bourns_PTV09A-1_Single_Vertical
RV10: PGAINL3; Potentiometer_Bourns_PTV09A-1_Single_Vertical
RV11: TREL1; Potentiometer_Bourns_PTV09A-1_Single_Vertical
RV12: TREL2; Potentiometer_Bourns_PTV09A-1_Single_Vertical
RV13: TREL3; Potentiometer_Bourns_PTV09A-1_Single_Vertical

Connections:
GND: IC-MPLEX-1.12 (GND), IC-MPLEX-1.15 (~E), RV3.3, RV4.3, RV5.3, RV6.3, RV7.3, RV8.3, RV9.3, RV10.3, RV11.3, RV12.3, RV13.3; also elsewhere on the board
MPLEX-A1: IC-MPLEX-1.1 (Z); also elsewhere on the board
MPLEX-S0: IC-MPLEX-1.10 (S0); also elsewhere on the board
MPLEX-S1: IC-MPLEX-1.11 (S1); also elsewhere on the board
MPLEX-S2: IC-MPLEX-1.14 (S2); also elsewhere on the board
MPLEX-S3: IC-MPLEX-1.13 (S3); also elsewhere on the board
unnamed: IC-MPLEX-1.2 (Y7), RV5.2
unnamed: IC-MPLEX-1.3 (Y6), RV9.2
unnamed: IC-MPLEX-1.4 (Y5), RV10.2
unnamed: IC-MPLEX-1.5 (Y4), RV6.2
unnamed: IC-MPLEX-1.6 (Y3), RV3.2
unnamed: IC-MPLEX-1.7 (Y2), RV7.2
unnamed: IC-MPLEX-1.8 (Y1), RV4.2
unnamed: IC-MPLEX-1.9 (Y0), RV8.2
unnamed: IC-MPLEX-1.21 (Y10), RV13.2
unnamed: IC-MPLEX-1.22 (Y9), RV12.2
unnamed: IC-MPLEX-1.23 (Y8), RV11.2
VCC: IC-MPLEX-1.24 (VCC), RV3.1, RV4.1, RV5.1, RV6.1, RV7.1, RV8.1, RV9.1, RV10.1, RV11.1, RV12.1, RV13.1; also elsewhere on the board

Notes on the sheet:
TOP POTS

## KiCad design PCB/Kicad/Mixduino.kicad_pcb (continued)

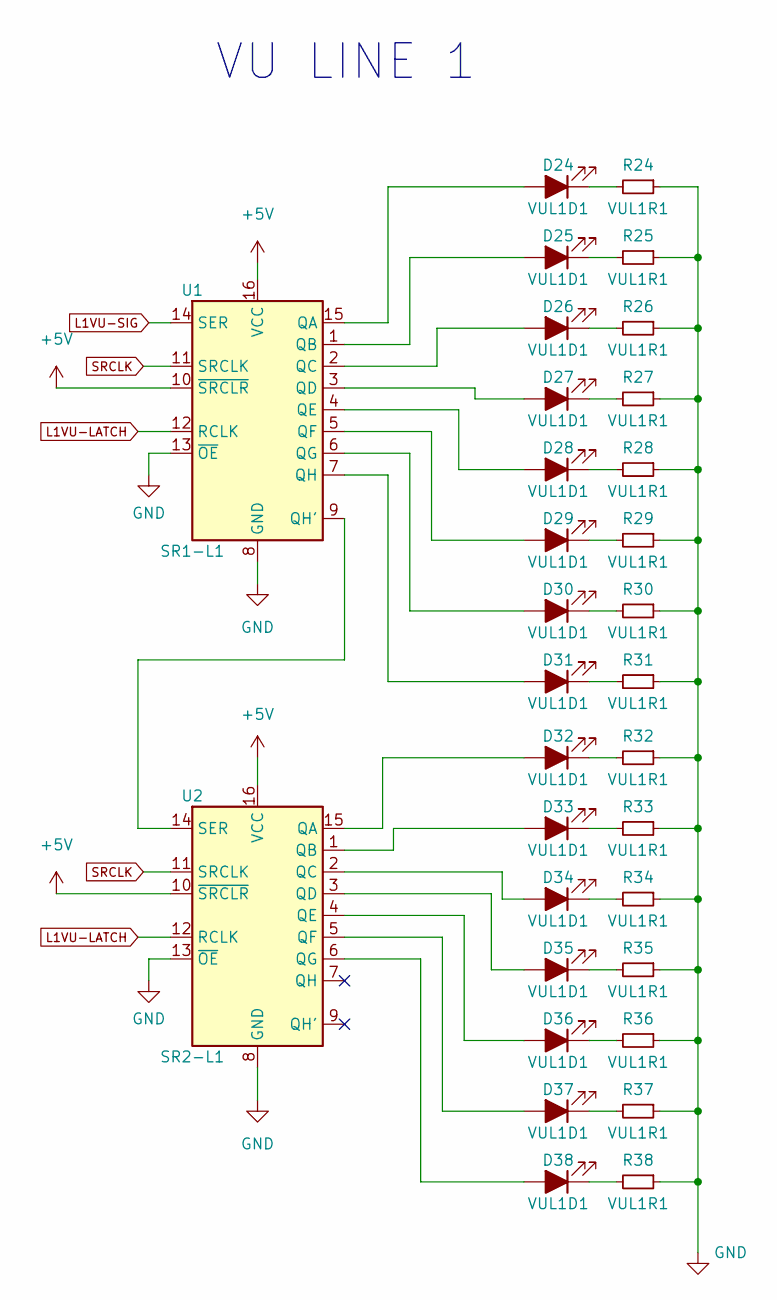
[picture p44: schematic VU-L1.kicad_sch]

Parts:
D24, D25, D26, D27, D28, D29, D30, D31, D32: VUL1D1; LED_GREEN
D33, D34, D35, D36: VUL1D1; LED_YELLOW
D37, D38: VUL1D1; LED_RED
R24, R25, R26, R27, R28, R29, R30, R31, R32, R33, R34, R35, R36, R37, R38: VUL1R1; R_1206_3216Metric_Pad1.30x1.75mm_HandSolder
U1: SR1-L1; SO-16_3.9x9.9mm_P1.27mm
U2: SR2-L1; SO-16_3.9x9.9mm_P1.27mm

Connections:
GND: R24.1, R25.1, R26.1, R27.1, R28.1, R29.1, R30.1, R31.1, R32.1, R33.1, R34.1, R35.1, R36.1, R37.1, R38.1, U1.8 (GND), U1.13 (~OE), U2.8 (GND), U2.13 (~OE); also elsewhere on the board
L1VU-LATCH: U1.12 (RCLK), U2.12 (RCLK); also elsewhere on the board
L1VU-SIG: U1.14 (SER); also elsewhere on the board
unnamed: D24.1 (K), R24.2
unnamed: D24.2 (A), U1.15 (QA)
unnamed: D25.1 (K), R25.2
unnamed: D25.2 (A), U1.1 (QB)
unnamed: D26.1 (K), R26.2
unnamed: D26.2 (A), U1.2 (QC)
unnamed: D27.1 (K), R27.2
unnamed: D27.2 (A), U1.3 (QD)
unnamed: D28.1 (K), R28.2
unnamed: D28.2 (A), U1.4 (QE)
unnamed: D29.1 (K), R29.2
unnamed: D29.2 (A), U1.5 (QF)
unnamed: D30.1 (K), R30.2
unnamed: D30.2 (A), U1.6 (QG)
unnamed: D31.1 (K), R31.2
unnamed: D31.2 (A), U1.7 (QH)
unnamed: D32.1 (K), R32.2
unnamed: D32.2 (A), U2.15 (QA)
unnamed: D33.1 (K), R33.2
unnamed: D33.2 (A), U2.1 (QB)
unnamed: D34.1 (K), R34.2
unnamed: D34.2 (A), U2.2 (QC)
unnamed: D35.1 (K), R35.2
unnamed: D35.2 (A), U2.3 (QD)
unnamed: D36.1 (K), R36.2
unnamed: D36.2 (A), U2.4 (QE)
unnamed: D37.1 (K), R37.2
unnamed: D37.2 (A), U2.5 (QF)
unnamed: D38.1 (K), R38.2
unnamed: D38.2 (A), U2.6 (QG)
unnamed: U1.9 (QH'), U2.14 (SER)
SRCLK: U1.11 (SRCLK), U2.11 (SRCLK); also elsewhere on the board
VCC: U1.10 (~SRCLR), U1.16 (VCC), U2.10 (~SRCLR), U2.16 (VCC); also elsewhere on the board

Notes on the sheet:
VU LINE 1

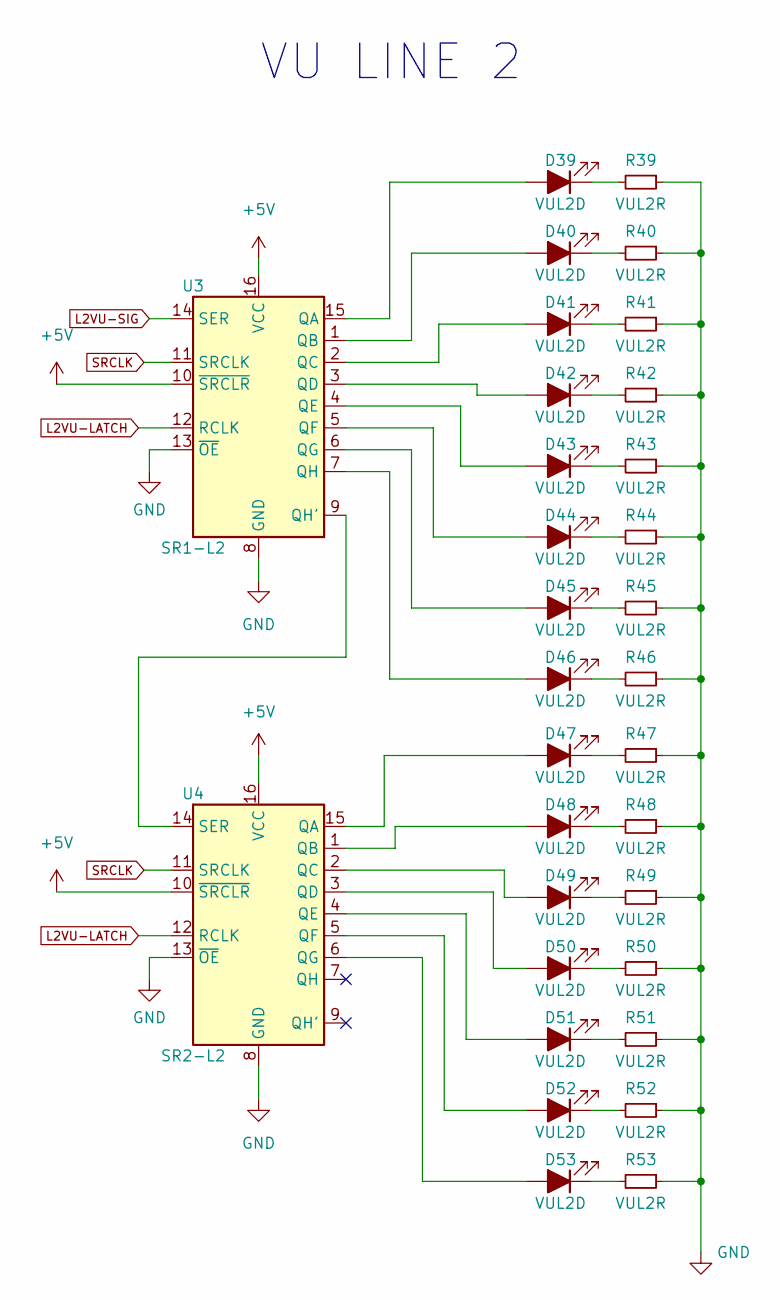
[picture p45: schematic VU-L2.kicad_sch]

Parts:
D39, D40, D41, D42, D43, D44, D45, D46, D47: VUL2D; LED_GREEN
D48, D49, D50, D51: VUL2D; LED_YELLOW
D52, D53: VUL2D; LED_RED
R39, R40, R41, R42, R43, R44, R45, R46, R47, R48, R49, R50, R51, R52, R53: VUL2R; R_1206_3216Metric_Pad1.30x1.75mm_HandSolder
U3: SR1-L2; SO-16_3.9x9.9mm_P1.27mm
U4: SR2-L2; SO-16_3.9x9.9mm_P1.27mm

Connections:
GND: R39.1, R40.1, R41.1, R42.1, R43.1, R44.1, R45.1, R46.1, R47.1, R48.1, R49.1, R50.1, R51.1, R52.1, R53.1, U3.8 (GND), U3.13 (~OE), U4.8 (GND), U4.13 (~OE); also elsewhere on the board
L2VU-LATCH: U3.12 (RCLK), U4.12 (RCLK); also elsewhere on the board
L2VU-SIG: U3.14 (SER); also elsewhere on the board
unnamed: D39.1 (K), R39.2
unnamed: D39.2 (A), U3.15 (QA)
unnamed: D40.1 (K), R40.2
unnamed: D40.2 (A), U3.1 (QB)
unnamed: D41.1 (K), R41.2
unnamed: D41.2 (A), U3.2 (QC)
unnamed: D42.1 (K), R42.2
unnamed: D42.2 (A), U3.3 (QD)
unnamed: D43.1 (K), R43.2
unnamed: D43.2 (A), U3.4 (QE)
unnamed: D44.1 (K), R44.2
unnamed: D44.2 (A), U3.5 (QF)
unnamed: D45.1 (K), R45.2
unnamed: D45.2 (A), U3.6 (QG)
unnamed: D46.1 (K), R46.2
unnamed: D46.2 (A), U3.7 (QH)
unnamed: D47.1 (K), R47.2
unnamed: D47.2 (A), U4.15 (QA)
unnamed: D48.1 (K), R48.2
unnamed: D48.2 (A), U4.1 (QB)
unnamed: D49.1 (K), R49.2
unnamed: D49.2 (A), U4.2 (QC)
unnamed: D50.1 (K), R50.2
unnamed: D50.2 (A), U4.3 (QD)
unnamed: D51.1 (K), R51.2
unnamed: D51.2 (A), U4.4 (QE)
unnamed: D52.1 (K), R52.2
unnamed: D52.2 (A), U4.5 (QF)
unnamed: D53.1 (K), R53.2
unnamed: D53.2 (A), U4.6 (QG)
unnamed: U3.9 (QH'), U4.14 (SER)
SRCLK: U3.11 (SRCLK), U4.11 (SRCLK); also elsewhere on the board
VCC: U3.10 (~SRCLR), U3.16 (VCC), U4.10 (~SRCLR), U4.16 (VCC); also elsewhere on the board

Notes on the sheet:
VU LINE 2

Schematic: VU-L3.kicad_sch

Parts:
D54, D55, D56, D57, D58, D59, D60, D61, D62: VUL3D; LED_GREEN
D63, D64, D65, D66: VUL3D; LED_YELLOW
D67, D68: VUL3D; LED_RED
R54, R55, R56, R57, R58, R59, R60, R61, R62, R63, R64, R65, R66, R67, R68: VUL3R; R_1206_3216Metric_Pad1.30x1.75mm_HandSolder
U5: SR1-L3; SO-16_3.9x9.9mm_P1.27mm
U6: SR2-L3; SO-16_3.9x9.9mm_P1.27mm

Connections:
GND: R54.1, R55.1, R56.1, R57.1, R58.1, R59.1, R60.1, R61.1, R62.1, R63.1, R64.1, R65.1, R66.1, R67.1, R68.1, U5.8 (GND), U5.13 (~OE), U6.8 (GND), U6.13 (~OE); also elsewhere on the board
L3VU-LATCH: U5.12 (RCLK), U6.12 (RCLK); also elsewhere on the board
L3VU-SIG: U5.14 (SER); also elsewhere on the board
unnamed: D54.1 (K), R54.2
unnamed: D54.2 (A), U5.15 (QA)
unnamed: D55.1 (K), R55.2
unnamed: D55.2 (A), U5.1 (QB)
unnamed: D56.1 (K), R56.2
unnamed: D56.2 (A), U5.2 (QC)
unnamed: D57.1 (K), R57.2
unnamed: D57.2 (A), U5.3 (QD)
unnamed: D58.1 (K), R58.2
unnamed: D58.2 (A), U5.4 (QE)
unnamed: D59.1 (K), R59.2
unnamed: D59.2 (A), U5.5 (QF)
unnamed: D60.1 (K), R60.2
unnamed: D60.2 (A), U5.6 (QG)
unnamed: D61.1 (K), R61.2
unnamed: D61.2 (A), U5.7 (QH)
unnamed: D62.1 (K), R62.2
unnamed: D62.2 (A), U6.15 (QA)
unnamed: D63.1 (K), R63.2
unnamed: D63.2 (A), U6.1 (QB)
unnamed: D64.1 (K), R64.2
unnamed: D64.2 (A), U6.2 (QC)
unnamed: D65.1 (K), R65.2
unnamed: D65.2 (A), U6.3 (QD)
unnamed: D66.1 (K), R66.2
unnamed: D66.2 (A), U6.4 (QE)
unnamed: D67.1 (K), R67.2
unnamed: D67.2 (A), U6.5 (QF)
unnamed: D68.1 (K), R68.2
unnamed: D68.2 (A), U6.6 (QG)
unnamed: U5.9 (QH'), U6.14 (SER)
SRCLK: U5.11 (SRCLK), U6.11 (SRCLK); also elsewhere on the board
VCC: U5.10 (~SRCLR), U5.16 (VCC), U6.10 (~SRCLR), U6.16 (VCC); also elsewhere on the board

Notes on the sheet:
VU LINE 3

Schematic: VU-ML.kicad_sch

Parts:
D69, D70, D71, D72, D73, D74, D75, D76, D77: VUMLD; LED_GREEN
D78, D79, D80, D81: VUMLD; LED_YELLOW
D82, D83: VUMLD; LED_RED
R69, R70, R71, R72, R73, R74, R75, R76, R77, R78, R79, R80, R81, R82, R83: VUMLR; R_1206_3216Metric_Pad1.30x1.75mm_HandSolder
U7: SR1-ML; SO-16_3.9x9.9mm_P1.27mm
U8: SR2-ML; SO-16_3.9x9.9mm_P1.27mm

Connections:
GND: R69.1, R70.1, R71.1, R72.1, R73.1, R74.1, R75.1, R76.1, R77.1, R78.1, R79.1, R80.1, R81.1, R82.1, R83.1, U7.8 (GND), U7.13 (~OE), U8.8 (GND), U8.13 (~OE); also elsewhere on the board
MLVU-LATCH: U7.12 (RCLK), U8.12 (RCLK); also elsewhere on the board
MLVU-SIG: U7.14 (SER); also elsewhere on the board
unnamed: D69.1 (K), R69.2
unnamed: D69.2 (A), U7.15 (QA)
unnamed: D70.1 (K), R70.2
unnamed: D70.2 (A), U7.1 (QB)
unnamed: D71.1 (K), R71.2
unnamed: D71.2 (A), U7.2 (QC)
unnamed: D72.1 (K), R72.2
unnamed: D72.2 (A), U7.3 (QD)
unnamed: D73.1 (K), R73.2
unnamed: D73.2 (A), U7.4 (QE)
unnamed: D74.1 (K), R74.2
unnamed: D74.2 (A), U7.5 (QF)
unnamed: D75.1 (K), R75.2
unnamed: D75.2 (A), U7.6 (QG)
unnamed: D76.1 (K), R76.2
unnamed: D76.2 (A), U7.7 (QH)
unnamed: D77.1 (K), R77.2
unnamed: D77.2 (A), U8.15 (QA)
unnamed: D78.1 (K), R78.2
unnamed: D78.2 (A), U8.1 (QB)
unnamed: D79.1 (K), R79.2
unnamed: D79.2 (A), U8.2 (QC)
unnamed: D80.1 (K), R80.2
unnamed: D80.2 (A), U8.3 (QD)
unnamed: D81.1 (K), R81.2
unnamed: D81.2 (A), U8.4 (QE)
unnamed: D82.1 (K), R82.2
unnamed: D82.2 (A), U8.5 (QF)
unnamed: D83.1 (K), R83.2
unnamed: D83.2 (A), U8.6 (QG)
unnamed: U7.9 (QH'), U8.14 (SER)
SRCLK: U7.11 (SRCLK), U8.11 (SRCLK); also elsewhere on the board
VCC: U7.10 (~SRCLR), U7.16 (VCC), U8.10 (~SRCLR), U8.16 (VCC); also elsewhere on the board

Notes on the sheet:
VU MASTER LEFT

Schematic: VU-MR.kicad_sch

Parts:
D84, D85, D86, D87, D88, D89, D90, D91, D92: VUMRD; LED_GREEN
D93, D94, D95, D96: VUMRD; LED_YELLOW
D97, D98: VUMRD; LED_RED
R84, R85, R86, R87, R88, R89, R90, R91, R92, R93, R94, R95, R96, R97, R98: VUMRR; R_1206_3216Metric_Pad1.30x1.75mm_HandSolder
U9: SR1-MR; SO-16_3.9x9.9mm_P1.27mm
U10: SR2-MR; SO-16_3.9x9.9mm_P1.27mm

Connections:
GND: R84.1, R85.1, R86.1, R87.1, R88.1, R89.1, R90.1, R91.1, R92.1, R93.1, R94.1, R95.1, R96.1, R97.1, R98.1, U9.8 (GND), U9.13 (~OE), U10.8 (GND), U10.13 (~OE); also elsewhere on the board
MRVU-LATCH: U9.12 (RCLK), U10.12 (RCLK); also elsewhere on the board
MRVU-SIG: U9.14 (SER); also elsewhere on the board
unnamed: D84.1 (K), R84.2
unnamed: D84.2 (A), U9.15 (QA)
unnamed: D85.1 (K), R85.2
unnamed: D85.2 (A), U9.1 (QB)
unnamed: D86.1 (K), R86.2
unnamed: D86.2 (A), U9.2 (QC)
unnamed: D87.1 (K), R87.2
unnamed: D87.2 (A), U9.3 (QD)
unnamed: D88.1 (K), R88.2
unnamed: D88.2 (A), U9.4 (QE)
unnamed: D89.1 (K), R89.2
unnamed: D89.2 (A), U9.5 (QF)
unnamed: D90.1 (K), R90.2
unnamed: D90.2 (A), U9.6 (QG)
unnamed: D91.1 (K), R91.2
unnamed: D91.2 (A), U9.7 (QH)
unnamed: D92.1 (K), R92.2
unnamed: D92.2 (A), U10.15 (QA)
unnamed: D93.1 (K), R93.2
unnamed: D93.2 (A), U10.1 (QB)
unnamed: D94.1 (K), R94.2
unnamed: D94.2 (A), U10.2 (QC)
unnamed: D95.1 (K), R95.2
unnamed: D95.2 (A), U10.3 (QD)
unnamed: D96.1 (K), R96.2
unnamed: D96.2 (A), U10.4 (QE)
unnamed: D97.1 (K), R97.2
unnamed: D97.2 (A), U10.5 (QF)
unnamed: D98.1 (K), R98.2
unnamed: D98.2 (A), U10.6 (QG)
unnamed: U9.9 (QH'), U10.14 (SER)
SRCLK: U9.11 (SRCLK), U10.11 (SRCLK); also elsewhere on the board
VCC: U9.10 (~SRCLR), U9.16 (VCC), U10.10 (~SRCLR), U10.16 (VCC); also elsewhere on the board

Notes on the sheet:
VU MASTER RIGHT

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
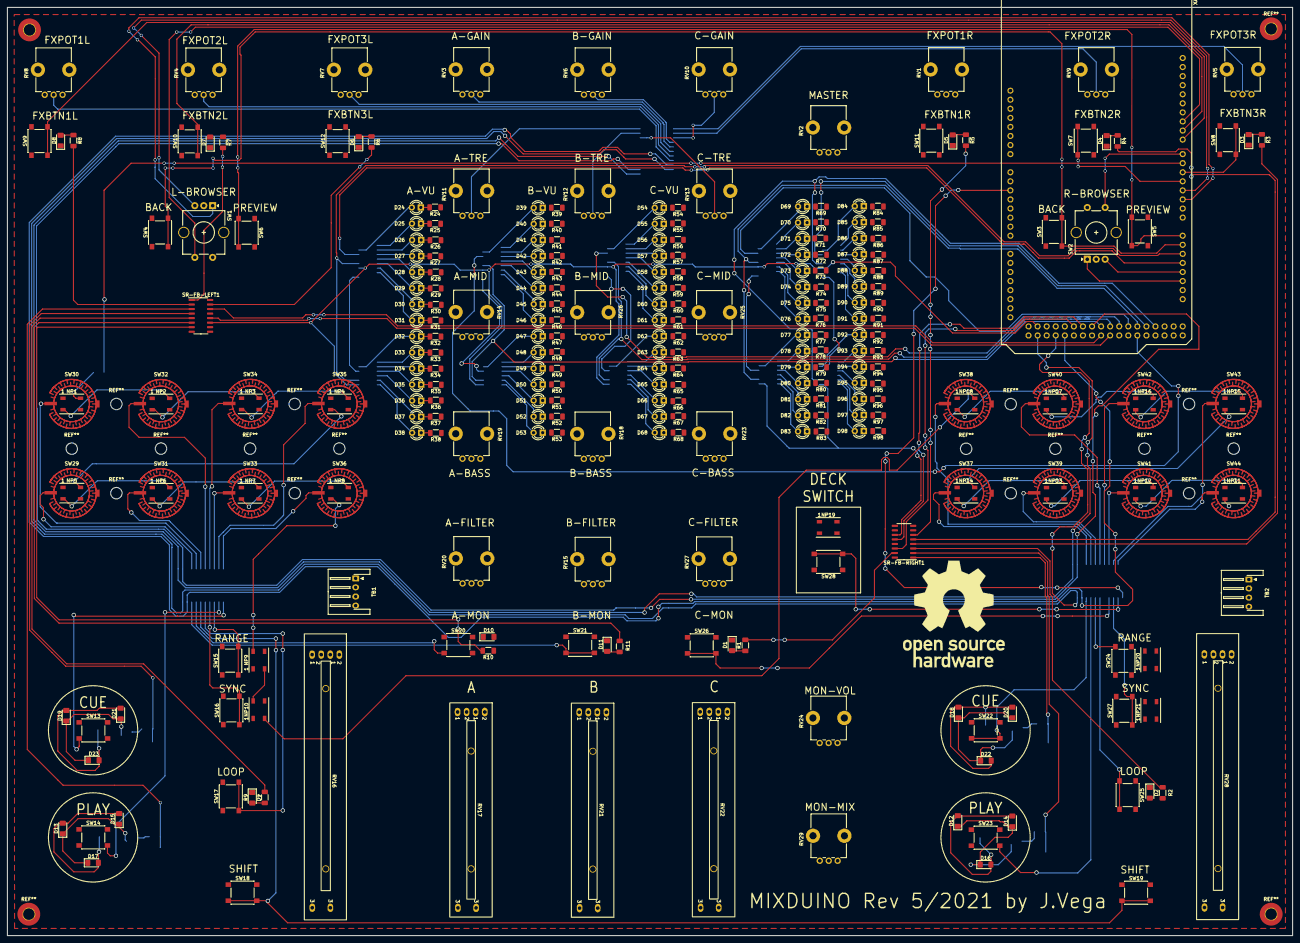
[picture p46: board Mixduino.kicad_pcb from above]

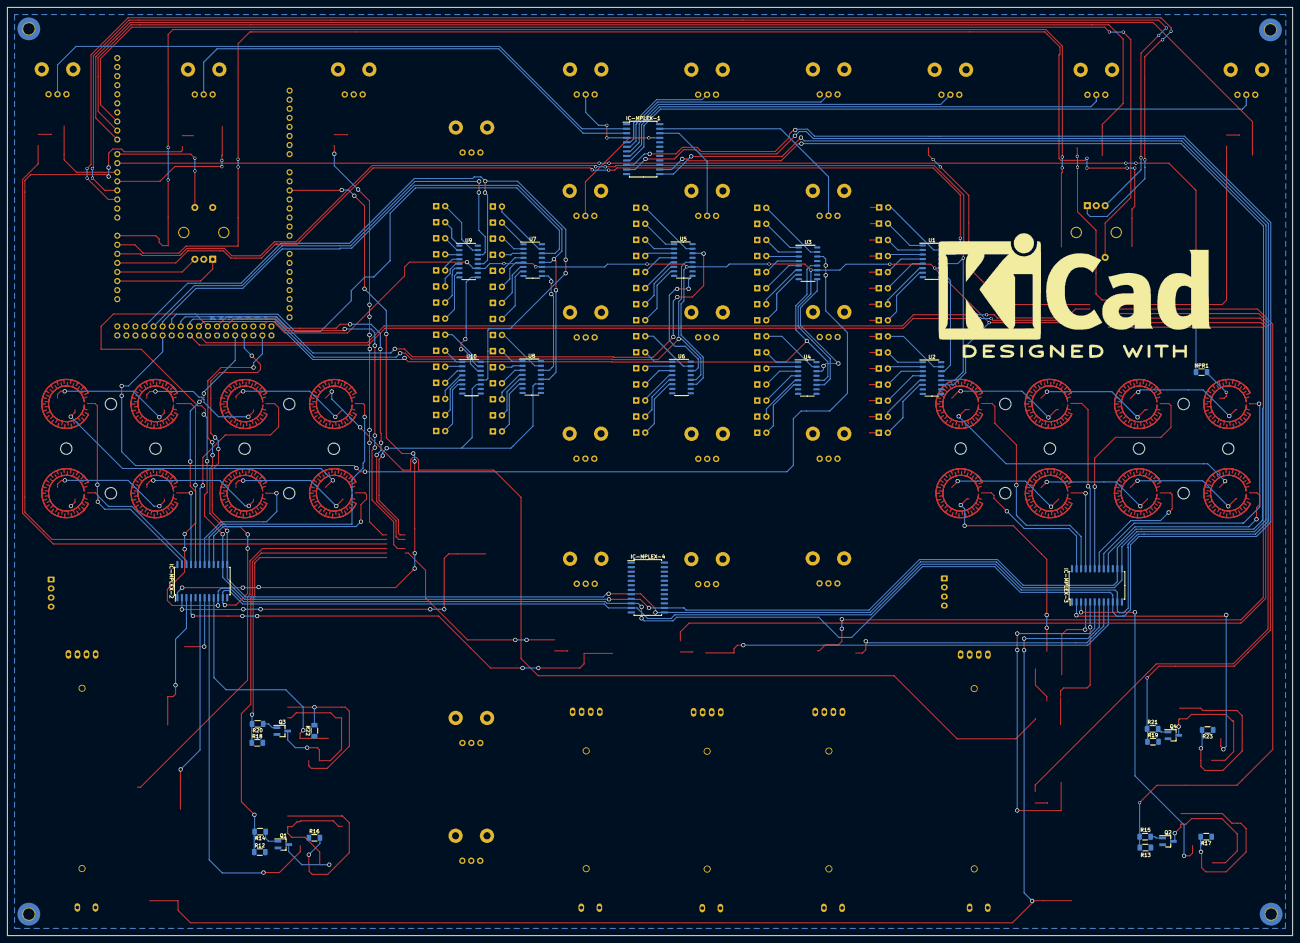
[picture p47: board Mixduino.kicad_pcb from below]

Board: 2 copper layers, 360.0 x 260.0 mm, 314 parts (31 on the bottom side), 316 nets.

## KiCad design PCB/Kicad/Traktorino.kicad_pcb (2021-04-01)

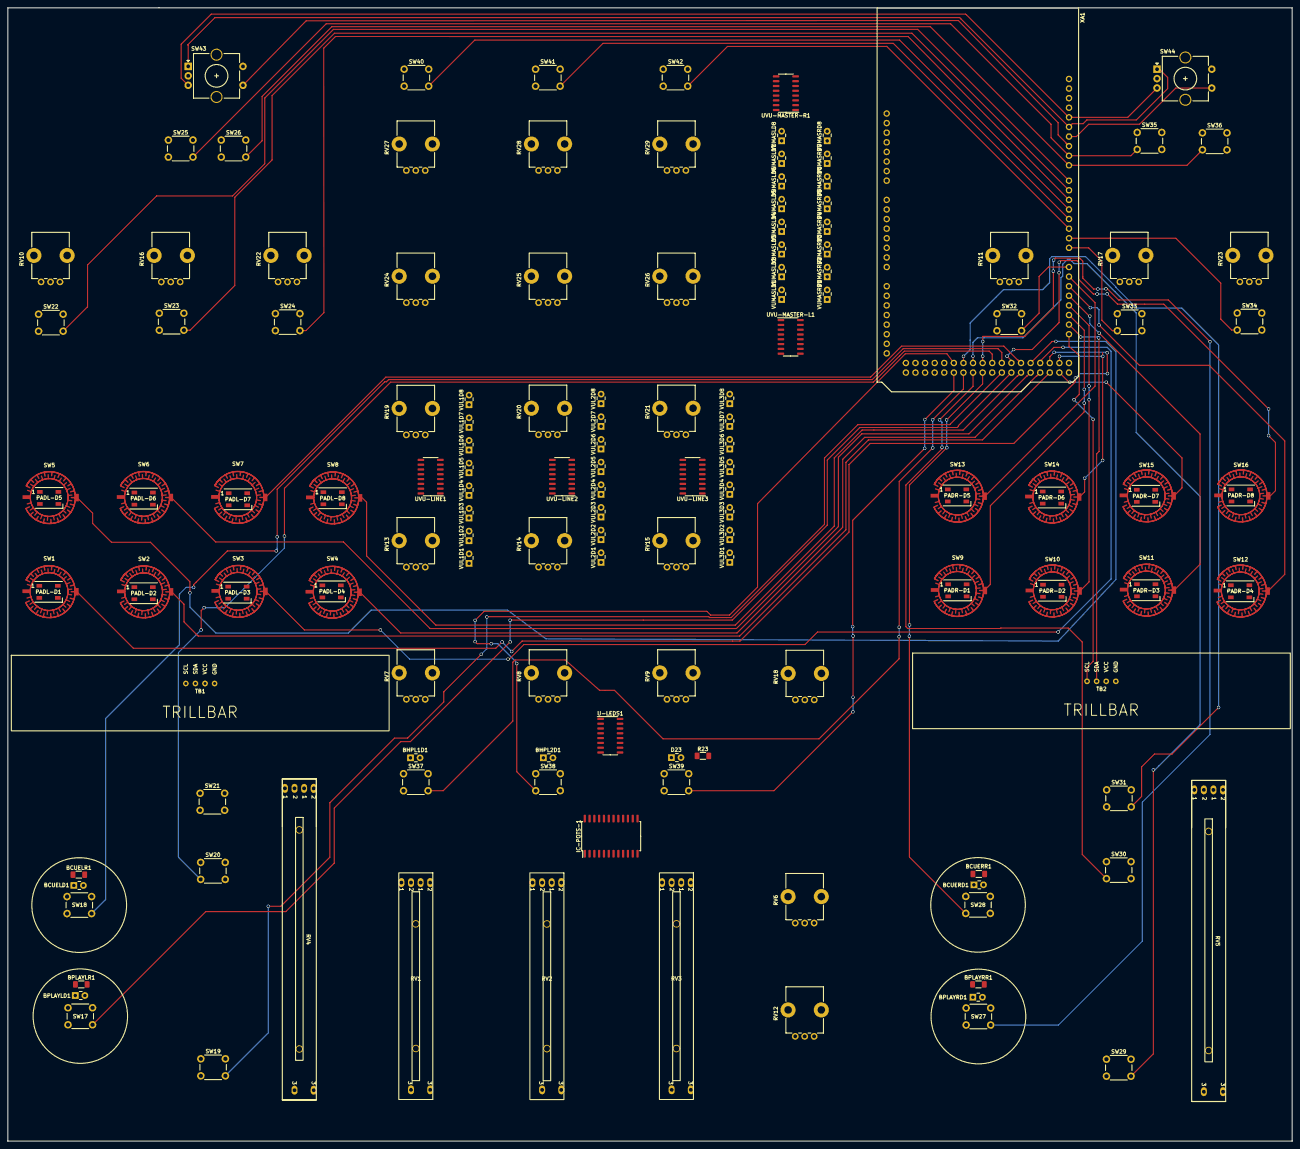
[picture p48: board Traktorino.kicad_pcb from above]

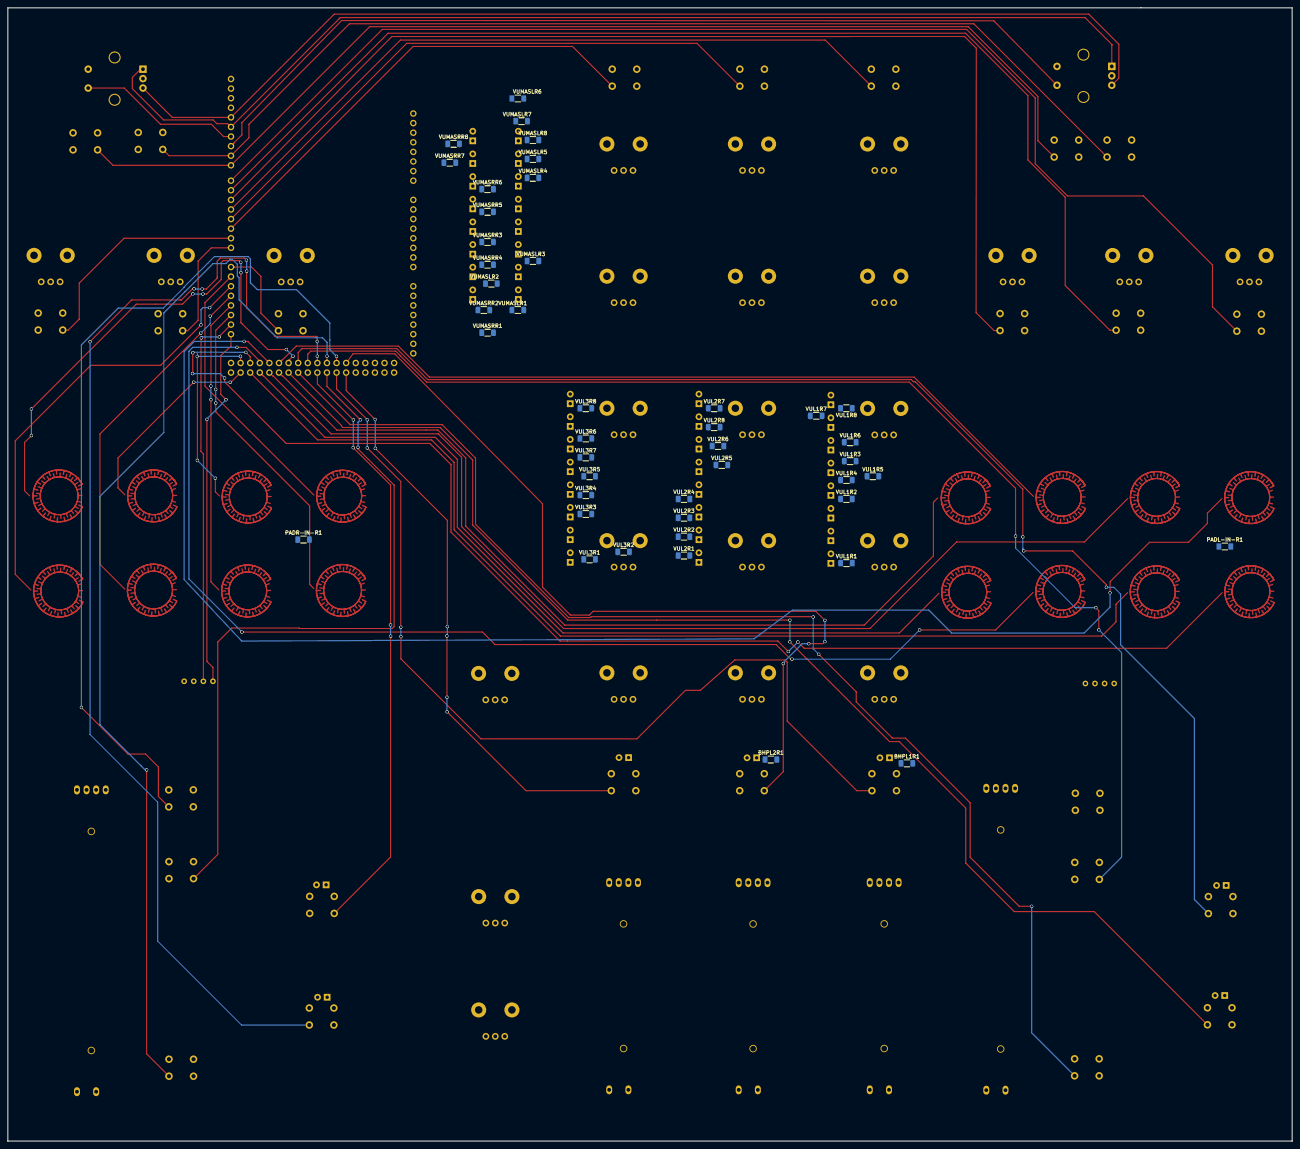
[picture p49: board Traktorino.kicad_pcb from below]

Board: 2 copper layers, 340.0 x 300.0 mm, 195 parts (44 on the bottom side), 201 nets.

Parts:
BCUELD1: LED_ALT; LED_Rectangular_W3.0mm_H2.0mm
BCUELR1: R_Small; R_1206_3216Metric_Pad1.30x1.75mm_HandSolder
BCUERD1: LED_ALT; LED_Rectangular_W3.0mm_H2.0mm
BCUERR1: R_Small; R_1206_3216Metric_Pad1.30x1.75mm_HandSolder
BHPL1D1, BHPL2D1: LED_ALT; LED_Rectangular_W3.0mm_H2.0mm
BHPL1R1, BHPL2R1: R_Small; R_1206_3216Metric_Pad1.30x1.75mm_HandSolder
BPLAYLD1: LED_ALT; LED_Rectangular_W3.0mm_H2.0mm
BPLAYLR1: R_Small; R_1206_3216Metric_Pad1.30x1.75mm_HandSolder
BPLAYRD1: LED_ALT; LED_Rectangular_W3.0mm_H2.0mm
BPLAYRR1: R_Small; R_1206_3216Metric_Pad1.30x1.75mm_HandSolder
D23: LED_ALT; LED_Rectangular_W3.0mm_H2.0mm
IC-POTS-1: 74HC4067D,653; SOIC-24W_7.5x15.4mm_P1.27mm
PADL-D1, PADL-D2, PADL-D3, PADL-D4, PADL-D5, PADL-D6, PADL-D7, PADL-D8: WS2812B; LED_WS2812B_PLCC4_5.0x5.0mm_P3.2mm
PADL-IN-R1: R_Small; R_1206_3216Metric_Pad1.30x1.75mm_HandSolder
PADR-D1, PADR-D2, PADR-D3, PADR-D4, PADR-D5, PADR-D6, PADR-D7, PADR-D8: WS2812B; LED_WS2812B_PLCC4_5.0x5.0mm_P3.2mm
PADR-IN-R1: R_Small; R_1206_3216Metric_Pad1.30x1.75mm_HandSolder
R23: R_Small; R_1206_3216Metric_Pad1.30x1.75mm_HandSolder
RV1: FADERL1; fader-L60
RV2: FADERL2; fader-L60
RV3: FADERL3; fader-L60
RV4: PITCH-L; fader-L75
RV5: PITH-R; fader-L75
RV6: PMIX-HP; Potentiometer_Bourns_PTV09A-1_Single_Vertical
RV7: FILTERL1; Potentiometer_Bourns_PTV09A-1_Single_Vertical
RV8: FILTERL2; Potentiometer_Bourns_PTV09A-1_Single_Vertical
RV9: FILTERL3; Potentiometer_Bourns_PTV09A-1_Single_Vertical
RV10: PFX1L; Potentiometer_Bourns_PTV09A-1_Single_Vertical
RV11: PFX1R; Potentiometer_Bourns_PTV09A-1_Single_Vertical
RV12: PVOL-HP; Potentiometer_Bourns_PTV09A-1_Single_Vertical
RV13: BASL1; Potentiometer_Bourns_PTV09A-1_Single_Vertical
RV14: BASL2; Potentiometer_Bourns_PTV09A-1_Single_Vertical
RV15: BASL3; Potentiometer_Bourns_PTV09A-1_Single_Vertical
RV16: PFX2L; Potentiometer_Bourns_PTV09A-1_Single_Vertical
RV17: PFX2R; Potentiometer_Bourns_PTV09A-1_Single_Vertical
RV18: PMASTER; Potentiometer_Bourns_PTV09A-1_Single_Vertical
RV19: MIDL1; Potentiometer_Bourns_PTV09A-1_Single_Vertical
RV20: MIDL2; Potentiometer_Bourns_PTV09A-1_Single_Vertical
RV21: MIDL3; Potentiometer_Bourns_PTV09A-1_Single_Vertical
RV22: PFX3L; Potentiometer_Bourns_PTV09A-1_Single_Vertical
RV23: PFX3R; Potentiometer_Bourns_PTV09A-1_Single_Vertical
RV24: TREL1; Potentiometer_Bourns_PTV09A-1_Single_Vertical
RV25: TREL2; Potentiometer_Bourns_PTV09A-1_Single_Vertical
RV26: TREL3; Potentiometer_Bourns_PTV09A-1_Single_Vertical
RV27: GAINL1; Potentiometer_Bourns_PTV09A-1_Single_Vertical
RV28: GAINL2; Potentiometer_Bourns_PTV09A-1_Single_Vertical
RV29: GAINL3; Potentiometer_Bourns_PTV09A-1_Single_Vertical
SW1: SWPADL1; sw-pad
SW2: SWPADL2; sw-pad
SW3: SWPADL3; sw-pad
SW4: SWPADL4; sw-pad
SW5: SWPADL5; sw-pad
SW6: SWPADL6; sw-pad
SW7: SWPADL7; sw-pad
SW8: SWPADL8; sw-pad
SW9: SWPADR1; sw-pad
SW10: SWPADR2; sw-pad
SW11: SWPADR3; sw-pad
SW12: SWPADR4; sw-pad
SW13: SWPADR5; sw-pad
SW14: SWPADR6; sw-pad
SW15: SWPADR7; sw-pad
SW16: SWPADR8; sw-pad
SW17: SWPLAYL; SW_PUSH_6mm_H5mm
SW18: SWCUEL; SW_PUSH_6mm_H5mm
SW19: SWSHIFTL; SW_PUSH_6mm_H5mm
SW20: SWSYNCL; SW_PUSH_6mm_H5mm
SW21: SWRANGEL; SW_PUSH_6mm_H5mm
SW22: SWFX1L; SW_PUSH_6mm_H5mm
SW23: SWFX2L; SW_PUSH_6mm_H5mm
SW24: SWFX3L; SW_PUSH_6mm_H5mm
SW25: SWBR-PREVL; SW_PUSH_6mm_H5mm
SW26: SWBR-BACKL; SW_PUSH_6mm_H5mm
SW27: SWPLAYR; SW_PUSH_6mm_H5mm
SW28: SWCUER; SW_PUSH_6mm_H5mm
SW29: SWSHIFTR; SW_PUSH_6mm_H5mm
SW30: SWSYNCR; SW_PUSH_6mm_H5mm
SW31: SWRANGER; SW_PUSH_6mm_H5mm
SW32: SWFX1R; SW_PUSH_6mm_H5mm
SW33: SWFX2R; SW_PUSH_6mm_H5mm
SW34: SWFX3R; SW_PUSH_6mm_H5mm
SW35: SWBR-PREVR; SW_PUSH_6mm_H5mm
SW36: SWBR-BACKR; SW_PUSH_6mm_H5mm
SW37: SWPCUEL1; SW_PUSH_6mm_H5mm
SW38: SWPCUEL2; SW_PUSH_6mm_H5mm
SW39: SWPCUEL3; SW_PUSH_6mm_H5mm
SW40: SWSEL1; SW_PUSH_6mm_H5mm
SW41: SWSEL2; SW_PUSH_6mm_H5mm
SW42: SWSEL3; SW_PUSH_6mm_H5mm
SW43: BROWSER-L; RotaryEncoder_Alps_EC11E-Switch_Vertical_H20mm_CircularMoun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
SW44: BROWSER-R; RotaryEncoder_Alps_EC11E-Switch_Vertical_H20mm_CircularMoun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
TB1: trillbar-left; trillbar
TB2: trillbar-right; trillbar
U-LEDS1: 74HC595; SO-16_3.9x9.9mm_P1.27mm
UVU-LINE1, UVU-LINE2, UVU-LINE3: 74HC595; SO-16_3.9x9.9mm_P1.27mm
UVU-MASTER-L1: 74HC595; SO-16_3.9x9.9mm_P1.27mm
UVU-MASTER-R1: 74HC595; SO-16_3.9x9.9mm_P1.27mm
VUL1D1, VUL1D2, VUL1D3, VUL1D4, VUL1D5, VUL1D6, VUL1D7, VUL1D8, VUL2D1, VUL2D2, VUL2D3, VUL2D4, VUL2D5, VUL2D6, VUL2D7, VUL2D8, VUL3D1, VUL3D2, VUL3D3, VUL3D4, VUL3D5, VUL3D6, VUL3D7, VUL3D8: LED_Filled; LED_Rectangular_W3.0mm_H2.0mm
VUL1R1, VUL1R2, VUL1R3, VUL1R4, VUL1R5, VUL1R6, VUL1R7, VUL1R8, VUL2R1, VUL2R2, VUL2R3, VUL2R4, VUL2R5, VUL2R6, VUL2R7, VUL2R8, VUL3R1, VUL3R2, VUL3R3, VUL3R4, VUL3R5, VUL3R6, VUL3R7, VUL3R8: R_Small; R_1206_3216Metric_Pad1.30x1.75mm_HandSolder
VUMASLD1, VUMASLD2, VUMASLD3, VUMASLD4, VUMASLD5, VUMASLD6, VUMASLD7, VUMASLD8: LED_Filled; LED_Rectangular_W3.0mm_H2.0mm
VUMASLR1, VUMASLR2, VUMASLR3, VUMASLR4, VUMASLR5, VUMASLR6, VUMASLR7, VUMASLR8: R_Small; R_1206_3216Metric_Pad1.30x1.75mm_HandSolder
VUMASRD1, VUMASRD2, VUMASRD3, VUMASRD4, VUMASRD5, VUMASRD6, VUMASRD7, VUMASRD8: LED_Filled; LED_Rectangular_W3.0mm_H2.0mm
VUMASRR1, VUMASRR2, VUMASRR3, VUMASRR4, VUMASRR5, VUMASRR6, VUMASRR7, VUMASRR8: R_Small; R_1206_3216Metric_Pad1.30x1.75mm_HandSolder
XA1: Arduino_Mega2560_Shield

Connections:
BAS-L1: IC-POTS-1.21 (Y10), RV13.2
BAS-L2: IC-POTS-1.20 (Y11), RV14.2
BAS-L3: IC-POTS-1.19 (Y12), RV15.2
BROWSER_A: SW43.A, SW44.A, XA1.D12
BROWSER_B: SW43.B, SW44.B, XA1.D13
FADER-L1: IC-POTS-1.8 (Y1), RV1.2
FADER-L2: IC-POTS-1.7 (Y2), RV2.2
FADER-L3: IC-POTS-1.6 (Y3), RV3.2
FILTER-L1: IC-POTS-1.2 (Y7), RV7.2
FILTER-L2: IC-POTS-1.23 (Y8), RV8.2
FILTER-L3: IC-POTS-1.22 (Y9), RV9.2
GAIN-L1: RV27.2, XA1.A1
GAIN-L2: RV28.2, XA1.A2
GAIN-L3: RV29.2, XA1.A3
GND: BCUELR1.2, BCUERR1.2, BHPL1R1.2, BHPL2R1.2, BPLAYLR1.2, BPLAYRR1.2, IC-POTS-1.12 (GND), IC-POTS-1.15 (~E), PADL-D1.3 (VSS), PADL-D2.3 (VSS), PADL-D3.3 (VSS), PADL-D4.3 (VSS), PADL-D5.3 (VSS), PADL-D6.3 (VSS), PADL-D7.3 (VSS), PADL-D8.3 (VSS), PADR-D1.3 (VSS), PADR-D2.3 (VSS), PADR-D3.3 (VSS), PADR-D4.3 (VSS), PADR-D5.3 (VSS), PADR-D6.3 (VSS), PADR-D7.3 (VSS), PADR-D8.3 (VSS), R23.2, RV1.3, RV2.3, RV3.3, RV4.3, RV5.3, RV6.3, RV7.3, RV8.3, RV9.3, RV10.3, RV11.3, RV12.3, RV13.3, RV14.3, RV15.3, RV16.3, RV17.3, RV18.3, RV19.3, RV20.3, RV21.3, RV22.3, RV23.3, RV24.3, RV25.3, RV26.3, RV27.3, RV28.3, RV29.3, SW1.1, SW2.1, SW3.1, SW4.1, SW5.1, SW6.1, SW7.1, SW8.1, SW9.1, SW10.1, SW11.1, SW12.1, SW13.1, SW14.1, SW15.1, SW16.1, SW17.1, SW18.1, SW19.1, SW20.1, SW21.1, SW22.1, SW23.1, SW24.1, SW25.1, SW26.1, SW27.1, SW28.1, SW29.1, SW30.1, SW31.1, SW32.1, SW33.1, SW34.1, SW35.1, SW36.1, SW37.1, SW38.1, SW39.1, SW40.1, SW41.1, SW42.1, SW43.C, SW43.S2, SW44.C, SW44.S2, TB1.4 (GND), TB2.4 (GND), U-LEDS1.8 (GND), U-LEDS1.13 (~OE), UVU-LINE1.8 (GND), UVU-LINE1.13 (~OE), UVU-LINE2.8 (GND), UVU-LINE2.13 (~OE), UVU-LINE3.8 (GND), UVU-LINE3.13 (~OE), UVU-MASTER-L1.8 (GND), UVU-MASTER-L1.13 (~OE), UVU-MASTER-R1.8 (GND), UVU-MASTER-R1.13 (~OE), VUL1R1.2, VUL1R2.2, VUL1R3.2, VUL1R4.2, VUL1R5.2, VUL1R6.2, VUL1R7.2, VUL1R8.2, VUL2R1.2, VUL2R2.2, VUL2R3.2, VUL2R4.2, VUL2R5.2, VUL2R6.2, VUL2R7.2, VUL2R8.2, VUL3R1.2, VUL3R2.2, VUL3R3.2, VUL3R4.2, VUL3R5.2, VUL3R6.2, VUL3R7.2, VUL3R8.2, VUMASLR1.2, VUMASLR2.2, VUMASLR3.2, VUMASLR4.2, VUMASLR5.2, VUMASLR6.2, VUMASLR7.2, VUMASLR8.2, VUMASRR1.2, VUMASRR2.2, VUMASRR3.2, VUMASRR4.2, VUMASRR5.2, VUMASRR6.2, VUMASRR7.2, VUMASRR8.2, XA1.GND1 (GND), XA1.GND2 (GND), XA1.GND3 (GND), XA1.GND5 (GND), XA1.GND6 (GND)
LEDCUEL: BCUELD1.2 (A), U-LEDS1.4 (QE)
LEDCUER: BCUERD1.2 (A), U-LEDS1.2 (QC)
LEDHPL1: BHPL1D1.2 (A), U-LEDS1.7 (QH)
LEDHPL2: BHPL2D1.2 (A), U-LEDS1.6 (QG)
LEDHPL3: D23.2 (A), U-LEDS1.5 (QF)
LEDPLAYL: BPLAYLD1.2 (A), U-LEDS1.3 (QD)
LEDPLAYR: BPLAYRD1.2 (A), U-LEDS1.1 (QB)
MID-L1: IC-POTS-1.18 (Y13), RV19.2
MID-L2: IC-POTS-1.17 (Y14), RV20.2
MID-L3: IC-POTS-1.16 (Y15), RV21.2
MPLEX-A0: IC-POTS-1.1 (Z), XA1.A0
MPLEX-S0: IC-POTS-1.10 (S0), XA1.D48
MPLEX-S1: IC-POTS-1.11 (S1), XA1.D49
MPLEX-S2: IC-POTS-1.14 (S2), XA1.D50
MPLEX-S3: IC-POTS-1.13 (S3), XA1.D51
unnamed: BCUELD1.1 (K), BCUELR1.1
unnamed: BCUERD1.1 (K), BCUERR1.1
unnamed: BHPL1D1.1 (K), BHPL1R1.1
unnamed: BHPL2D1.1 (K), BHPL2R1.1
unnamed: BPLAYLD1.1 (K), BPLAYLR1.1
unnamed: BPLAYRD1.1 (K), BPLAYRR1.1
unnamed: D23.1 (K), R23.1
unnamed: PADL-D1.2 (DOUT), PADL-D2.4 (DIN)
unnamed: PADL-D1.4 (DIN), PADL-IN-R1.2
unnamed: PADL-D2.2 (DOUT), PADL-D3.4 (DIN)
unnamed: PADL-D3.2 (DOUT), PADL-D4.4 (DIN)
unnamed: PADL-D4.2 (DOUT), PADL-D5.4 (DIN)
unnamed: PADL-D5.2 (DOUT), PADL-D6.4 (DIN)
unnamed: PADL-D6.2 (DOUT), PADL-D7.4 (DIN)
unnamed: PADL-D7.2 (DOUT), PADL-D8.4 (DIN)
unnamed: PADR-D1.2 (DOUT), PADR-D2.4 (DIN)
unnamed: PADR-D1.4 (DIN), PADR-IN-R1.2
unnamed: PADR-D2.2 (DOUT), PADR-D3.4 (DIN)
unnamed: PADR-D3.2 (DOUT), PADR-D4.4 (DIN)
unnamed: PADR-D4.2 (DOUT), PADR-D5.4 (DIN)
unnamed: PADR-D5.2 (DOUT), PADR-D6.4 (DIN)
unnamed: PADR-D6.2 (DOUT), PADR-D7.4 (DIN)
unnamed: PADR-D7.2 (DOUT), PADR-D8.4 (DIN)
unnamed: U-LEDS1.14 (SER), UVU-MASTER-R1.9 (QH')
unnamed: UVU-LINE1.9 (QH'), UVU-LINE2.14 (SER)
unnamed: UVU-LINE2.9 (QH'), UVU-LINE3.14 (SER)
unnamed: UVU-LINE3.9 (QH'), UVU-MASTER-L1.14 (SER)
unnamed: UVU-MASTER-L1.9 (QH'), UVU-MASTER-R1.14 (SER)
unnamed: VUL1D1.1 (K), VUL1R1.1
unnamed: VUL1D2.1 (K), VUL1R2.1
unnamed: VUL1D3.1 (K), VUL1R3.1
unnamed: VUL1D4.1 (K), VUL1R4.1
unnamed: VUL1D5.1 (K), VUL1R5.1
unnamed: VUL1D6.1 (K), VUL1R6.1
unnamed: VUL1D7.1 (K), VUL1R7.1
unnamed: VUL1D8.1 (K), VUL1R8.1
unnamed: VUL2D1.1 (K), VUL2R1.1
unnamed: VUL2D2.1 (K), VUL2R2.1
unnamed: VUL2D3.1 (K), VUL2R3.1
unnamed: VUL2D4.1 (K), VUL2R4.1
unnamed: VUL2D5.1 (K), VUL2R5.1
unnamed: VUL2D6.1 (K), VUL2R6.1
unnamed: VUL2D7.1 (K), VUL2R7.1
unnamed: VUL2D8.1 (K), VUL2R8.1
unnamed: VUL3D1.1 (K), VUL3R1.1
unnamed: VUL3D2.1 (K), VUL3R2.1
unnamed: VUL3D3.1 (K), VUL3R3.1
unnamed: VUL3D4.1 (K), VUL3R4.1
unnamed: VUL3D5.1 (K), VUL3R5.1
unnamed: VUL3D6.1 (K), VUL3R6.1
unnamed: VUL3D7.1 (K), VUL3R7.1
unnamed: VUL3D8.1 (K), VUL3R8.1
unnamed: VUMASLD1.1 (K), VUMASLR1.1
unnamed: VUMASLD2.1 (K), VUMASLR2.1
unnamed: VUMASLD3.1 (K), VUMASLR3.1
unnamed: VUMASLD4.1 (K), VUMASLR4.1
unnamed: VUMASLD5.1 (K), VUMASLR5.1
unnamed: VUMASLD6.1 (K), VUMASLR6.1
unnamed: VUMASLD7.1 (K), VUMASLR7.1
unnamed: VUMASLD8.1 (K), VUMASLR8.1
unnamed: VUMASRD1.1 (K), VUMASRR1.1
unnamed: VUMASRD2.1 (K), VUMASRR2.1
unnamed: VUMASRD3.1 (K), VUMASRR3.1
unnamed: VUMASRD4.1 (K), VUMASRR4.1
unnamed: VUMASRD5.1 (K), VUMASRR5.1
unnamed: VUMASRD6.1 (K), VUMASRR6.1
unnamed: VUMASRD7.1 (K), VUMASRR7.1
unnamed: VUMASRD8.1 (K), VUMASRR8.1
PFX-1L: RV10.2, XA1.A7
PFX-1R: RV11.2, XA1.A10
PFX-2L: RV16.2, XA1.A8
PFX-2R: RV17.2, XA1.A11
PFX-3L: RV22.2, XA1.A9
PFX-3R: RV23.2, XA1.A12
PITCH-L: IC-POTS-1.9 (Y0), RV4.2
PITCH-R: IC-POTS-1.3 (Y6), RV5.2
PMASTER: RV18.2, XA1.A13
PMIX-HP: IC-POTS-1.5 (Y4), RV6.2
PVOL-HP: IC-POTS-1.4 (Y5), RV12.2
SCL: TB1.1 (SCL), TB2.1 (SCL), XA1.D21 (D21_SCL)
SDA: TB1.2 (SDA), TB2.2 (SDA), XA1.D20 (D20_SDA)
SF-CLOCK: U-LEDS1.11 (SRCLK), UVU-LINE1.11 (SRCLK), UVU-LINE2.11 (SRCLK), UVU-LINE3.11 (SRCLK), UVU-MASTER-L1.11 (SRCLK), UVU-MASTER-R1.11 (SRCLK), XA1.D52
SF-DATA: UVU-LINE1.14 (SER), XA1.A15
SF-LATCH: U-LEDS1.12 (RCLK), UVU-LINE1.12 (RCLK), UVU-LINE2.12 (RCLK), UVU-LINE3.12 (RCLK), UVU-MASTER-L1.12 (RCLK), UVU-MASTER-R1.12 (RCLK), XA1.D53 (D53_SS)
SIG_PAD_LED_L: PADL-IN-R1.1, PADR-IN-R1.1, XA1.D46
SWBR-BACK: SW26.2, SW36.2, XA1.D8
SWBR-PREVIEW: SW25.2, SW35.2, XA1.D9
SWCUE-L: SW18.2, XA1.D34
SWCUE-R: SW28.2, XA1.D39
SWFX1-L: SW22.2, XA1.D7
SWFX1-R: SW32.2, XA1.D14 (D14_TX3)
SWFX2-L: SW23.2, XA1.D6
SWFX2-R: SW33.2, XA1.D0 (D0_RX0)
SWFX3-L: SW24.2, XA1.D5
SWFX3-R: SW34.2, XA1.D1 (D1_TX0)
SWPAD-L1: SW1.2, XA1.D24
SWPAD-L2: SW2.2, XA1.D25
SWPAD-L3: SW3.2, XA1.D26
SWPAD-L4: SW4.2, XA1.D27
SWPAD-L5: SW5.2, XA1.D28
SWPAD-L6: SW6.2, XA1.D29
SWPAD-L7: SW7.2, XA1.D30
SWPAD-L8: SW8.2, XA1.D31
SWPAD-R1: SW9.2, XA1.D19 (D19_RX1)
SWPAD-R2: SW10.2, XA1.D18 (D18_TX1)
SWPAD-R3: SW11.2, XA1.D17 (D17_RX2)
SWPAD-R4: SW12.2, XA1.D16 (D16_TX2)
SWPAD-R5: SW13.2, XA1.D15 (D15_RX3)
SWPAD-R6: SW14.2, XA1.D22
SWPAD-R7: SW15.2, XA1.D23
SWPAD-R8: SW16.2, XA1.D32
SWPLAY-L: SW17.2, XA1.D33
SWPLAY-R: SW27.2, XA1.D38
SWPRECUE-L1: SW37.2, XA1.D43
SWPRECUE-L2: SW38.2, XA1.D44
SWPRECUE-L3: SW39.2, XA1.D45
SWRANGE-L: SW21.2, XA1.D37
SWRANGE-R: SW31.2, XA1.D42
SWSEL-L1: SW40.2, XA1.D4
SWSEL-L2: SW41.2, XA1.D3 (D3_INT1)
SWSEL-L3: SW42.2, XA1.D2 (D2_INT0)
SWSHIFT-L: SW19.2, XA1.D35
SWSHIFT-R: SW29.2, XA1.D40
SWSYNC-L: SW20.2, XA1.D36
SWSYNC-R: SW30.2, XA1.D41
SW_BROWSER_L: SW43.S1, XA1.D10
SW_BROWSER_R: SW44.S1, XA1.D11
TRE-L1: RV24.2, XA1.A4
TRE-L2: RV25.2, XA1.A5
TRE-L3: RV26.2, XA1.A6
VCC: IC-POTS-1.24 (VCC), PADL-D1.1 (VDD), PADL-D2.1 (VDD), PADL-D3.1 (VDD), PADL-D4.1 (VDD), PADL-D5.1 (VDD), PADL-D6.1 (VDD), PADL-D7.1 (VDD), PADL-D8.1 (VDD), PADR-D1.1 (VDD), PADR-D2.1 (VDD), PADR-D3.1 (VDD), PADR-D4.1 (VDD), PADR-D5.1 (VDD), PADR-D6.1 (VDD), PADR-D7.1 (VDD), PADR-D8.1 (VDD), RV1.1, RV2.1, RV3.1, RV4.1, RV5.1, RV6.1, RV7.1, RV8.1, RV9.1, RV10.1, RV11.1, RV12.1, RV13.1, RV14.1, RV15.1, RV16.1, RV17.1, RV18.1, RV19.1, RV20.1, RV21.1, RV22.1, RV23.1, RV24.1, RV25.1, RV26.1, RV27.1, RV28.1, RV29.1, TB1.3 (VCC), TB2.3 (VCC), U-LEDS1.10 (~SRCLR), U-LEDS1.16 (VCC), UVU-LINE1.10 (~SRCLR), UVU-LINE1.16 (VCC), UVU-LINE2.10 (~SRCLR), UVU-LINE2.16 (VCC), UVU-LINE3.10 (~SRCLR), UVU-LINE3.16 (VCC), UVU-MASTER-L1.10 (~SRCLR), UVU-MASTER-L1.16 (VCC), UVU-MASTER-R1.10 (~SRCLR), UVU-MASTER-R1.16 (VCC), XA1.5V1 (5V), XA1.5V3 (5V), XA1.5V4 (5V)
VUL1-0: UVU-LINE1.15 (QA), VUL1D1.2 (A)
VUL1-1: UVU-LINE1.1 (QB), VUL1D2.2 (A)
VUL1-2: UVU-LINE1.2 (QC), VUL1D3.2 (A)
VUL1-3: UVU-LINE1.3 (QD), VUL1D4.2 (A)
VUL1-4: UVU-LINE1.4 (QE), VUL1D5.2 (A)
VUL1-5: UVU-LINE1.5 (QF), VUL1D6.2 (A)
VUL1-6: UVU-LINE1.6 (QG), VUL1D7.2 (A)
VUL1-7: UVU-LINE1.7 (QH), VUL1D8.2 (A)
VUL2-0: UVU-LINE2.15 (QA), VUL2D1.2 (A)
VUL2-1: UVU-LINE2.1 (QB), VUL2D2.2 (A)
VUL2-2: UVU-LINE2.2 (QC), VUL2D3.2 (A)
VUL2-3: UVU-LINE2.3 (QD), VUL2D4.2 (A)
VUL2-4: UVU-LINE2.4 (QE), VUL2D5.2 (A)
VUL2-5: UVU-LINE2.5 (QF), VUL2D6.2 (A)
VUL2-6: UVU-LINE2.6 (QG), VUL2D7.2 (A)
VUL2-7: UVU-LINE2.7 (QH), VUL2D8.2 (A)
VUL3-0: UVU-LINE3.15 (QA), VUL3D1.2 (A)
VUL3-1: UVU-LINE3.1 (QB), VUL3D2.2 (A)
VUL3-2: UVU-LINE3.2 (QC), VUL3D3.2 (A)
VUL3-3: UVU-LINE3.3 (QD), VUL3D4.2 (A)
VUL3-4: UVU-LINE3.4 (QE), VUL3D5.2 (A)
VUL3-5: UVU-LINE3.5 (QF), VUL3D6.2 (A)
VUL3-6: UVU-LINE3.6 (QG), VUL3D7.2 (A)
VUL3-7: UVU-LINE3.7 (QH), VUL3D8.2 (A)
VUMASL-0: UVU-MASTER-L1.15 (QA), VUMASLD1.2 (A)
VUMASL-1: UVU-MASTER-L1.1 (QB), VUMASLD2.2 (A)
VUMASL-2: UVU-MASTER-L1.2 (QC), VUMASLD3.2 (A)
VUMASL-3: UVU-MASTER-L1.3 (QD), VUMASLD4.2 (A)
VUMASL-4: UVU-MASTER-L1.4 (QE), VUMASLD5.2 (A)
VUMASL-5: UVU-MASTER-L1.5 (QF), VUMASLD6.2 (A)
VUMASL-6: UVU-MASTER-L1.6 (QG), VUMASLD7.2 (A)
VUMASL-7: UVU-MASTER-L1.7 (QH), VUMASLD8.2 (A)
VUMASR-0: UVU-MASTER-R1.15 (QA), VUMASRD1.2 (A)
VUMASR-1: UVU-MASTER-R1.1 (QB), VUMASRD2.2 (A)
VUMASR-2: UVU-MASTER-R1.2 (QC), VUMASRD3.2 (A)
VUMASR-3: UVU-MASTER-R1.3 (QD), VUMASRD4.2 (A)
VUMASR-4: UVU-MASTER-R1.4 (QE), VUMASRD5.2 (A)
VUMASR-5: UVU-MASTER-R1.5 (QF), VUMASRD6.2 (A)
VUMASR-6: UVU-MASTER-R1.6 (QG), VUMASRD7.2 (A)
VUMASR-7: UVU-MASTER-R1.7 (QH), VUMASRD8.2 (A)

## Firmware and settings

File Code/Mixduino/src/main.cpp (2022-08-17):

#include "BREncoder.hpp"
#include "PotKit.h"
#include "components_def.h"
#include "deck.hpp"
#include "md_controller.h"
#include "md_init.h"
#include "md_input.hpp"
#include "md_mixer.hpp"
#include "md_pad.hpp"
#include "md_touch.hpp"
#include "midi_map.h"
#include <Arduino.h>
#include <MIDI.h>
#include <Thread.h>
#include <ThreadController.h>


// Rev5 version
MIDI_CREATE_DEFAULT_INSTANCE();

PotKit pots;

ThreadController cpu;     // thread master, onde as outras vao ser adicionadas
Thread threadReadPots;    // thread para controlar os pots
Thread threadReadButtons; // thread para controlar os botoes

void sendMidiNoteOn(uint8_t number, uint8_t value, uint8_t channel);

MDMixer mixer(mixer_notes, sendMidiNoteOn);

Deck deckA(deck_A_notes, sendMidiNoteOn, true);
Deck deckB(deck_B_notes, sendMidiNoteOn, true);
Deck deckC(deck_C_notes, sendMidiNoteOn, false);

Pad padA(pad_A_notes, sendMidiNoteOn, true);
Pad padB(pad_C_notes, sendMidiNoteOn, true);
Pad padC(pad_C_notes, sendMidiNoteOn, false);

void changeDeck();

void handleControlChange(uint8_t channel, uint8_t number, uint8_t value);
void handleNoteOn(uint8_t channel, uint8_t number, uint8_t value);
void handleEvent(uint8_t component_id, uint8_t value);
void handleEvent(uint8_t channel, uint8_t number, uint8_t value);
void readButtons();
void readPots();
void readTouchBars();
void sendMidiCC(uint8_t number, uint8_t value, uint8_t channel);

void setup() {
  // Serial.begin(31250);
  MD::initPins();
  MIDI.setHandleControlChange(handleControlChange);
  MIDI.setHandleNoteOn(handleNoteOn);

  MIDI.begin(MIDI_CHANNEL_OMNI);
  MIDI.turnThruOff();
  pots.begin();
  // Set Deck B Focus
  // MIDI.onNoteOn(1, 127, 9);

  /////////////////////////////////////////////
  // threads
  // pots
  threadReadPots.setInterval(10);
  threadReadPots.onRun(readPots);
  cpu.add(&threadReadPots);

  // buttons
  threadReadButtons.setInterval(20);
  threadReadButtons.onRun(readButtons);
  cpu.add(&threadReadButtons);
}

void loop() {
  cpu.run();
  MIDI.read();
  MDEncoder::read(sendMidiCC);
  MDTouch::read(sendMidiCC);
}

void handleControlChange(uint8_t channel, uint8_t number, uint8_t value) {
  // MDFeedback::onCChange(channel, number, value);
  handleEvent(channel, number, value);
}

void handleNoteOn(uint8_t channel, uint8_t number, uint8_t value) {
  handleEvent(channel, number, value);
}

void changeDeck() {
  deckB.changeState();
  deckC.changeState();
  padB.changeState();
  padC.changeState();
}

void readButtons() { MDInput::read(handleEvent); }

void readPots() { pots.read(sendMidiCC); }

void sendMidiNoteOn(uint8_t number, uint8_t value, uint8_t channel) { MIDI.sendNoteOn(number, value, channel); }

void sendMidiCC(uint8_t number, uint8_t value, uint8_t channel) { MIDI.sendControlChange(number, value, channel); }

inline void handleEvent(uint8_t comp, uint8_t value) {
  switch (comp) {
    /** Mixer browser fx*/
  case 12 ... 26:
    mixer.handleEvent(comp, value);
    break;

  case 27:
    padA.changeMode(Location::Left);
    break;

  case 28 ... 31:
    deckA.handleEvent(comp, value);
    break;

  case 32: {
    padB.changeMode(Location::Right);
    padC.changeMode(Location::Right);
  } break;

  case 33 ... 40:
    deckB.handleEvent(comp, value);
    deckC.handleEvent(comp, value);
    break;

  case 41 ... 48:
    padA.handleEvent(comp, value);
    break;

  case 49 ... 56:
    padB.handleEvent(comp, value);
    padC.handleEvent(comp, value);
    break;

  default:
    break;
  }
}

inline void handleEvent(uint8_t channel, uint8_t number, uint8_t value) {
  switch (number) {
  case 13 ... 26:
    mixer.handleEvent(channel, number, value);
    break;

  case 28 ... 31:
    deckA.handleEvent(channel, number, value);
    break;

  case 33 ... 36:
    deckB.handleEvent(channel, number, value);
    break;

  case 37 ... 40:
    deckC.handleEvent(channel, number, value);
    break;

  case 41 ... 48:
    padA.handleEvent(channel, number, value);
    break;

  case 49 ... 56:
    padB.handleEvent(channel, number, value);
    break;

  case 57 ... 64:
    padC.handleEvent(channel, number, value);
    break;

  default:
    break;
  }
}

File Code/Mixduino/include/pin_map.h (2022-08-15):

#pragma once

#include <Arduino.h>


//////////////////////////////////////
// BUTTONS
const uint8_t SWFXR_2 = 4;
const uint8_t SWFXR_3 = 5;
const uint8_t SWFXL_1 = 8;
const uint8_t SW_BROWSER_R = 7;
const uint8_t SW_BROWSER_L = 10;
const uint8_t SWFXL_2 = 9;
const uint8_t SWFXL_3 = 11;
const uint8_t SWFXR_1 = 12;
const uint8_t SWBR_PREVIEW = 14;
const uint8_t SWBR_BACK = 15;

const uint8_t ard_sw_pins[] = {
    SWFXL_3,
    SWFXL_2,
    SWFXL_1,
    SWFXR_3,
    SWFXR_2,
    SWFXR_1,
    SW_BROWSER_R,
    SW_BROWSER_L,
    SWBR_BACK,
    SWBR_PREVIEW
};

const uint8_t t_ard_sw = 10;

const uint8_t L_BROWSER_A = 2;
const uint8_t L_BROWSER_B = 3;
const uint8_t NP_DATA = 6;
const uint8_t L1VU_LATCH = 16;
const uint8_t L1VU_SIG = 17;
const uint8_t R_BROWSER_B = 18;
const uint8_t R_BROWSER_A = 19;
const uint8_t MRVU_LATCH = 26;
const uint8_t MRVU_SIG = 28;
const uint8_t MLVU_LATCH = 30;
const uint8_t L2VU_SIG = 31;
const uint8_t MLVU_SIG = 32;
const uint8_t L3VU_SIG = 34;
const uint8_t L3VU_LATCH = 36;
const uint8_t FBL_LATCH = 37;
const uint8_t L2VU_LATCH = 38;
const uint8_t FBL_SIG = 39;
const uint8_t FBR_LATCH = 42;
const uint8_t FBR_SIG = 44;
const uint8_t SRCLK = 52;

//////////////////////////////////////
// MULTIPLEXER

const uint8_t MPLEX_S0 = 47;
const uint8_t MPLEX_S1 = 49;
const uint8_t MPLEX_S2 = 40;
const uint8_t MPLEX_S3 = 53;
const uint8_t t_pots_datapin = A1;
const uint8_t r_mux_datapin  = A2;
const uint8_t l_mux_datapin  = A3;
const uint8_t b_pots_datapin = A4;

//////////////////////////////////////
// POTS ANALOG PINS

const uint8_t PFXR_1 = A0;
const uint8_t PMASTER = A14;

const uint8_t aPotsSet[] = {
    PFXR_1,
    PMASTER};

const uint8_t nAPots = 2;

const uint8_t mux_pins_arr[] = {
    MPLEX_S0,
    MPLEX_S1,
    MPLEX_S2,
    MPLEX_S3
};

const uint8_t t_muxpins = 4;


const uint8_t in_pins[] = {
  SWFXR_2,
  SWFXR_3,
  SWFXL_1,
  SW_BROWSER_R,
  SW_BROWSER_L,
  SWFXL_2,
  SWFXL_3,
  SWFXR_1,
  SWBR_PREVIEW,
  SWBR_BACK,
  r_mux_datapin,
  l_mux_datapin
};



const uint8_t t_in_p = 12;
const uint8_t t_out_p = 20;

const uint8_t out_pins[] = {
    L_BROWSER_A,
    L_BROWSER_B,
    NP_DATA,
    L1VU_LATCH,
    L1VU_SIG,
    R_BROWSER_B,
    R_BROWSER_A,
    MRVU_LATCH,
    MRVU_SIG,
    MLVU_LATCH,
    L2VU_SIG,
    MLVU_SIG,
    L3VU_SIG,
    L3VU_LATCH,
    FBL_LATCH,
    L2VU_LATCH,
    FBL_SIG,
    FBR_LATCH,
    FBR_SIG,
    SRCLK
};

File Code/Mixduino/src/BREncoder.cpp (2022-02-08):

#include "BREncoder.hpp"

namespace MDEncoder
{


Encoder knobLeft(L_BROWSER_A, L_BROWSER_B);
Encoder knobRight(R_BROWSER_A, R_BROWSER_B);

volatile long positionLeft  = -999;
volatile long positionRight = -999; 


void read(void (*scc_func)(uint8_t, uint8_t, uint8_t))
{

  long newLeft, newRight;
  newLeft = knobLeft.read();
  newRight = knobRight.read();

    if (newLeft != positionLeft ) {

      if ((newLeft - positionLeft) > 0)
      {
        scc_func(14, 127, 1);
      }
      else
      {
        scc_func(14, 1, 1);
      }

      positionLeft = newLeft;
    }
    if (newRight != positionRight ) {

      if ((newRight - positionRight) > 0)
      {
        scc_func(14, 127, 1);
      } 
      else
      {
        scc_func(14, 1, 1);
      }

      positionRight = newRight;
    }
}
  
} // namespace MDEncoder

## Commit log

2021-03-16 Schematic housekeeping
    [Traktorino-2021-03-16-13-54-58.sch]
2021-03-24 labels wip
    [Traktorino.sch]
2021-03-24 labelss wip
    [Traktorino.sch]
2021-03-24 labels end
    [Traktorino.sch]
2021-03-24 Labels orientation
    [Traktorino.sch]
2021-03-25 SHIFT REGS
    [Traktorino.sch, shift-registers.sch]
2021-03-26 layout update
    [mk2-qcad-layout.dxf]
2021-03-26 SCHEMA UPD
    [Traktorino.sch, multiplexers.sch, shift-registers.sch]
2021-03-27 multiplexers and vumeters
    [Traktorino.sch, mk2-qcad-layout.dxf, multiplexers.sch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]
2021-03-27 more sheets
    pots
    vumeters
    switchers
    [Traktorino.sch, multiplexers.sch, potenciometers.sch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]
2021-03-28 multiplexers WIP
    [multiplexers.sch]
2021-03-28 change to kicad nightly
    [Traktorino.kicad_sch, multiplexers.kicad_sch, potenciometers.kicad_sch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]
2021-03-28 update elements WIP
    [Traktorino-2021-03-16-13-54-58.sch, Traktorino.kicad_sch, multiplexers.kicad_sch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]
2021-03-30 mod layout
    [Traktorino.kicad_pcb, Traktorino.kicad_sch, mk2-qcad-layout.dxf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]
2021-03-30 Arduino mega retrofit WIP
    [Traktorino.kicad_pcb, Traktorino.kicad_sch, Traktorino.sch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]
2021-03-31 pad footprint updated
    [Traktorino.kicad_pcb, Traktorino.kicad_sch, vumeters.kicad_sch]
2021-04-01 trillbar added
    [Traktorino rev 4-B.Cu.gbr, Traktorino rev 4-B.Mask.gbr, Traktorino rev 4-B.SilkS.gbr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]
2021-04-02 board updated
    [Traktorino.kicad_sch, pad-leds.kicad_sch, shift-registers.kicad_sch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]
2021-04-02 placed 3d model components
    [75mm Straight Slide Potentiometer.step, BOM.csv, EC11B-SW-Vert-20R-blue.step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]
2021-04-04 fixing 3dmodels
    [75mm Straight Slide Potentiometer.step, EC11B-SW-Vert-20R-blue.step, LED D3 - Blue_cutted.step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]
2021-04-11 change few pins and programming
    [Traktorino.kicad_sch, switchers.kicad_sch]
2021-04-13 change code to platformio
    [Traktorino.kicad_sch]
2021-04-23 technical drawing
    [Mixduino-drawing.dxf]
2021-04-24 sr wip
    [Mixduino-drawing.dxf, Mixduino.kicad_pcb, Mixduino.kicad_sch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]
2021-04-26 more routing
    [Ceramic_Capacitor_1206_h32mil.step, Mixduino.kicad_sch, Tactal Switch -THru (6mmx 6mmx5mm)-Black.stp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]
2021-04-27 removed neopixel capacitors
    [Mixduino.kicad_sch, Traktorino-B_Mask.dxf, Traktorino-B_Silkscreen.dxf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]
2021-04-29 neopixels library concept
    [BOM.csv, Mixduino-B_Mask.dxf, Mixduino-B_Silkscreen.dxf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]
2021-04-30 Design mistake fixed
    - changed D0 & D1 pins asign
    - progress on main code
    [Mixduino-B_Mask.dxf, Mixduino-B_Silkscreen.dxf, Mixduino-Edge_Cuts.dxf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]
2021-05-01 mistake fixed
    added another latch pin for feedback leds SReg.
    [Mixduino-F_Silkscreen.dxf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]
2021-05-02 buttons module
2021-05-31 shifter libr to feedback leds
2021-06-05 schematic updated
    [Mixduino.kicad_sch, leds.kicad_sch, multiplexers.kicad_sch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]
2021-06-10 tracking WIP
    [Mixduino.kicad_sch, shift-registers.kicad_sch]
2021-06-12 Rev5 completed
    [Mixduino-B_Mask.dxf, Mixduino-B_Paste.dxf, Mixduino-B_Silkscreen.dxf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]
2021-06-12 hotfix gerbers
    [Mixduino-B_Cu.gbr, Mixduino-B_Mask.gbr, Mixduino-B_Paste.gbr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]
2021-06-12 silkscreen udpated
    [Mixduino-B_Cu.gbr, Mixduino-B_Mask.gbr, Mixduino-B_Silkscreen.gbr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]
2021-06-18 all neopixels together
    [Mixduino-B_Mask.dxf, Mixduino-B_Paste.dxf, Mixduino-B_Silkscreen.dxf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]
2021-06-18 enclosure top
    [top-cover.dxf]
2021-07-29 added draws of 3d model buttons in pcb [WIP]
2021-07-29 position holes for btns
2021-07-29 changed encoders pins to interrupt pins
    [Mixduino-B_Mask.dxf, Mixduino-F_Mask.dxf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]
2021-09-03 adding ics WIP
    [Mixduino.kicad_sch, multiplexers.kicad_sch]
2021-09-04 SCHEMATIC FINISHED
    [BOTTOM-POTS.kicad_sch, MPX-SW-BTNS.kicad_sch, Mixduino.kicad_sch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]
2021-09-04 added transistor and 3x leds play- cue
    [BOTTOM-POTS.kicad_sch, MPX-SW-BTNS.kicad_sch, Mixduino.kicad_sch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]
2021-09-05 routing WIP
    [MPX-SW-BTNS.kicad_sch, Mixduino.kicad_sch, S4B-XH-A-1.step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]
2021-09-05 routes done
    [MPX-SW-BTNS.kicad_sch, Mixduino.kicad_sch]
2021-09-05 shematic pdf and step model board
2021-09-10 user drawings done
    [Mixduino-B_Mask.dxf, Mixduino-B_Paste.dxf, Mixduino-B_Silkscreen.dxf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]
2021-09-11 top cover
    [top-cover.dxf]
2021-09-21 routes finished
    [BOTTOM-POTS.kicad_sch, MPX-SW-BTNS.kicad_sch, Mixduino.kicad_sch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]
2021-09-21 update gerbers
    [Mixduino-B_Mask.dxf, Mixduino-B_Paste.dxf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]
2021-09-22 fix gerbers
    [Mixduino-B_Cu.gbl, Mixduino-B_Mask.gbs, Mixduino-B_Paste.gbp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]
2021-09-26 update schematic
    [BOTTOM-POTS.kicad_sch, MPX-SW-BTNS.kicad_sch, Mixduino.kicad_sch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]
2021-09-26 modified trillbar connectors
    [BOTTOM-POTS.kicad_sch, MPX-SW-BTNS.kicad_sch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]
2021-09-26 60mm pot 3dmodel changed
    [60mm_pot.step]
2021-09-28 top-cover updated
    [Mixduino-B_Fab.dxf, Mixduino-B_Mask.dxf, Mixduino-B_Paste.dxf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]
2021-09-29 enclosure freecad model
2021-10-08 Bottom Cover refactored
    [Bottom-Cover-Left.3mf, Bottom-Cover-Right.3mf, Mixduino-bottom-cover.amf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]
2021-10-13 Fixed Buttons Read implementation
    [main.cpp, pin_map.h]
2022-02-08 modularize encoder
2022-08-06 refactor to namespaces
    [Mixduino.csv]
